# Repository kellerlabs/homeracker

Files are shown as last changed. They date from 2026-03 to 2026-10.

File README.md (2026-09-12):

[📚 What's it for?](#-use-cases) | [⚙️ How does it work?](#-features) | [🌐 Free & OpenSource](#-open-specs) | [🤝 Contributing](CONTRIBUTING.md)

What is HomeRacker - YouTube video (https://youtu.be/g8k6X_axYug)

HomeRacker is a fully modular 3D-printable rack-building system for virtually any “racking needs” (server rack, shoe rack, bookshelf, you name it).

You can find all parametric and non-parametric models, as well as the `.f3d` files (like the `HomeRacker - Core`), on [Makerworld](https://makerworld.com/en/@kellerlab).

The parametric models are available in the [HomeRacker GitHub Repository](https://github.com/kellerlabs/homeracker/tree/main/models).

> 💡 **Note**
> The basic HomeRacker system is also referred to as `HomeRacker - Core`. Free for everyone to use, remix, and reshare.

# 📑 Table of Contents
- [🔧 Use Cases](#-use-cases)
- [✨ Features](#-features)
  - [⚙️ How it works](#%EF%B8%8F-how-it-works)
    - [🛠️ Assembly Basics](#%EF%B8%8F-assembly-basics)
    - [💡 Assembly Tips](#-assembly-tips)
    - [🖨️ Printing Tips](#%EF%B8%8F-printing-tips)
- [📐 Tech Specs](#-tech-specs)
  - [🧱 Supports](#-supports)
  - [🔗 Connectors](#-connectors)
  - [📏 Lock Pins](#-lock-pins)
  - [🌍 Open Specs](#-open-specs)
- [💬 Community](#-community)
- [❓ Why the name?](#-why-the-name)
- [📜 Licensing](#-licensing)
- [🤝 Contributing](CONTRIBUTING.md)
- [🛠️ Developer Tools](#%EF%B8%8F-developer-tools)
- [🚀 Releases](#-releases)
- [🧪 Tests](#-tests)
  - [⚠️ Disclaimer](#%EF%B8%8F-disclaimer)
  - [🔬 How I tested](#-how-i-tested)
- [🏷️ Logo](#%EF%B8%8F-logo)

# 🔧 Use Cases
I created HomeRacker because I was dissatisfied with the existing solutions available online. Many designs were too specific, accommodating only certain devices owned by their creators. Others supported only the 10" standard, with no flexibility for deviations, often requiring additional adapters.

As I began my homelab journey in April 2025, I wanted a modular solution that could adapt and grow with my evolving needs. This would eliminate the need to purchase larger racks or completely change concepts when the original design no longer met my requirements.

xkcd: The General Problem

As it is my nature to overengineer everything, I came up with a more generic solution to serve ANY racking need. Be it a small rack for a few Raspberry Pis, a 10" standard rack for homelabs, or even a 19" standard rack (still working on that though). You can even create bookshelves, shoe racks, or combine all of the above into an abomination of a rack.

To give you an idea of how this may look (10" rack, half-constructed Pi mini-rack, bookshelf):

Real Life Example

Aside from the basic [building blocks](#-tech-specs), the rack above also contains the following parts:

* **10" Rack**
  * [HomeRacker - 10" Rackmount Kit](https://makerworld.com/en/models/1353730-modular-10-server-rack#profileId-1396904) for standard-height units
  * [Raspi 5 Mount Kit](https://makerworld.com/en/models/1324096-pi-5-snapcase-for-homeracker#profileId-1360937):
    * Vertical Mount Adapter for HomeRacker
    * Front panel for 10" racks
  * Rackmount ears for the switch. These are fully customizable rackmount ears I created as an [OpenSCAD file](https://github.com/kellerlabs/homeracker/blob/main/models/rackmount_ears/parts/rackmount_ears.scad). You can customize it directly [here](https://makerworld.com/en/models/1259227-fully-customizable-rackmount-ears#profileId-1283271).
  * [HomeRacker Airflow Kit](https://makerworld.com/en/models/1353730-modular-10-server-rack#profileId-1396904) (currently part of the 10" rack model), which consists of:
    * Front/back panels
    * Side panels
    * Bottom/top panels with air intake/exhaust grids and bores for standard fans (80/92/120mm)

* **Shelf** (Build any shelf configuration you like.)

# ✨ Features

The `HomeRacker - Core` features:

* **Fully modular**: Thanks to the support-connector system, you can scale in any direction. The only limits are material strength and how much money, space, and time you have.
* **3D-printable**: The entire core system is printable, and no tools are required for assembly.
* **No supports needed**: Not a single part of the core system needs printed supports.
* **OpenSource**: Build your own adapters and use the system in personal or commercial projects (see [🌍 Open Specs](#-open-specs) and [📜 Licensing](#-licensing) for details).

## ⚙️ How it works
> **tl;dr** Think of a rack shape you want to build, download the [Core model on MakerWorld](https://makerworld.com/en/models/1317298-homeracker-core) (or customize it there or from [this repo](models/core/)), print it, assemble it, and add your own mounts/adapters/whatever-you-like.

I might post a YouTube video here to show how it works.

### 🛠️ Assembly Basics

Assembly Basics 4 White

Assembly is straightforward and requires no tools:

1. **Prepare the components**: Download the [HomeRacker - Core](https://makerworld.com/en/models/1317298-homeracker-core) (or customize it on MakerWorld / from [this repo](models/core/)), and print all required parts. Clean off any debris.
2. **Connect supports and connectors**: Attach connectors to supports based on your desired configuration.
3. **Secure with Lock Pins**: Use Lock Pins to lock parts in place. They can be inserted horizontally or vertically thanks to their square profile.
4. **Add features**: Attach panels, shelves, and other accessories as needed.

### 💡 Assembly Tips

> 💡 **Pro Tip**: I created a sample [10" Cyberpunk-themed 3D model on MakerWorld](https://makerworld.com/en/models/1353730-modular-10-server-rack#profileId-1396904) for inspiration.

1. Plan ahead! Otherwise, you'll end up with an army of unused parts like me:

   Army of Parts

   Make a parts list, or let the [Configurator](https://homeracker.org/configurator/) count for you:
   * How many supports of what lengths (in `base units`)?
   * How many connectors of each type (pull-throughs, feet, regular)?
   * Print a ton of Lock Pins. You'll need more than you might think. The [Core model](https://makerworld.com/en/models/1317298-homeracker-core) on MakerWorld includes a 100-pin plate and a [Gridfinity](https://gridfinity.xyz/) box for storage.

2. Build layer by layer: Start with the base frame, add vertical supports, then stack intermediate/top frames.
3. Make sure Lock Pins are fully inserted. Gentle force might be needed.

### 🖨️ Printing Tips

1. If bed adhesion is sketchy: Add a brim to the supports. The small contact surface on connectors can cause print failures.
2. Prevent warping: Keep the print bed clean and oil-free. Even a fingerprint can cause issues.
3. When printing new filament: Make sure to calibrate the material flow!
> 💡 **Pro Tip**: If you need to disassemble and the pin is stuck, push it from the other side with another pin to release it.

## 📐 Tech Specs

> 💡 **Note** - For actual dimensions, check out the original Fusion `.f3d` files on Makerworld. All designs are fully parameterized for easy scaling.

The system is based on 4 core measurements:

1. **15mm**: The `base_unit`. Each support has 15mm x/y dimensions, with z being a multiple of 15mm.
2. **4mm**: Side length of Lock Pins and matching holes.
3. **2mm**: Wall thickness of connectors.
4. **0.2mm**: Tolerance added to connector interiors for print/material variances.

> These values (except tolerance) are arbitrary and just made sense during design.

### 🧱 Supports

Supports are the structural spine of HomeRacker.

Core Support 3D Transparent

Height is a multiple of 15mm (base units). E.g.: A 3-unit support = 45mm tall, a 17-unit = 255mm.

Each unit height includes a 4mm hole for a Lock Pin.

* Holes match Lock Pin dimensions (no tolerance).
* Holes are convex on x and z axes for multi-directional insertion.

Schematics:

**Front View**
Support Front View

**Side View**
Support Side View

**Top View**
Support Top View

### 🔗 Connectors

Connectors join supports in 1 to 3 dimensions. From straight extenders to 6-way junctions.

3D Shot of All Connectors

Types:
* **Standard**: Solid center; best for load-bearing.
* **Pull-Through**: Open center for complex builds (e.g. 10" rack).
* **Feet**: Solid end pieces; used as rack feet.

> ❗ **Important**
> Connector centers are always 1 `base_unit` in height. No offsets, no fluff.
> So: 2 × 3-unit supports + 1 connector = exactly 7 base units (105mm).

Schematics:

**Top View, Outer**
Connector Outer Measurements

**Top View, Inner**
Connector Inner Measurements

### 📏 Lock Pins

Lock Pins hold the system together.

Lock Pin 3D

They rely on tension from their convex shape to stay in place.

Schematics:

**Top View**
Lock Pin Top

**Side View**
> Don't ask why the height is 3.791mm, it works. I left it as-is.

Lock Pin Side

> I may tweak the pin grip in future versions to make it easier to pull out again. But the base dimensions will remain the same for compatibility.

> 💡 **Tip**: Pulling out Lock Pins one at a time can be tedious. Check out the [Pinpusher](models/pinpusher/), a tool designed to push Lock Pins back out quickly, especially when removing several at once.

## 🌍 Open Specs

I created `HomeRacker - Core` to be an open spec that any maker can build on, with (almost) no strings attached. (See [📜 Licensing](#-licensing) for more.)

I encourage you to make your own models based on HomeRacker! Let me know, and I’ll feature your work on this page and cross-link it on Makerworld (subject to my "very objective" approval 😄). Just [create an issue](https://github.com/kellerlabs/homeracker/issues/new) if you want to be featured.

> 💡 **Want to contribute new features or extensions?**
> Head over to the [HomeRacker Community Repository](https://github.com/kellerlabs/homeracker-community)!
> This core repo focuses on the base system and accepts primarily bugfixes. New modules, adapters, and creative extensions live in the community repo.

# 💬 Community

Got questions? Want to share your builds? Join the HomeRacker community!

- **🐙 [Community Repo](https://github.com/kellerlabs/homeracker-community)**: Contribute new features, extensions, and modules
- **💬 [Discord](https://discord.gg/b6myzHRxc3)**: Chat with me and other builders, get help, share ideas
- **🎥 [YouTube](https://www.youtube.com/@kellerlabs)**: Watch build guides, tutorials, and project updates
- **🖨️ [Makerworld](https://makerworld.com/@kellerlab)**: Grab ready-to-print models and remixes

Whether you're just starting out or have a wild idea for a custom rack, I'd love to hear from you. The HomeRacker community is all about sharing knowledge and helping each other build cool stuff!

# ❓ Why the name?

After ~4 hours of research, I found all my original ideas (UniRack, OpenRack, etc.) were taken.

So, "HomeRacker" was born, part practical, part tongue-in-cheek. It fits the homelab theme, but also hints at the "home-wrecking" time sink this can become.

# 📜 Licensing

> 💡 **tl;dr**
> Use it for ANY purpose (even commercial), but credit me and share alike!

* Source code: `MIT License` ([LICENSE](https://github.com/kellerlabs/homeracker/blob/main/LICENSE))
* 3D models & creative assets (`/models/`): `CC BY-SA 4.0 License` ([/models/LICENSE](https://github.com/kellerlabs/homeracker/blob/main/models/LICENSE))

These licenses apply to all models in this repository (Core, Gridfinity, Rackmount Ears, Wall Mount, Pinpusher, etc.).

> ❗ **Important**
> Other models I publish may have more restrictive licenses. This will be stated clearly on Makerworld.

HomeRacker is an unregistered trademark of Patrick Pötz, first used publicly on 12.04.2025.

# 🛠️ Developer Tools

HomeRacker includes custom tooling to streamline development:

- **[scadm](cmd/scadm/README.md)** - OpenSCAD + library dependency manager
  - Zero-dependency Python package for installing OpenSCAD (nightly/stable) and libraries
  - Cross-platform: Windows, Linux, macOS (might work, dunno)
  - Install: `pip install scadm` → `scadm`
  - Manages dependencies from `scadm.json`

- **[Setup OpenSCAD Action](.github/actions/setup-openscad/README.md)** - Reusable GitHub Action for CI
  - Installs OpenSCAD, system dependencies, and libraries in one step
  - Uses scadm under the hood, with caching for fast runs
  - Usage: `uses: kellerlabs/homeracker/.github/actions/setup-openscad@setup-openscad-v1`

- **[Style Guide](docs/styleguide.md)** - colours from `constants.scad`, Orbitron Black + Source Code Pro, layout rules

- **[Site](site/README.md)** - homeracker.org, built by Astro from the READMEs in this repo
  - Home page, model catalog and model pages come straight from `README.md` and `models/*/README.md`
  - Relative links and render images are resolved at build time

- **[Configurator](configurator/README.md)** - Web-based rack planner with parts list
  - Define a rack, preview it, copy the bill of materials
  - Live at [homeracker.org/configurator](https://homeracker.org/configurator/)

- **[Renovate Preset](renovate-dependencies.json)** - Automated dependency updates
  - Tracks OpenSCAD versions, GitHub releases, and Python packages
  - Custom rules for this project's specific needs
  - Extend in your project: `"extends": ["github>kellerlabs/homeracker:renovate-dependencies"]`

See [CONTRIBUTING.md](CONTRIBUTING.md) for setup instructions.

# 🚀 Releases

Releases are fully automated:

- **Automated versioning**: Follows [Semantic Versioning](https://semver.org/) based on [Conventional Commits](https://www.conventionalcommits.org/)
- **Changelog generation**: Automatically generated from commit messages
- **Release schedule**: Weekly auto-merge of release PRs (Mondays) or manual trigger
- **GitHub releases**: Tagged releases with changelog and version information
- **PR validation**: Pull request titles are validated to ensure Conventional Commits compliance

The release automation is powered by [Camunda's infra-global-github-actions](https://github.com/camunda/infra-global-github-actions/tree/main/teams/infra/pull-request).

To contribute and trigger releases, use conventional commit messages. See [CONTRIBUTING.md](CONTRIBUTING.md#-commit-conventions) for details.

# 🧪 Tests

Of course I tested stuff... It took ~4 months from idea to this release. Look at all the prototypes:
Photo showing a variety of HomeRacker prototypes lined up

## ⚠️ Disclaimer

> ⚠️ **Warning**
> This project is provided “as is,” without any warranty. Use at your own risk. I’m not responsible for damage, injury, or loss caused by using this system or its parts.

Aside from the scary warning above, I need to mention, that due to the high modularity of this system combined with limited time and resources I was of course not able to test every combination of filaments, printers, print-settings, room conditions (temperature, humidity) or to do extensive load-bearing tests.

What I want to say: I feel like the model turned out to be really nice and versatile. That's why I shared it in the first place. But since I do not have control over the manufacturing conditions of any consumer of this model, I cannot give any guarantees on how your specific print will turn out in the end. There are just too much variables which not even the best model design can compensate for. (Writing this feels a bit like an upfront apology... seems like I'm a people pleaser)

## 🔬 How I tested
My setup is as follows:
* a room temperature between 17 and 25°C
* Humidity levels between 29% and 36% (depends on when I'm doing my laundry)
* A BambuLab X1C printer
* Exclusively BambuLab filament (haven't tried others yet)
  * PLA Matte (I love the charcoal color. Looks so silky)
  * PLA Basic
  * ABS
* mostly I used the Textured PEI plate. It just works (provided you regularly clean it using Isopropyl alcohol). For the rest of the time I tried out the Cold Plate Super Track (it's nice but very hard to get your prints off the plates when it cools)

All above's filament types can be be combined in any possible way (just make sure you do flow calibration before using new filaments. First ABS print turned out horribly just because I forgot to click the calibration checkbox). E.g.: you could print a connector in ABS, a support in PLA Matte and a Lock Pin in PLA and they will just fit when being assembled.

> 🛠️ **Btw:** I am not affiliated with Bambu in any way besides uploading my models to MakerWorld and occasionally making use of their Exclusive Model program. But they don't pay me for naming their products anywhere else (I wish 😉).

# 🏷️ Logo
This logo will also be used as an overlay image for the thumbnails of all my 3D models that are compatible with HomeRacker. I encourage you to do the same if you create models for HomeRacker. That way, it’ll be immediately visible to users that a model is designed to be mounted on a HomeRacker system. I also svg'ed this logo [here](https://raw.githubusercontent.com/kellerlabs/assets/main/homeracker/img/homeracker_logo.svg) and [here](https://raw.githubusercontent.com/kellerlabs/assets/main/homeracker/img/homeracker_logo_single_color.svg).

HomeRacker Logo

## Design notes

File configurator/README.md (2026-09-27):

# 🧮 Configurator

## 📌 What

Browser-only rack configurator published at <https://homeracker.org/configurator/>. Define a rack as a stack of rows (each with an optional name, its own height, column widths and whether its posts continue from the row below), set depth and feet, close individual openings with panels (in to-scale face drawings or by clicking them in the 3D view), preview it, and get the parts list to print. The config lives in the URL hash, so a link is a saved rack; the Copy link button puts it on the clipboard. A printer section holds your print volume (default 256 mm cubed, kept in the browser, not in the link); parts that do not fit it are marked in the parts list and drawn red in the 3D view, without blocking anything else.

## 🤔 Why

The README's first assembly tip is "make a parts list". This does the counting, and it encodes the geometry rules once, next to the models they mirror.

## 🔧 How

```sh
cd configurator
npm ci
npm run dev      # local dev server
npm run check    # eslint + tsc + vitest
npm run build    # static bundle in dist/, served under /configurator/
```

### Structure

| Path | Purpose |
|---|---|
| `src/engine/` | Pure geometry + parts list. No DOM, no Three.js (enforced by `tsconfig.engine.json` and eslint) |
| `src/engine/orientation.ts` | Finds which of the 24 cube rotations maps a canonical connector mesh onto a node (pure, tested) |
| `src/engine/pins.ts` | Lock pins of the frame: which hole of the support a pin follows, which side it goes in from, and where a panel corner bracket makes it an extended one (pure, tested) |
| `src/engine/printer.ts` | Print bed check: every parts-list line carries the bounding box of one part in mm; `unprintable()` lists the lines that fit no axis-aligned orientation of the bed |
| `src/render/` | `meshes.ts` draws real part meshes from the exported library (connectors per type and pull-through axis, supports per length, lock pins, feet); `layout.ts` + `build.ts` are the schematic box fallback; `scene.ts` picks one; `viewcube.ts` + `viewcubeGeometry.ts` (both pure and tested) + `viewcubeGizmo.ts` are the orientation cube |
| `src/app.ts` | `mountConfigurator(root)`: builds the controls, stage and parts list inside any element |
| `src/configurator.css` | Component styles; reads the site design tokens, falls back to matching values standalone |
| `src/engine/diagrams.ts` | To-scale elevations and plans of every face and frame for the panel drawings (pure, tested) |
| `src/ui/` | Row editor (height, shift, column widths with negative widths for gaps, posts continue from below), panel drawings (click a rectangle to cycle open, inter-fit, full cover; one figure per face plus one per gap; the three squares next to a drawing set all of its openings; hover syncs with the 3D view), parts-list table, URL hash sync |
| `tests/` | Vitest; `fixtures.ts` holds the worked examples. Browser journeys live in [`site/e2e/`](../site/e2e/), see [TESTING.md](../TESTING.md#site-and-configurator-e2e-tests) |

### Geometry rules

- 1 unit = 15 mm (`BASE_UNIT`). Connector cores are 1 unit; a support between nodes `a < b` has length `b - a - 1`.
- A rack is a stack of rows, bottom to top. Each row has a height (its vertical support length), a list of column widths (bay support lengths, left to right; each divider between bays is one unit of connector core), a shift (units to the right of x = 0) and a `through` flag: when set, the posts of the row below continue through the frame under this row (pull-through connectors there, one long support) instead of ending in a standard connector. Depth is shared.
- A column width may be written negative: that is a **gap**, taking the same space as a bay of that width but carrying no beam above it. It is what builds a U, a row of `6, 10, 6` under a row of `6, -10, 6` gives two towers with the space between them open to the top. The posts on both flanks of a gap stand as they would for a bay, and a beam under a gap survives when a bay of the row below spans the same place. The beam above a gap never comes back: stacking another row on the U leaves the gap open and that row keeps its own top beam, so a gap cannot be bridged from above. A gap has no bay, so no front or back panel; the walls it exposes become the left and right openings of the row's segments (the runs of bays on either side), drawn in their own `Gap in <row>` figure. Because those openings are indexed by segment ordinal, editing a gap into an existing row can move a left or right panel to a different wall (a saved link has no gap, so its indices never shift under it). A gap may sit anywhere in a row, including at either end, where it takes away the beam above its own columns and nothing else; a gap at the end exposes one wall rather than a facing pair, so it gets no figure of its own and that wall shows in the side elevation instead. A rack whose parts end up joined by nothing, a U standing on the floor, with no row spanning under its gap, is reported under the rows, without blocking anything else.
- Frames sit between rows and get a connector at every column boundary of the row below and the row above; beams are split there, so a divider that stops ends in a T connector. Vertical posts run at every column boundary of their own row. Rows can differ in width and position (stepped racks).
- Two connectors need at least 2 units of support between them, because each connector arm wraps one unit of the support. Depth, row heights and column widths are therefore 2..50, and a frame beam shorter than 2 units (dividers of neighbouring rows landing 2 units apart) is reported under the rows, drawn red in the 3D view and marked in the parts list, without blocking the rack.
- Outer size is the widest row by `depth + 2` by the sum of `height + 1` over rows, plus 1.
- Connector type = (axes used, arm count) as in `CONNECTOR_CONFIGS`. A through junction makes its nodes z pull-through.
- Supports carry lock pin holes on both axes (`x_holes=true`), because a panel bracket needs the hole across the face it lies on, and the parts list asks for them that way. See [x-hole supports by default](../docs/decisions/x-hole-supports-by-default.md).
- One lock pin per occupied arm, the floor arms included: a foot plugs into its arm like a support and is locked the same way. A pin is pushed in from the inside of the rack, so the grip stays clear of panels, and runs vertically through a beam and front to back through a post unless a panel corner bracket wants the other hole of that cell. The two holes of a cell cross in its middle, so only one of them can take a pin: it goes to the axis that holds the most brackets, which leaves the odd corner where a front and a side panel meet pinned for one of the two. A pin whose hole carries a bracket is an extended one: the neck when the bracket is on the side the pin goes in from, the tail when it is on the far side, both when a panel hangs on either side (`src/engine/pins.ts`).
- Panels close openings. Every row has front and back openings per column and one left and one right opening per segment; every frame (bottom, each shelf between rows, top) has one horizontal opening per span between its nodes, so exposed roofs of a wider lower row and shelves inside the rack can be panelled too. A panel fills its opening exactly: `units_x = support length` (from the inter-fit deduction in `panel.scad`). Openings need at least 2 units per side to take a panel (the model asserts that); the upper bound is the support length. A front or back bay whose top or bottom edge carries a connector between its corners (the divider of a neighbouring row ending in a T there) cannot take a standard panel either: the panel model runs its mount plates and contour walls along the whole edge, and a connector core stands 2.1 mm proud of the support into that space. Such openings are hatched in the drawings and skipped by the whole-face shortcuts. A panel that still lands on an opening no standard part fits (from an older link, or after a row was resized) never blocks the rack: it is drawn in the warning colour in the drawing, the parts list and the 3D view, and a click on it removes it. Panels beyond the Customizer slider range of 16 units get a note in the parts list: type the units into the Customizer or print them split. Panel lock pins are an estimate, one per mount plate hole, and are listed separately; the corners are held by the frame pins that carry the extension for it.
- URL hash: `v=4&d=<depth>&r=<height>:<w>.<w>[~shift][*]_<row>...&f=<feet>&pn=<f|b|l|r|h><at>.<index><i|f>_...&n<row>=<name>` where a negative `<w>` is a gap, `*` marks a row whose posts continue from below, `at` is the row index (vertical faces) or frame index (horizontal), and `n0`, `n1`, ... carry optional row names (up to 40 characters). Version 3 links (one post mode for the whole rack), version 2 links (one panel type per face) and version 1 links (single column, level positions) still open.

### Preview

An orientation cube sits in the top right corner of the stage, the way CAD software shows one. It turns with the model so the face you are looking at is always named, using the same names as the face drawings: `FRONT` is -y, `RIGHT` is +x, `TOP` is +z. Its corners are chamfered off, so it is fourteen real facets: six labelled octagons and eight corner triangles, one per view it offers. That makes the corners visible as targets from any angle, including head on to a face, and it makes the hit test exact, the ray reports the facet it struck, with no guessing from how close to an edge it landed. Hovering lights that one facet, and clicking swings the camera to its view, keeping the current target and distance, so a corner gives the usual 3/4 isometric. The top and bottom views are tipped a hair towards the front, because looking exactly down the up axis leaves an orbit camera's azimuth undefined. The cube is drawn in a scissored corner of the same WebGL canvas, so it costs no second context and cannot drift out of step with the camera.

The 3D preview uses the part meshes exported by `site/scripts/export-parts.mjs` (served under `/parts/`; the standalone app serves `../site/public` too). Every connector is placed with the rotation from `orientation.ts`, lock pins sit in every occupied arm the way the geometry rules describe, feet plug into the floor arms. Panels are parametric in two dimensions, so each one is assembled the way `panel()` in `panel.scad` assembles it: a plate (inter-fit turned around, lying against the inside of the frame with its mounts reaching back out to the plane of the opening; full cover overlapping the supports by half a unit and standing one connector wall proud of them so it covers the connectors) plus real exported meshes of the support mount plate for that edge length and the corner bracket, placed with the same spins as the OpenSCAD module. The kit is exported from `site/scripts/scad/panel_kit.scad`. Without the mesh library the preview falls back to schematic boxes.

Worked example (defaults): depth 6, rows 5 and 4 high with one 6-unit column, feet on, segmented posts gives 12 x 6u + 4 x 5u + 4 x 4u supports, 8 x 3D4W + 4 x 3D3W connectors, 44 lock pins, 4 feet. Splitting the bottom row into two 4-unit columns adds a post, two T connectors (3D5W and 3D4W) and two feet.

> ⚠️ The panel sizing rule is derived from the library source, not yet verified on a print. If a panel is off by one unit, fix `panelSize()` in `src/engine/panels.ts` and its test.

### Deploy

The [site](../site/README.md) mounts this app on its `/configurator/` page by importing `src/app.ts` and `src/configurator.css` directly, so the deployed configurator shares the site's navigation, fonts and colours. `npm run build` here still produces a standalone bundle for local use; `index.html` is that shell.

## 📚 References

- [web-configurator-on-github-pages](../docs/decisions/web-configurator-on-github-pages.md): decision record
- [HomeRacker core](../models/core/README.md): supports, connectors, lock pins
- [Panels](../models/panel/README.md), [Feet](../models/foot/README.md)

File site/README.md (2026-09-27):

# 🌐 Site

## 📌 What

The homeracker.org website: an Astro static site that renders the repository's own markdown (the root `README.md`, `models/README.md`, and every `models/*/README.md`) into a themed site, with the [configurator](../configurator/README.md) mounted at `/configurator/`.

## 🤔 Why

The README stays the single source of truth. The site adds navigation, a model catalog with the tracked render PNGs, a live preview of the system on the home page, and a visual identity built from HomeRacker's own constants: the 15 mm unit as a lattice, the brand yellow as the one accent.

## 🔧 How

```sh
cd site
npm ci
npm run dev      # local dev server with live reload
npm run check    # astro check + vitest
npm run build    # static site in dist/
npm run e2e      # Playwright against dist/, see TESTING.md
```

`npm run build` first runs `scripts/export-parts.mjs`, which needs OpenSCAD (`scadm install` puts it in `bin/openscad/`, or set `OPENSCAD`). Without it the script warns, the build continues, and the hero shows the schematic rack instead. CI sets `PARTS_REQUIRED=1` so a missing OpenSCAD fails the build there.

Astro caches rendered markdown in `.astro/`. After changing the rehype transforms in `src/lib/`, run `npx astro build --force` so cached README renders are regenerated.

### Structure

| Path | Purpose |
|---|---|
| `src/content.config.ts` | Content collections: `docs` (root + models index) and `models` (one entry per `models/*/README.md`) |
| `src/lib/links.ts` | Rewrites relative markdown links to site routes, or to GitHub when the site has no page for the target |
| `src/lib/sections.ts` | Wraps each heading block in a `<section>` so the theme can lay out README sections; drops the GitHub table of contents |
| `src/lib/catalog.ts` | Builds catalog cards from `models/README.md` |
| `src/lib/hero.ts` | Home page hero: the exploded 3D3W cube (8 connectors, 12 supports, 24 lock pins) built from real part meshes, assembling and coming apart in a loop; still exploded view under reduced motion |
| `src/lib/rack.ts` | Fallback hero when no part meshes are present: the default configurator rack as schematic boxes |
| `scripts/e2e-report.mjs` | Turns the Playwright JSON results into the job summary and the PR comment on E2E failures |
| `scripts/export-parts.mjs` | Exports the part library with OpenSCAD into `public/parts/` (gitignored): every connector type and pull-through variant, supports from 1 to 50 units, the lock pin, the foot, and the panel kit (support mount plates for 3 to 50 units and corner brackets, both panel types) from `scripts/scad/panel_kit.scad`. Used by the hero and by the configurator preview |
| `src/pages/` | `index.astro` (README), `models/index.astro` (catalog), `models/[slug].astro` (model pages), `configurator.astro` (mounts the configurator app) |
| `e2e/` | Playwright suite: page smoke tests, configurator journeys, and the control inventory. See [e2e.md](../.claude/rules/e2e.md) |
| `src/styles/global.css` | Design tokens, the type system from [docs/styleguide.md](../docs/styleguide.md) (Orbitron Black for headings, Source Code Pro for everything else) and markdown styling |

### Writing docs that render well

- Relative links between READMEs (`../core/README.md`, `models/panel/README.md`) become site links automatically. Links to anything else in the repo go to GitHub.
- Relative images under `parts/renders/` are optimized by Astro at build time. Images from `kellerlabs/assets` are loaded as-is.
- Model pages take their table of contents from the `##` headings.

### Deploy

`.github/workflows/pages.yml` installs both packages, builds this site (which bundles the configurator page), and deploys `site/dist` with `actions/deploy-pages`. The repository's Pages source must be set to **GitHub Actions**; the custom domain comes from `public/CNAME`.

## 📚 References

- [astro-site-replaces-jekyll](../docs/decisions/astro-site-replaces-jekyll.md): decision record
- [web-configurator-on-github-pages](../docs/decisions/web-configurator-on-github-pages.md)
- [e2e-test-site-and-configurator-with-playwright](../docs/decisions/e2e-test-site-and-configurator-with-playwright.md)
- [Astro content collections](https://docs.astro.build/en/guides/content-collections/)

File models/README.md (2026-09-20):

# 📦 Models

This folder contains all `scad` 3D models which come with the HomeRacker project.

## 📑 Contents

### 🧱 Core

The fundamental HomeRacker building system with modular components:

- **Supports**: Vertical and horizontal structural elements
- **Connectors**: Join supports in a variety of dimensions
- **Lock Pins**: Secure connections without tools

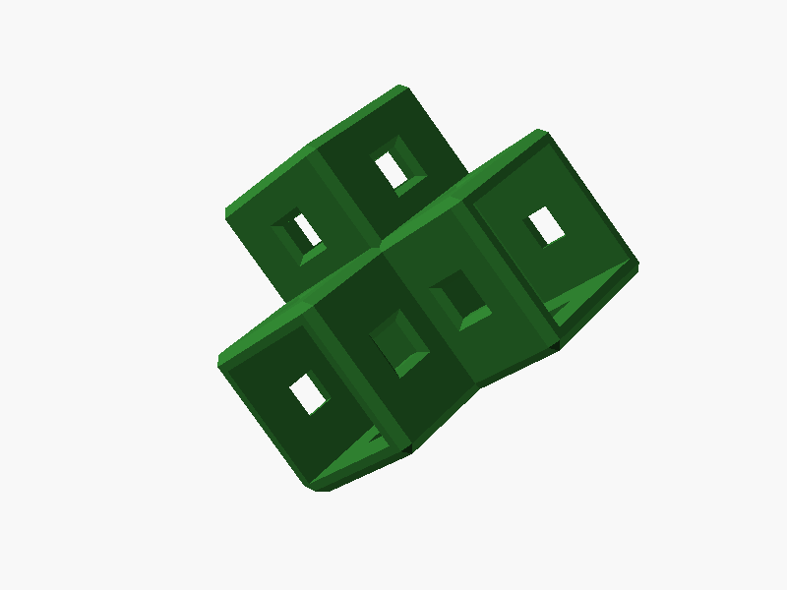
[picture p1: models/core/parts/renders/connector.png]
Connector


See [core/README.md](core/README.md) for details.

### 📐 Gridfinity

Gridfinity-compatible components for modular storage integration:

- **Baseplates**: Mounting surfaces for Gridfinity bins (42mm grid)
- **Bin Bases**: Foundation for custom Gridfinity-compatible containers

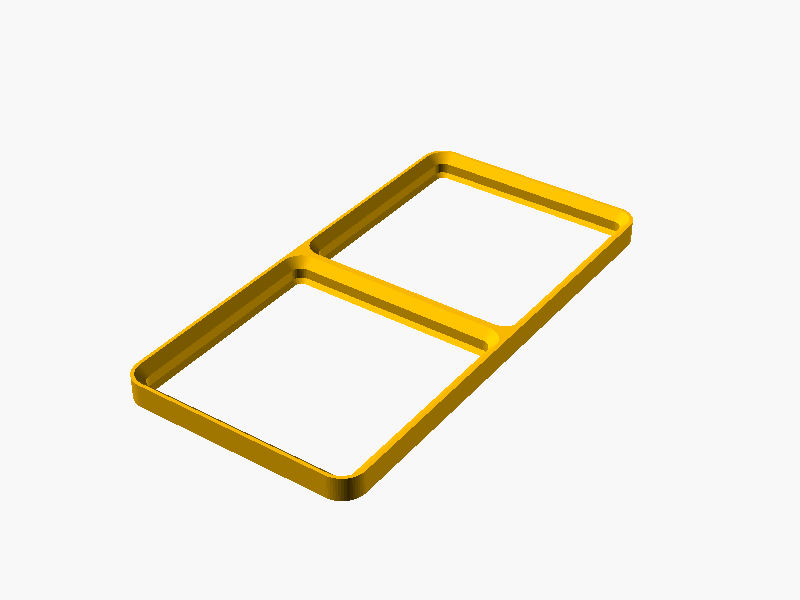
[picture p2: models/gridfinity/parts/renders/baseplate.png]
Baseplate


See [gridfinity/README.md](gridfinity/README.md) for details.

### 🔩 Rackmount Ears

Fully customizable rackmount ears for standard 10" and 19" rack mounting.

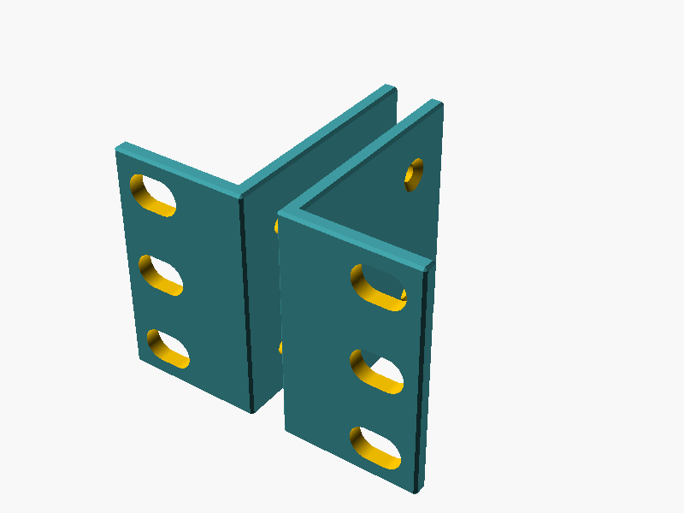
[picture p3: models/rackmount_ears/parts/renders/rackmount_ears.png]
Rackmount Ears


See [rackmount_ears/README.md](rackmount_ears/README.md) for details.

### 🧲 Wall Mount

Wall-mountable bracket for attaching HomeRacker supports to vertical surfaces.

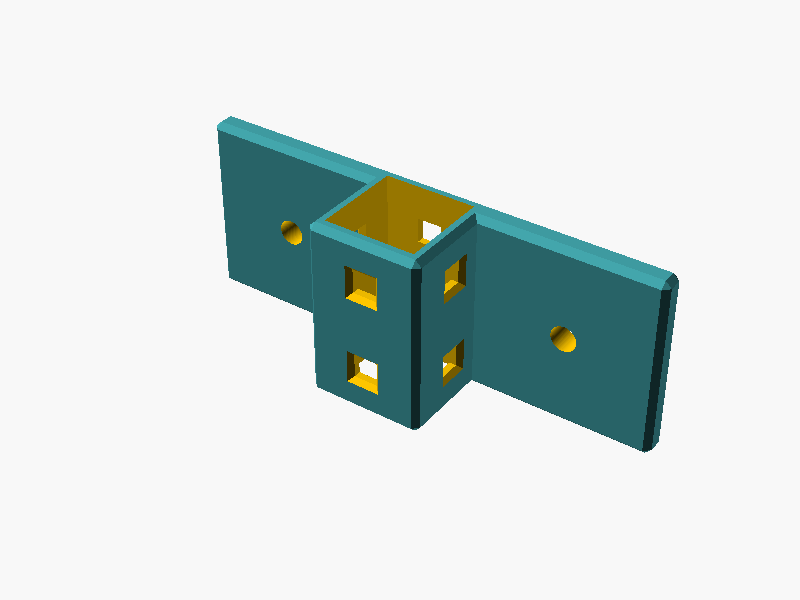
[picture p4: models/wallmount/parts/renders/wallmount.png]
Wall Mount


See [wallmount/README.md](wallmount/README.md) for details.

### 🔗 Racklink

Connects independent rack columns together via double U-shaped sleeves for better stability and a clean look. Build small columns, join them later.

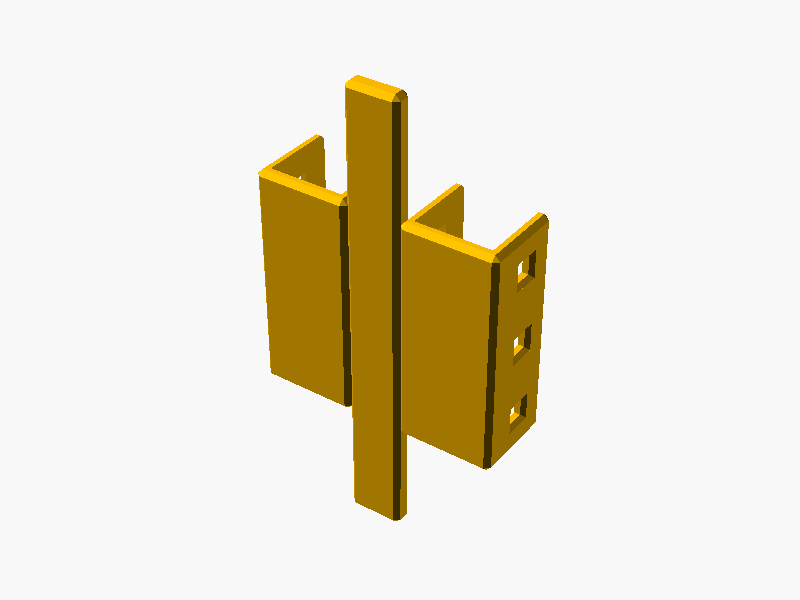
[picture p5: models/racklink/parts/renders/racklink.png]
Racklink


See [racklink/README.md](racklink/README.md) for details.

### 🖼️ Panel

Plain mounting panel that fits into the HomeRacker scaffold. Use as-is for blank panels or as a base for custom cutouts (keystone jacks, switches, etc.). Supports Inter-Fit (inset) and Full Cover (overlap) integration types. Includes a standard 10"/19" rack panel variant with configurable bore patterns, an optional back-side truss stiffener, and an optional split mode (hinge connector + lock pin) for printing wide panels in halves.

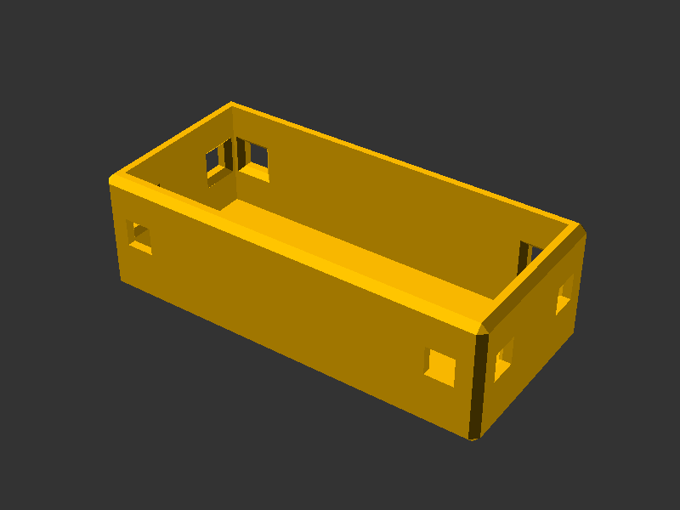
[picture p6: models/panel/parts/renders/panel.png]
Panel


See [panel/README.md](panel/README.md) for details.

### 🔌 Keystone

Parametric keystone jack socket module for integrating standard keystone connectors into virtually any panels (using BOSL2 `diff("keystone")`). Supports 4 rotation angles and includes snap-fit label plate slots for port identification, mountable above or below the jack.

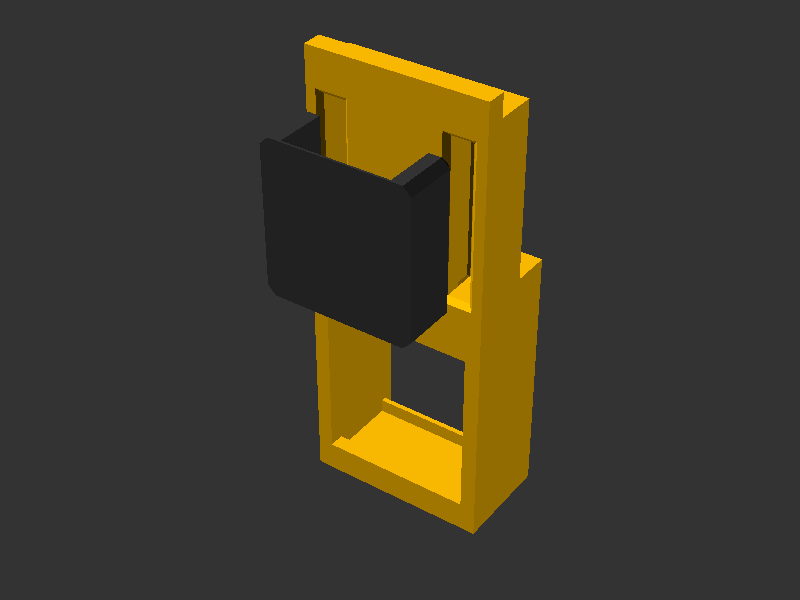
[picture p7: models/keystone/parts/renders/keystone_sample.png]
Keystone Sample


See [keystone/README.md](keystone/README.md) for details.

### 🦶 Foot

Modular foot insert that plugs into any connector arm used as contact surface at the bottom of a rack. Decoupled from the connector for maximum flexibility, print in TPU for better grip and load distribution.

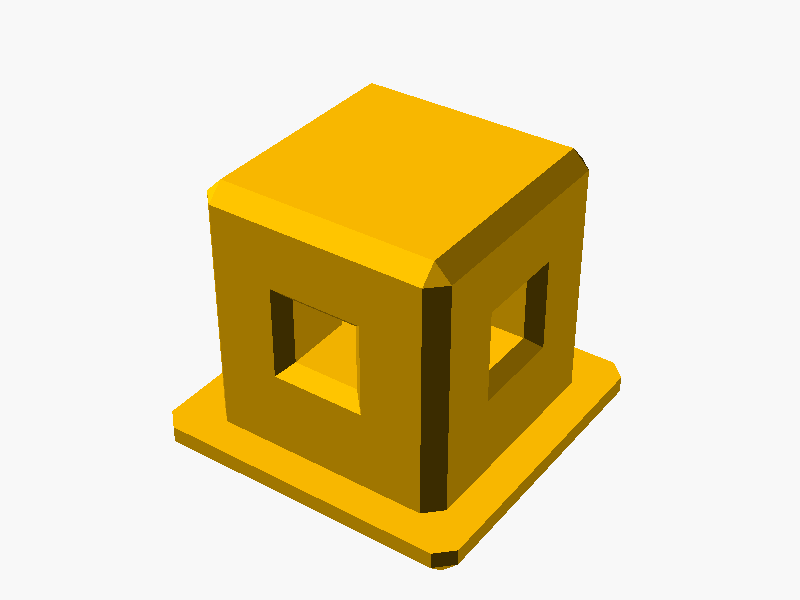
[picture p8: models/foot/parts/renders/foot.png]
Foot


See [foot/README.md](foot/README.md) for details.

### 🗜️ Bracket

Clamp that wraps a device from above/below and hangs it in the frame via lock pins. Mount wings on both flanks absorb whatever the device width misses on the 15mm grid, so the lock pins always land on the right position on a support. Nothing sits below/above the device, keeping airflow and cabling clear.

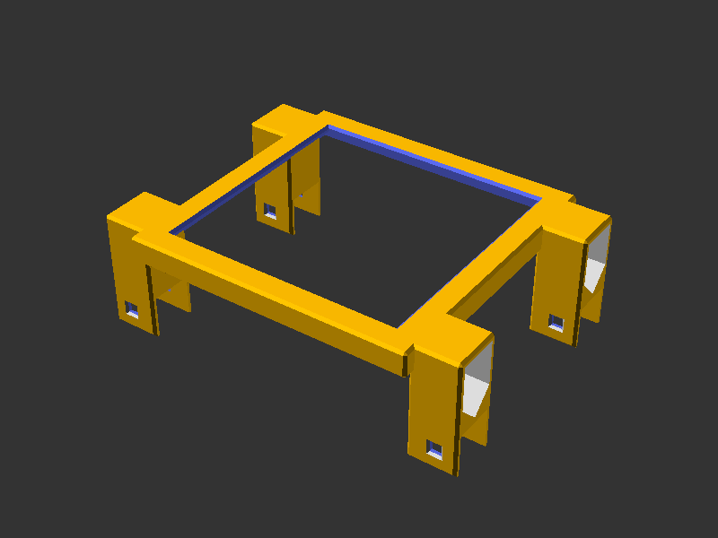
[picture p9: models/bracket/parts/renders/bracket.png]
Bracket


See [bracket/README.md](bracket/README.md) for details.

### 🧤 Sleeve

A 3-sided U-shaped sleeve that wraps around a vertical HomeRacker support. Reusable attachment primitive with lock pin holes on both sides.

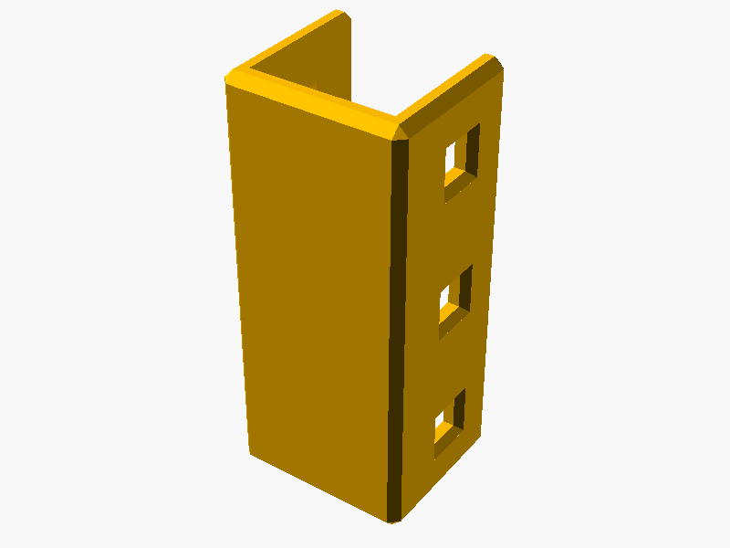
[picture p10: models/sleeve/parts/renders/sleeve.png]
Sleeve


See [sleeve/README.md](sleeve/README.md) for details.

### 📌 Pinpusher

A utility tool for removing lock pins from connectors.

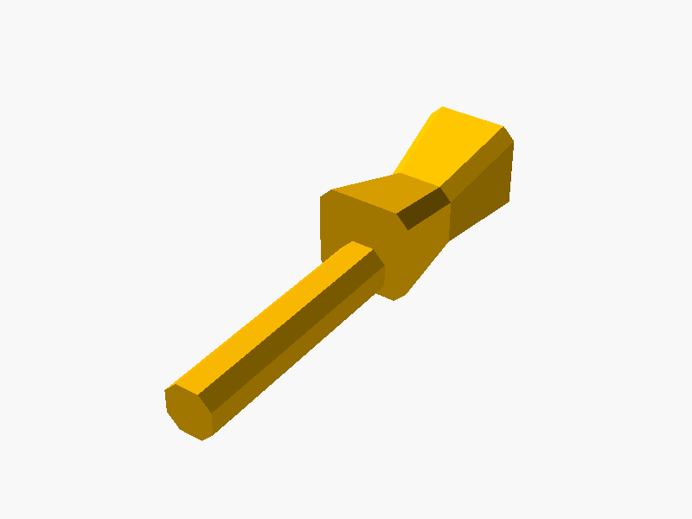
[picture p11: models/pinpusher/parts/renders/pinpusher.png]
Pinpusher


See [pinpusher/README.md](pinpusher/README.md) for details.

### 🔄 Inception

Meta models for organizing HomeRacker parts within the HomeRacker ecosystem, Gridfinity bins and frame-mounted grids for storing supports and other bits.

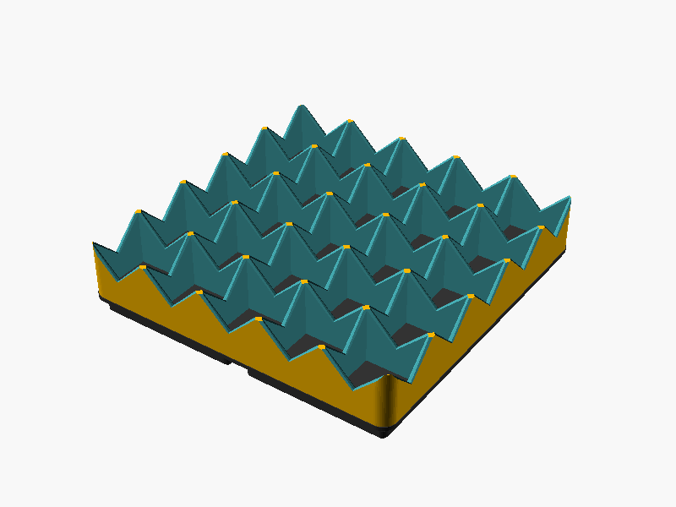
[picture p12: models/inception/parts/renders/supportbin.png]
Support Bin

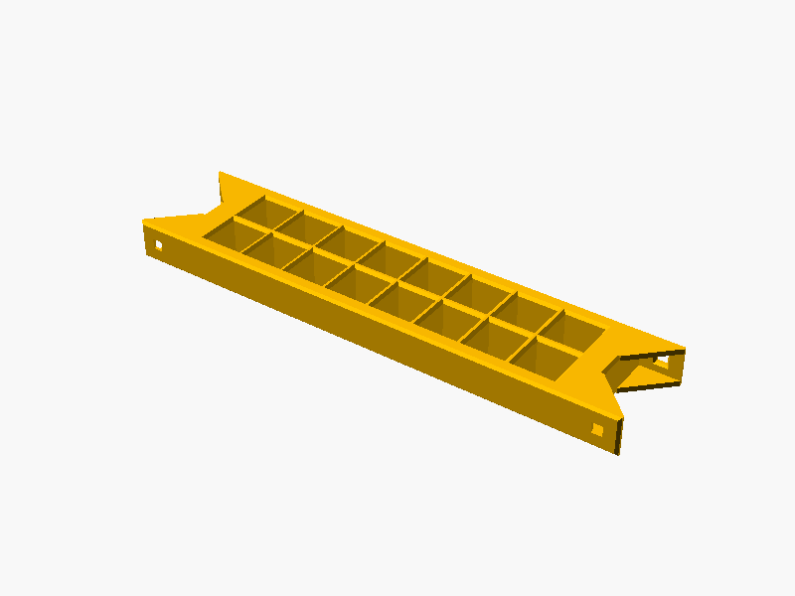
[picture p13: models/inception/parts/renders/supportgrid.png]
Support Grid


See [inception/README.md](inception/README.md) for details.

## 📁 Standard Model Structure

Each model folder follows this convention:

```
models/<name>/
├── lib/           # Module/function definitions (no top-level geometry)
├── parts/         # Renderable instances for Customizer, testing, and PNG renders
│   └── renders/   # Auto-generated full F6 render PNGs (from scadm export-png)
├── presets/       # (optional) Batch export variant collections
├── flattened/     # Self-contained flattened exports (auto-generated)
├── test/          # (optional) Test files for the model
└── README.md
```

- **`lib/`**: Reusable modules and constants. These files define geometry but don't render anything at the top level.
- **`parts/`**: Single-instance customizable files. Open in OpenSCAD Customizer to tweak parameters.
- **`parts/renders/`**: Auto-generated full F6 render PNGs from `scadm export-png` (always rendered with `--render`, not OpenCSG previews). These are the only image files tracked in this repo.
- **`flattened/`**: Generated by `scadm flatten`, inlines all local includes into a single self-contained file.
- Simple models may skip `lib/` if the module definition and instantiation live in a single file under `parts/`.

---

**MakerWorld exports**: Files in `<model_type>/parts/` are automatically exported on commit. See [cmd/export/README.md](../cmd/export/README.md) for details.

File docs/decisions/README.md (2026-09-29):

# 📋 Decision Records

Lightweight records capturing the **why** behind architecture, tooling, and workflow decisions.

## Active Decisions

| Decision | Date | Summary |
|---|---|---|
| [gate-coverage-and-surviving-mutants-in-changed-functions](gate-coverage-and-surviving-mutants-in-changed-functions.md) | 2026-09-29 | `scadm` unit tests gate on 90% branch coverage; a mutant surviving in a function the PR changed fails it; weekly full run to Discord |
| [agent-adapts-scadfmt-to-openscad-nightly](agent-adapts-scadfmt-to-openscad-nightly.md) | 2026-09-28 | On the weekly OpenSCAD nightly PR, a Claude agent adapts scadfmt when the grammar changed; the workflow tests and pushes, a person approves |
| [build-own-openscad-formatter-scadfmt](build-own-openscad-formatter-scadfmt.md) | 2026-09-27 | Own token-based formatter `scadfmt` in `cmd/scadfmt`: keeps line breaks, never changes tokens; linting later on `openscad-parser` |
| [gate-prs-with-a-single-check-results-job](gate-prs-with-a-single-check-results-job.md) | 2026-09-27 | One `ci.yml` PR pipeline; `check-results` (plus `validate-title`) are the required checks, so path-filtered jobs are required when they run |
| [e2e-test-site-and-configurator-with-playwright](e2e-test-site-and-configurator-with-playwright.md) | 2026-09-27 | Playwright E2E suite runs against the built site in `web.yml`; control and page inventories fail CI when a feature ships without a test |
| [return-bracket-to-open-source-catalog](return-bracket-to-open-source-catalog.md) | 2026-09-20 | Bracket comes back into this repo as an open-source part, flexmount retired in its favor |
| [x-hole-supports-by-default](x-hole-supports-by-default.md) | 2026-09-13 | Supports carry lock pin holes on both axes, so panels have a hole to pin to on every edge |
| [astro-site-replaces-jekyll](astro-site-replaces-jekyll.md) | 2026-09-02 | homeracker.org is an Astro site rendering the repo READMEs in place; Jekyll removed |
| [web-configurator-on-github-pages](web-configurator-on-github-pages.md) | 2026-09-02 | Rack configurator + parts list as a Vite app at `/configurator/`, deployed via Pages Actions |
| [rackpanel-usable-frame-helpers](rackpanel-usable-frame-helpers.md) | 2026-06-19 | Expose usable-frame helpers + child passthrough on `rackpanel` |
| [stiffen-rack-panels-with-truss-grid](stiffen-rack-panels-with-truss-grid.md) | 2026-06-19 | Optional back-side truss stiffener via generic `truss_grid` |
| [unify-export-png-into-scadm](unify-export-png-into-scadm.md) | 2026-06-18 | Replace duplicate shell scripts with `scadm export-png` |
| [keystone-snap-fit-socket-and-labels](keystone-snap-fit-socket-and-labels.md) | 2026-06-18 | Measured keystone cutter + original label system + native/bosl2 backend toggle |
| [image-hosting-assets-repo](image-hosting-assets-repo.md) | 2026-04-13 | Host manually-created images in `kellerlabs/assets` repo |

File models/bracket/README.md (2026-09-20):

# 🗜️ Bracket

## 📌 What

A clamp that wraps a device from above or below and hangs it in a HomeRacker frame. A shell grips the device, mount wings on both flanks cap the vertical supports and take a lock pin each.

Bracket

## 🤔 Why

Devices come in arbitrary sizes, HomeRacker supports sit on a 15mm grid. The wings absorb the difference: each one widens by half of what the device width misses on the grid, so the lock pin holes land on a support whatever the device measures. Nothing below/above the device, so airflow and cabling stay clear.

## 🔧 How

Open `parts/bracket.scad` in OpenSCAD and use the **Customizer** panel.

| Parameter | Default | Range | Description |
|---|---|---|---|
| `device_width` | 100 | 15-390 | Device width in mm |
| `device_depth` | 99 | 15-400 | Device depth in mm |
| `device_height` | 25.5 | 9.4-250 | Device height in mm |
| `strength_top` | 7.5 | 2-50 | How far the top plate reaches inward over the device |
| `strength_sides` | 7.5 | 2-50 | How far the side walls reach down the device |
| `mount_axis` | x | x, y | Which frame supports the wings hook over |
| `mount_gap_units` | 0 | 0-20 | Whole units added to the span between the wings |
| `mount_columns` | 0 | 0-2 | Wing columns, 0 picks 1 or 2 automatically |
| `mount_offset_y` | 0 | 0 to `device_depth - 15` | Pushes the wings back from the front edge |
| `debug_colors` | false | bool | Color-code geometry for debugging |
| `disable_chamfer` | false | bool | Remove chamfers (useful for debugging fit) |

Measure the device itself, not a gap. The standard 0.2mm `TOLERANCE` is added internally.

The 50mm ceiling on both strengths is a Customizer slider bound, not a limit of the model. Through the library or a `-D` override they take any value from 2mm up and clamp as described under ⚠️ Limits, which is what the `strength_sides=200` render command below does.

**Library usage**, include in your own model:

```scad
include <../bracket/lib/bracket.scad>

bracket(device_width=100, device_depth=99, device_height=25.5);
```

Implemented as a [BOSL2 attachable](https://github.com/BelfrySCAD/BOSL2/wiki/Tutorial-Attachments). `bracket_shell()`, `bracket_mount()` and `bracket_mount_pair()` are exposed for composing the halves separately. An optional `color` parameter overrides the default yellow.

## 🧭 Mount axis and gap units

A HomeRacker frame has supports running both ways. By default the wings hook the ones running along the device face (`mount_axis="x"`), which is what most devices want. Set `mount_axis="y"` and the caps turn a quarter turn to hook the supports running front to back along the sides of the frame instead.

That matters when a device is wide enough that the wings plus the connector arms eat the rack's usable width. A device wider than 164,8mm in a 10" rack is the usual case: on the X axis it does not fit, which forces a 19" rack, a tray or going off-standard (full HomeRacker). Hooking the frame sides instead moves the pins out of the contested span.

`mount_gap_units` widens the span between the wings by whole units, and it does two jobs:

- **Reach.** Extra units push the wings out to supports further away, which is how a `mount_axis="y"` bracket reaches the sides of the frame.
- **Centring.** An odd count lands on the left first (1 goes left, 2 one per side, 3 puts two left and one right), so the device sits off-centre between the supports. That is how you centre a device in a frame whose unit count does not divide evenly.

Both work on either axis.

Two things behave differently on the Y axis:

- **Column spacing steps two units at a time** and `mount_offset_y` rounds to a whole unit, because the pins go through the frame's own hole grid. Where rounding up would push the outer cap past the back of the shell, the offset steps down to the last unit that fits. Spacing comes out slightly narrower than the same device gets on X.
- **The span clears the device edge by 2.1mm**, the amount a sideways cap reaches back. A width in the last 2.1mm before a grid line costs a whole unit: 100.6mm still fits a 105mm span, 100.7mm steps out to 120mm.

## ⚠️ Limits

Seven inputs are refused outright, with an assertion naming the value that would work.

| Limit | Value | Why |
|---|---|-----|
| `device_height` | at least 9.4mm | The bridge skeleton cutout is rounded by half a unit, and the rounding has to fit between the bridge floor and its chamfered top |
| `device_depth` | at least 15mm | Shallower leaves no room for even one column of wings |
| `mount_offset_y` | at most `device_depth - 15` | Beyond that the wings hang off the back of the shell instead of gripping the supports |
| `mount_columns = 2` | needs `device_depth >= 45 + mount_offset_y` | Two columns any closer would merge into one block |
| `strength_top`, `strength_sides` | at least 2mm | One wall thickness is the thinnest shell that holds a device at all |
| `mount_axis` | `x` or `y` | Anything else is a typo rather than a third axis |
| `mount_gap_units` | whole number, zero or more | A fraction of a unit would put the pins off the grid |

Three inputs are silently clamped at the top end rather than refused, because the clamped result is still the part you asked for:

- `strength_top` caps at half the smaller device dimension, where the top plate closes over entirely.
- `strength_sides` caps at `device_height - 2mm`.
- `mount_columns = 0` picks two columns from a device depth of `45 + mount_offset_y`, one below that.

One thing to know before composing with the module: **the attachable bounding box covers the shell only**. The wings reach past it on all three axes, outward in X by a wing width each side, down in Z by roughly the device height plus a support unit, and in Y wherever `mount_offset_y` puts them. Anchor against the shell, then place anything near the wings by hand.

## 📸 Catalog

| Part | Preview |
|---|---|
| Bracket | Bracket |

### Variants

Each of these shows one behavior the module applies on its own.

| Single column (shallow device) | Forced single column | Wide wings (width near a grid line) |
|---|---|---|
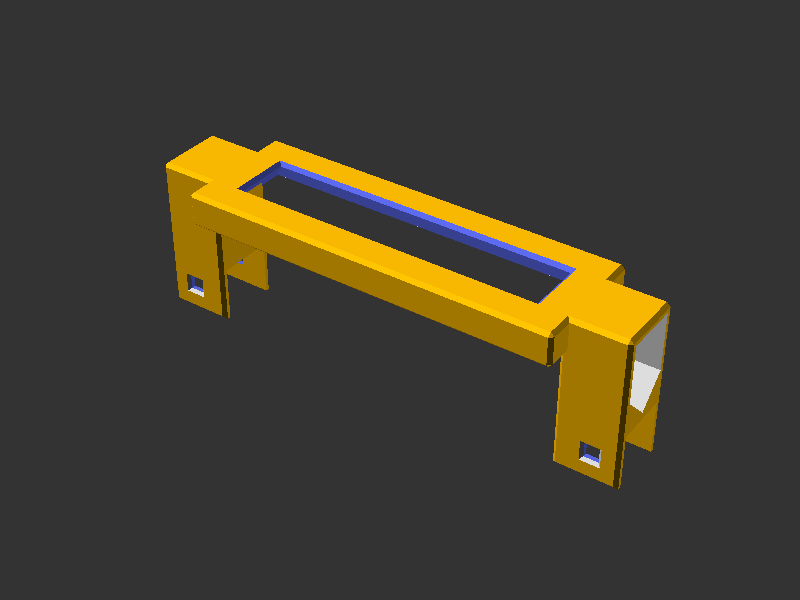
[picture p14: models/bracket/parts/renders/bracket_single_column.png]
Single column
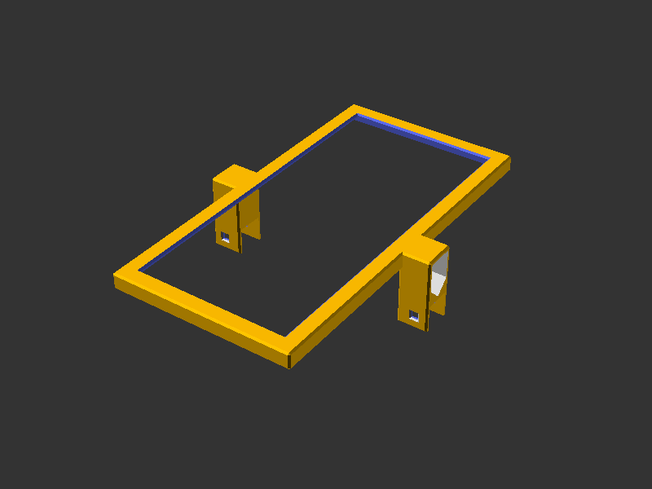
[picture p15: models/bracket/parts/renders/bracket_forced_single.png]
Forced single column
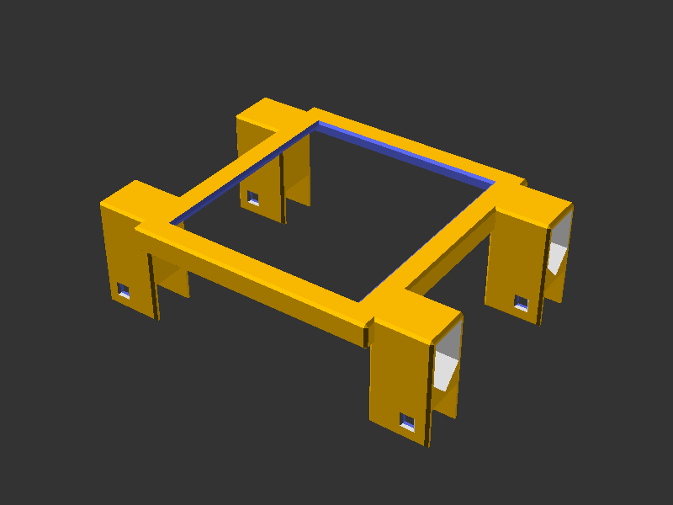
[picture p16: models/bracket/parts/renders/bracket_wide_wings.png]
Wide wings
|  |  |  |
| `device_depth` of 30 is under the two-column threshold, so one column per side | 200mm deep but pinned to one column, which saves material on a light device | A 90mm device sits just past a grid line, so each wing grows to 22.4mm to reach the support. The lock pin hole stays on the grid |

| Mount offset | Closed top plate | Deep side walls |
|---|---|---|
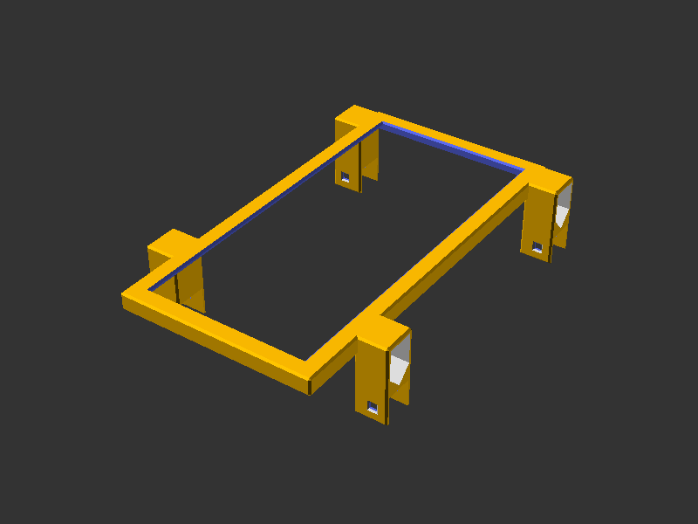
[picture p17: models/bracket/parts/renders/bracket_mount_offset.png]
Mount offset
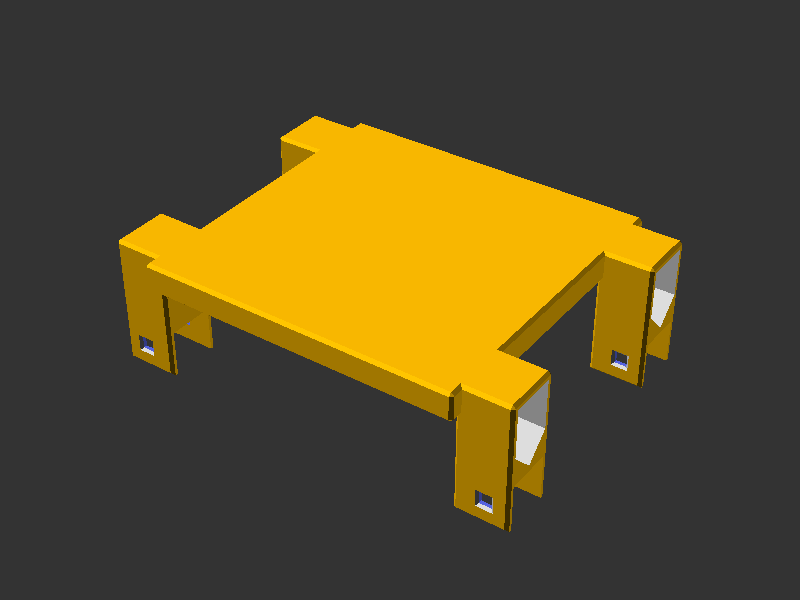
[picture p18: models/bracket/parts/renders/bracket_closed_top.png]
Closed top
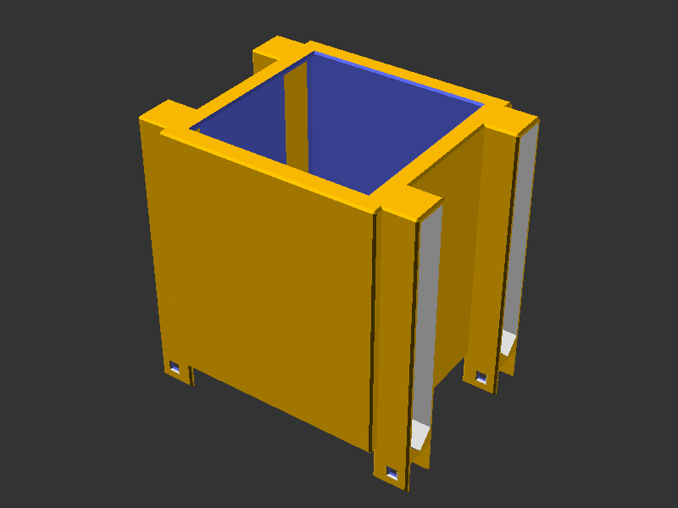
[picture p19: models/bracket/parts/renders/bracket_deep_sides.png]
Deep sides
|  |  |  |
| `mount_offset_y` of 34 pushes both columns back, which is how a bracket clears a front panel | `strength_top` of 50 hits the cap on a 99mm device, closing the window and dropping its chamfer | `strength_sides` of 200 clamps to `device_height - 2`, wrapping a 120mm device almost to the bottom |

| Minimum strengths | Y axis | Odd gap units |
|---|---|---|
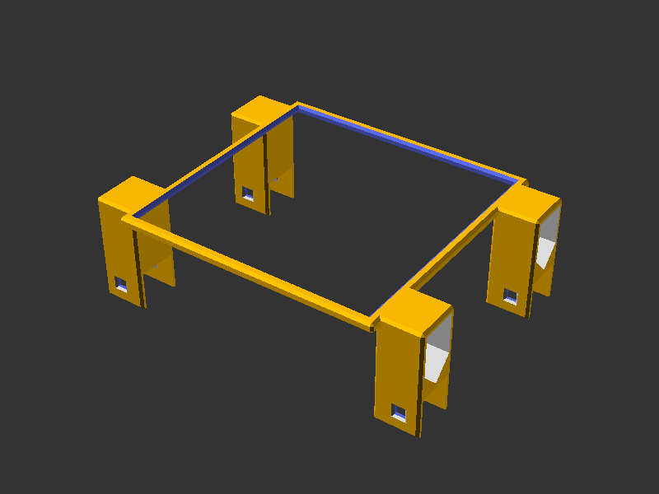
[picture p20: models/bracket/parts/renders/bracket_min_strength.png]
Minimum strengths
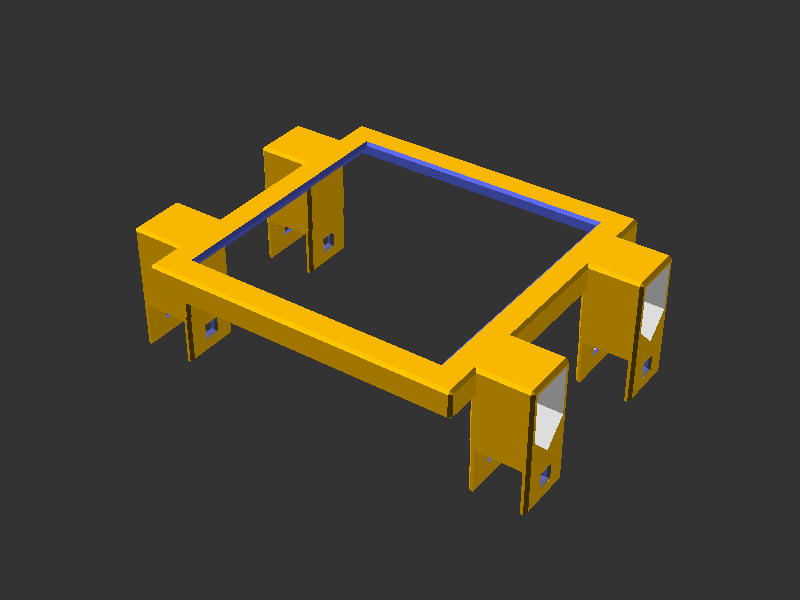
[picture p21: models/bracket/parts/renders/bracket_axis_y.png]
Y axis
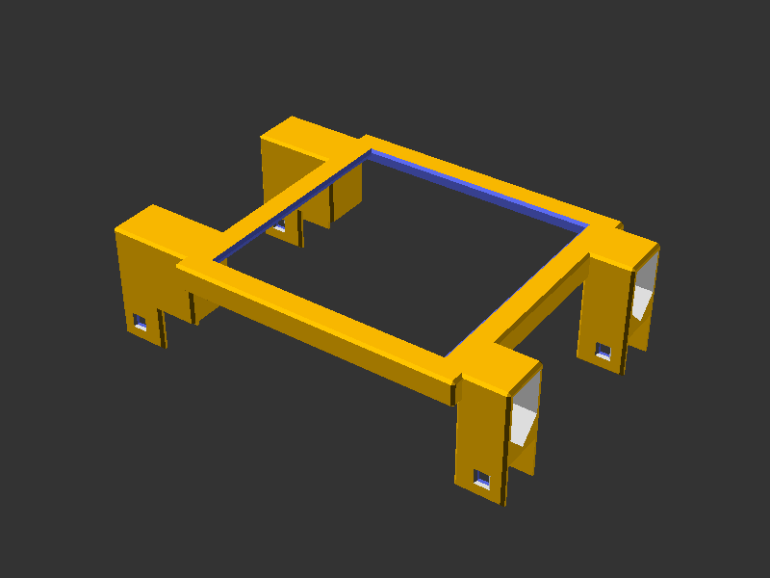
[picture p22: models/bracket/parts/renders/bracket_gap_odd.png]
Odd gap units
|  |  |  |
| Both strengths at their 2mm floor, the thinnest shell the module will build | `mount_axis="y"`, caps turned a quarter turn to hook the frame sides | `mount_gap_units=1` lands on the left, shifting the device within the frame |

| Y axis reaching out |
|---------------------|
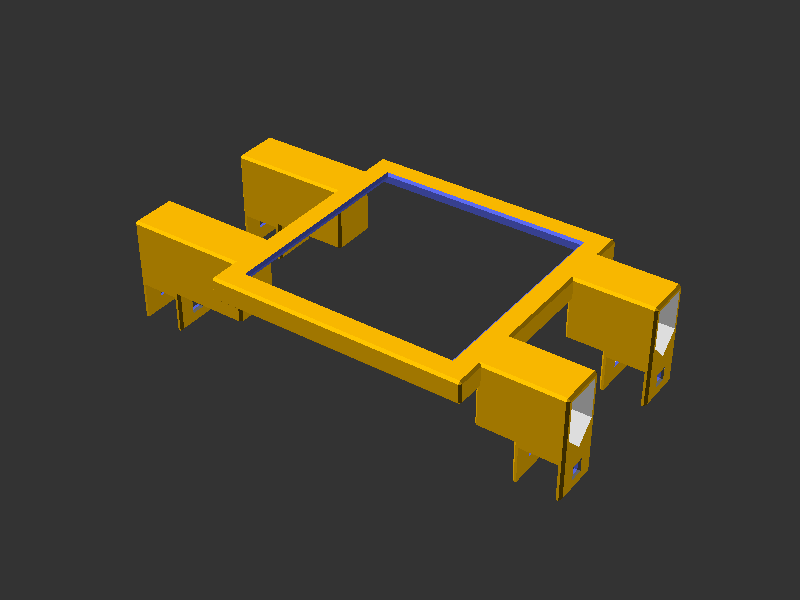
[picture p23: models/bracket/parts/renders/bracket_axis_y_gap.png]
Y axis with gap
|  |
| `mount_axis="y"` with `mount_gap_units=3`, reaching past the near supports to the frame sides |

To generate or refresh the renders (full F6 renders via `scadm export-png`):

```sh
scadm export-png models/bracket/parts/bracket.scad
scadm export-png models/bracket/parts/bracket.scad -D device_depth=30 --output models/bracket/parts/renders/bracket_single_column.png
scadm export-png models/bracket/parts/bracket.scad -D device_depth=200 -D mount_columns=1 --output models/bracket/parts/renders/bracket_forced_single.png
scadm export-png models/bracket/parts/bracket.scad -D device_width=90 --output models/bracket/parts/renders/bracket_wide_wings.png
scadm export-png models/bracket/parts/bracket.scad -D device_depth=200 -D mount_offset_y=34 --output models/bracket/parts/renders/bracket_mount_offset.png
scadm export-png models/bracket/parts/bracket.scad -D strength_top=50 --output models/bracket/parts/renders/bracket_closed_top.png
scadm export-png models/bracket/parts/bracket.scad -D strength_top=2 -D strength_sides=2 --output models/bracket/parts/renders/bracket_min_strength.png
scadm export-png models/bracket/parts/bracket.scad -D device_height=120 -D strength_sides=200 --output models/bracket/parts/renders/bracket_deep_sides.png
scadm export-png models/bracket/parts/bracket.scad -D 'mount_axis="y"' --output models/bracket/parts/renders/bracket_axis_y.png
scadm export-png models/bracket/parts/bracket.scad -D mount_gap_units=1 --output models/bracket/parts/renders/bracket_gap_odd.png
scadm export-png models/bracket/parts/bracket.scad -D 'mount_axis="y"' -D mount_gap_units=3 --output models/bracket/parts/renders/bracket_axis_y_gap.png
```

## 📚 References

- [HomeRacker core](../core/README.md): base constants, lock pins and supports
- [Sleeve](../sleeve/README.md): the other reusable way to attach to a support
- [Return the bracket to the open-source catalog](../../docs/decisions/return-bracket-to-open-source-catalog.md): why the module lives here

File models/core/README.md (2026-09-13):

# 🧱 HomeRacker Core

## 📌 What

The core building system for HomeRacker, the fully modular 3D-printable rack-building platform. Provides supports, connectors, and lock pins as parametric OpenSCAD modules.

## 🤔 Why

- **Modularity**: Snap-together system using standardized 15mm units, no glue, no screws
- **Parametric**: Every component is fully customizable via OpenSCAD Customizer
- **Extensible**: Library modules (`lib/`) can be included in your own projects

See the [main README's Tech Specs](../../README.md#-tech-specs) for dimensional rationale and assembly basics.

## 🔧 How

### Using the Library

Include the core library in your OpenSCAD projects:

```scad
use <core/main.scad>

// Create a 3-directional connector
connector(dimensions=3, directions=3);

// Create a support beam (3 units long)
support(units=3);

// Create a lock pin with standard grip
lockpin(grip_type="standard");

// Advanced: use the lock-pin hole primitive directly (e.g. in a split connector)
// disable_chamfer=true produces a flat-ended hole for stacking
lockpin_hole_support(disable_chamfer=false);
```

### Customizing Parts

Open any file in `parts/` with OpenSCAD and use the **Customizer** panel to adjust parameters:

- **`connector.scad`**: Customize dimensions, directions, pull-through axes, and orientation
- **`support.scad`**: Customize length and hole configurations
- **`lockpin.scad`**: Customize grip type (standard, extended or no-grip)

### Exporting Variants

The `presets/` folder contains modules for batch-exporting all logical variants:

- **`connectors.scad`**: Organized collections (standard, pull-through)
- **`supports.scad`**: Various support lengths with different hole configurations
- **`lockpins.scad`**: Standard grip, extended and no-grip variants

## 🧩 Core Components

### 1. **Supports** (Beams)
Structural elements with standardized connection points.
- 15mm × 15mm cross-section
- Configurable length (multiples of 15mm)
- Optional second set of lock pin holes across the X axis (`x_holes`), the ones a panel mount needs on the face it lies on. The configurator asks for them on every support, see [x-hole supports by default](../../docs/decisions/x-hole-supports-by-default.md)

### 2. **Connectors**
Junction pieces that join supports in multiple directions.
- 1D, 2D, or 3D variants (up to 6 directions)
- Optional pull-through axes for complex builds
- Lock pin holes (4mm square pins)
- Use [foot inserts](../foot/README.md) to create a stable contact interface to the ground

### 3. **Lock Pins**
4mm square pins that secure connectors to supports via tension fit.
- Standard grip: Two grip arms for easy insertion/removal
- Extended grip: Two asymmetric grip arms with a dominant outer arm.
- No-grip variant: Smooth design for minimal profile
- Bidirectional tension hole for secure fit

## 📐 Dimensional Standards

- **Base Unit**: 15mm
- **Lock Pin**: 4mm square
- **Wall Thickness**: 2mm
- **Tolerance**: 0.2mm (built into connectors)
- **Standard Chamfer**: 1mm
- **Lock Pin Chamfer**: 0.8mm

## 📸 Catalog

| Part | Preview |
|---|---|
| Connector | Connector |
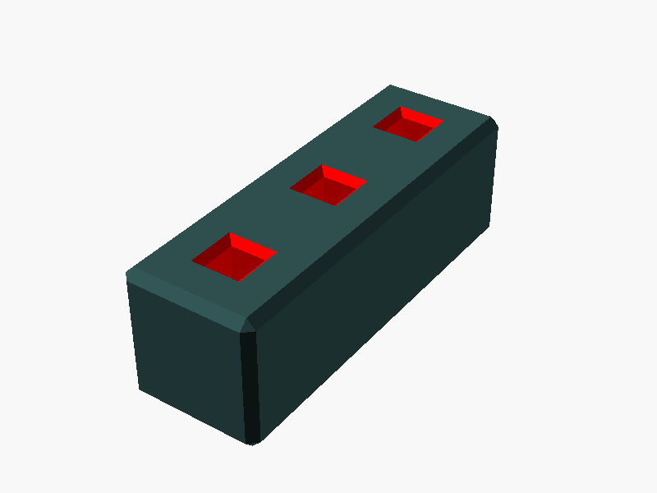
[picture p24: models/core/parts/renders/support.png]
Support
| Support |  |
| Lock Pin | Lock Pin |

To generate or refresh previews:

```bash
scadm export-png models/core/parts/<part>.scad
```

## 📝 License

- **Source Code**: MIT License
- **3D Models**: CC BY-SA 4.0

## 📚 References

- [Main Repository](https://github.com/kellerlabs/homeracker)
- [BOSL2 Library Documentation](https://github.com/BelfrySCAD/BOSL2/wiki)

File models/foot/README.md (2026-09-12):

# 🦶 Foot Insert

## 📌 What

A standalone foot insert that plugs into any HomeRacker connector arm from the outside. Replaces the former built-in `is_foot` connector option with a separate, modular component.

## 🤔 Why

- **Flexibility**: Feet are now independent, add or remove them without needing special connector variants. When extending a rack vertically, just unmount the feet and add levels to the bottom.
- **Simplicity**: Removes `is_foot` complexity from the connector module (fewer variants to maintain and export).
- **Material choice**: Can be printed in **TPU** for better grip and load distribution, while the connector stays rigid (PLA/PETG).

## 🔧 How

Open `parts/foot.scad` in OpenSCAD and use the **Customizer** panel.

| Parameter | Default | Description |
|---|---|---|
| `debug_colors` | `false` | Show distinct colors per section for visualization |
| `disable_chamfer` | `false` | Remove chamfers from all sections |
| `anchor` | `CENTER` | BOSL2 anchor point for positioning |
| `spin` | `0` | BOSL2 spin rotation (degrees) |
| `orient` | `UP` | BOSL2 orientation vector |

### Geometry

Three stacked parts (top → bottom, using BOSL2 `attach()`):

1. **Support section** (15×15×15mm): A 1-unit `support()` with `x_holes=true`, oriented downward. Plugs into the connector arm with lock pin holes in both perpendicular directions.
2. **Spacer** (15×15×1.1mm): Inset shim at the arm entry, `TOLERANCE/2` shift-out plus `BASE_CHAMFER` inset for a flush transition. Chamfered on side edges.
3. **Base plate** (19.2×19.2×2mm): Wider platform for load distribution and grip. Chamfered on all edges except the top face.

### Usage

```scad
include <foot/lib/foot.scad>

// Default foot
foot();

// Debug visualization
foot(debug_colors=true);

// Flat base (no chamfer)
foot(disable_chamfer=true);
```

## 📸 Catalog

| Part | Preview |
|---|---|
| Foot | Foot |

To generate or refresh previews:

```sh
scadm export-png models/foot/parts/foot.scad
```

## 📚 References

- [HomeRacker core](../core/README.md): connectors, supports, lock pins
- [Connector module](../core/lib/connector.scad): the connector arms where feet insert

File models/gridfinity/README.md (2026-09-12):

# 📦 HomeRacker Gridfinity

## 📌 What

Gridfinity-compatible baseplates and bin bases implemented as reusable OpenSCAD modules for anyone to use. This library makes it easy to integrate Gridfinity interfaces into your models.

- **Baseplate**: Use for Gridfinity-compatible shelves or drawers
- **Bin Base**: Use as a foundation for custom Gridfinity bins

## 🤔 Why

Mainly because I can, but also other implementations I found were pretty complicated and I just wanted simple interfaces.

- Standard 42mm Gridfinity grid, compatible with the entire ecosystem
- Parametric OpenSCAD modules, include in your own projects
- Spec-compliant with [grizzie17's Gridfinity specification](https://www.printables.com/model/417152-gridfinity-specification)

## 🔧 How

### Using the Library

Include Gridfinity modules in your OpenSCAD projects:

```scad
include <gridfinity/lib/baseplate.scad>
include <gridfinity/lib/binbase.scad>

// Create a 3×2 baseplate
baseplate(units_x=3, units_y=2);

// Create a 1×2 bin base
binbase(units_x=3, units_y=2);

// Create a bin base with a flat top plate (useful as foundation for custom geometry)
binbase_with_topplate(units_x=2, units_y=2, topplate_thickness=2);
```

### Customizing Parts

Open any file in `parts/` with OpenSCAD and use the **Customizer** panel to adjust parameters:

- **`baseplate.scad`**: Customize grid dimensions (x and y units)
- **`binbase.scad`**: Customize grid dimensions and preview with baseplate

### Exporting Variants

The `flattened/` folder contains pre-configured variants for export as self-contained files to MakerWorld or other platforms.

## 🧩 Core Components

### 1. **Baseplate**
Mounting surface for Gridfinity bins and organizers.
- Standard Gridfinity 42mm grid spacing
- Precise dimensional compliance with grizzie17's specification
- Optimized for 0.4mm nozzle printing
- Compatible with all standard Gridfinity bins

### 2. **Bin Base**
Bottom mounting component for custom Gridfinity-compatible containers.
- Standard Gridfinity 42mm grid spacing
- Matches baseplate cutout geometry
- Stack securely on Gridfinity baseplates
- `binbase_with_topplate()` adds a flat plate on top, handy as a foundation for custom geometry
- All modules are BOSL2-attachable (`anchor`, `spin`, `orient`)

## 📐 Dimensional Standards

All dimensions follow [grizzie17's Gridfinity specification](https://www.printables.com/model/417152-gridfinity-specification) for maximum compatibility.

## 📸 Catalog

| Part | Preview |
|---|---|
| Baseplate | Baseplate |
| Bin Base | Bin Base |

To generate or refresh previews:

```bash
scadm export-png models/gridfinity/parts/<part>.scad
```

## 📝 License

- **Source Code**: MIT License

## 📚 References

- [BOSL2 Library Documentation](https://github.com/BelfrySCAD/BOSL2/wiki)
- [Gridfinity Specification](https://www.printables.com/model/417152-gridfinity-specification)

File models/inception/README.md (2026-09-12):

# 🔄 Inception, HomeRacker Meta

## 📌 What

Models for organizing HomeRacker parts *within* the HomeRacker ecosystem. Includes Gridfinity-compatible bins and frame-mounted grids for storing supports and other bits.

## 🤔 Why

For the completely insane people who want to store their leftover HomeRacker parts in an organized fashion, on a HomeRacker shelf, in Gridfinity bins, of course.

## 🔧 How

Open any file in `parts/` with OpenSCAD and use the **Customizer** panel.

### Support Bin

A Gridfinity bin with a pocket grid that holds HomeRacker supports upright. Uses a standard Gridfinity bin base.

| Parameter | Default | Range | Description |
|---|---|---|---|
| `grid_x` | 2 | 1-17 | Gridfinity units in X (×42 mm) |
| `grid_y` | 2 | 1-10 | Gridfinity units in Y (×42 mm) |
| `divider_strength` | 1.2 | 1.0-3.0 | Divider wall thickness (mm) |
| `grid_style` | Riser | Riser / Full | Cross-shaped ridges vs solid walls |
| `height` | 15 | 5-15 | Pocket grid height (mm) |

**Grid styles:**

- **Riser**: Cross-shaped ridges with 45° slopes; minimal material, easier fitting
- **Full**: Solid walls with rectangular pockets; maximum rigidity

### Support Grid

A frame-mounted pocket grid that clips directly into a HomeRacker rack opening via mounting ears with lock pins. No Gridfinity base needed.

| Parameter | Default | Range | Description |
|---|---|---|---|
| `hr_width` | 11 | 15-17 | Frame width in HR units (×15 mm) |
| `hr_height` | 3 | 3-10 | Frame height in HR units (×15 mm) |
| `end_piece` | false | true/false | Add backstop to prevent supports sliding through |
| `funnel_strength` | 3 | 3.3-5.0 | Divider wall thickness (mm) |
| `grid_depth` | 1 | 1-5 | Grid depth in HR units (longer = more stable) |
| `mounting_axis` | Vertical | Vertical / Horizontal / Both | Where to place the mounting ears |

**Mounting axis options:**

- **Vertical**: Ears on the left/right sides of the grid
- **Horizontal**: Ears on the top/bottom
- **Both**: Ears on all four sides

## 📸 Catalog

| Part | Preview |
|---|---|
| Support Bin | Support Bin |
| Support Grid | Support Grid |

To generate or refresh previews:

```sh
scadm export-png models/inception/parts/<part>.scad
```

## 📚 References

- [Gridfinity library](../gridfinity/README.md)
- [HomeRacker core](../core/README.md)

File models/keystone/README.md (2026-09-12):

# 🔌 Keystone

## 📌 What

Parametric keystone jack socket module for integrating standard keystone connectors into HomeRacker panels. Provides the negative geometry (pocket + socket) that accepts any standard keystone module, plus optional snap-fit label plate slots for port identification.

Based on dimensions from the [Parametric Keystone Connector](https://www.printables.com/model/537480-parametric-keystone-connector) by Paul Hatcher (Public Domain / CC0).

## 🤔 Why

Keystone jacks are the universal standard for structured cabling (Ethernet, HDMI, USB, coax, fiber). By providing a reusable pocket module, any HomeRacker panel can become a patch panel without reinventing the snap-fit geometry each time.

- **Rotation support** (0°, 90°, 180°, 270°), mount jacks vertically or horizontally to trade off panel density vs. cable bend room.
- **Snap-fit label system**: printed label plates identify ports without adhesive labels that peel off, or labels that are baked into the panel and can't be changed.
- **Label above or below** (`label_position`), put the label slot on either side of the jack so stacked rows can tuck labels between them without covering the opening of the row above.
- **Fit-tunable**: `additional_tolerance` widens the socket cut for printers/filaments that run tighter or looser than the reference.

### Where the dimensions come from

The socket profile is **measured from** Paul Hatcher's CC0 [Parametric Keystone Connector](https://www.printables.com/model/537480-parametric-keystone-connector): that STL printed and fit a perfect range of real jacks (e.g. deleyCON CAT.7), so the distances were measured in the slicer and translated into parametric SCAD. The label dimensions instead derive from HomeRacker core constants (`KS_LABEL_HEIGHT = BASE_UNIT`, `KS_LABEL_STRENGTH = BASE_STRENGTH`, `KS_LABEL_CHAMFER = TOLERANCE * 4`) so labels stay on-system.

### Out of scope

Only *standard* keystone jacks (the universal snap profile). No angled/recessed keystones, no blank filler inserts, and no shuttered/dust-cover variants, those exist en masse online. The module is a **cutter** (negative geometry); you bring your own panel body.

## 🔧 How

### End-to-end workflow

1. **Design** a panel and cut keystone pockets into it with `keystone_full()` inside a `diff("keystone")` context (see [Library Usage](#library-usage)).
2. **Print** the panel. The socket is a tunnel through the panel; it may protrude behind a thin wall, that's expected.
3. **Snap the jack in from the *back*** of the panel. The retention hooks grab it and the front face stays clean and flush.
4. **Label (optional):** print `label_plate()` parts separately and snap them into the front recess. Labels print face-down for a clean multicolor result (see [Label system](#label-system-design)).

> 💡 **Print a single-jack sample first.** `parts/keystone_sample.scad` exists so you can print one pocket in minutes, verify your jacks seat correctly and tune `additional_tolerance`, *before* committing filament and hours to a full panel.

### Try it in the Customizer

Open `parts/keystone_sample.scad` in OpenSCAD and use the **Customizer** panel.

### Display Modes

| Mode | Description |
|---|---|
| `single` | One keystone at a chosen rotation angle |
| `full` | All 4 rotations side by side (90° and 180° show labels) |

### Parameters

| Parameter | Default | Description |
|---|---|---|
| `mode` | `single` | Display mode: `single` or `full` |
| `yrotation` | `0` | Y-axis rotation in single mode (0, 90, 180, 270) |
| `additional_tolerance` | `0.0` | Extra clearance added to socket **width & height** (mm). Widens the cut → looser fit. See [Print & fit testing](#print--fit-testing). |
| `panel_depth` | `9.75` | Depth of the keystone **tunnel/cut**, *not* the panel wall thickness. Floored at the jack depth (9.75 mm); raise it only to bore a deeper tunnel through a thicker panel body. |
| `show_labels` | `true` | Show label plates on keystones |
| `label_position` | `above` | Which side of the jack the label sits on: `above` or `below` (aesthetic default; no functional difference) |
| `label_plate_mode` | `assembly` | `assembly` previews the plate in front of its slots; `plate` lays it out print-ready (used by the Parametric Model Maker for MakerWorld build plates) |
| `debug_colors` | `false` | Tints each section for debugging. **`bosl2` backend only**, native renders one fused mesh and keeps its solid identity colors. |
| `geometry` | `native` | Geometry backend: `native` (fast) or `bosl2` (per-section debug colors). See below. |

### Geometry Backend (native vs BOSL2)

The socket, panel-side label recess, and label plate each ship two interchangeable geometry backends that produce the **identical** printable shape (verified by zero-volume boolean parity). Pick one via the `geometry` Customizer dropdown, or globally in code with the `$ks_native` special variable (`true` = native, `false` = BOSL2), like `$fn` it propagates to all children, so set it once at the top of your file.

Both backends render the model's solid identity colors (yellow socket, charcoal label plate). The only coloring difference is `debug_colors`: native geometry is a single fused mesh, so it cannot tint individual sections, use the `bosl2` backend when you need per-section debug colors.

> ⚠ **Disclaimer:** the `native` geometry was fully AI-transpiled from the original BOSL2 code.
> It was print-tested with no noticeable difference from the BOSL2 version, but the `bosl2`
> backend remains the authored source of truth, prefer it if in doubt.
> I personally only use the native geometry for really packed panels.

| Backend | Speed | `debug_colors` | Use when |
|---|---|---|---|
| `native` (default) | Fast, identical jacks/plates collapse to one cached mesh, so a fully-populated panel renders many times faster | ❌ per-section coloring not available (solid identity colors still apply) | Rendering or exporting real panels, especially with many keystones |
| `bosl2` | Slow, BOSL2 re-instantiates every copy, defeating OpenSCAD's geometry cache | ✅ full per-section coloring | Editing/inspecting a single part, or when you want per-section debug colors |

Why the speed gap: native geometry definitions are cached by OpenSCAD across identical copies, but a BOSL2 `attachable`/`diff` construction inside the geometry defeats that cache, and `diff()` re-evaluates its subtree multiple times per copy. On a populated panel this dominated render time, so `native` is the default.

#### Benchmark

Synthetic panel of **30 jacks (6×5) with label slots**, rendered to STL (manifold backend, `--render`). Median of 3 runs:

| Backend | 30-jack render | Marginal cost per added jack¹ |
|---|---:|---:|
| `native` | **0.17 s** | ~5.4 ms |
| `bosl2`  | 1.0 s | ~32 ms |

**≈ 6× faster** on this panel, and the gap widens as you add more jacks. ¹Marginal cost is derived from the 1-jack vs 30-jack delta, isolating the per-copy geometry work the native cache eliminates.

<sub>Hardware: AMD Ryzen 9 7950X (16C/32T), 64 GB RAM, Windows. OpenSCAD 2026.06.12, manifold
backend. OpenSCAD's geometry render is effectively single-threaded, so wall-clock numbers are CPU-clock bound and reproduce closely across runs. Reproduce with `_visual_test/ks_bench.scad` (throwaway, not tracked), see the [decision record](../../docs/decisions/keystone-snap-fit-socket-and-labels.md) for the method.</sub>

### Label system design

The label system is an original HomeRacker design layered on top of the measured socket profile:

- **Snap-fit retention** with a minimal lip overlap, enough to hold the plate against shaking/vibration, not so much that it fights you.
- **Generous top & bottom chamfers** give you a fingernail purchase to pop a plate back out.
- **Double-slit slot**: not for style: it lets the whole part bridge cleanly so it prints **support-free**, and lets the label print **face-down** for an easy, clean multicolor result.
- **Print-ready layout**: `label_plate_mode = "plate"` lays the plate flat next to the panel so the Parametric Model Maker can drop it onto a MakerWorld build plate.

Section anatomy

*`debug_colors = true` on the `bosl2` backend, panel body (white), socket sections (yellow), label recess (blue), label hooks (red/green).*

### Print & fit testing

`additional_tolerance` is the one knob you may need to touch. It is added **only to the socket width and height**, defaults to `0.0`, and that default fits the reference jacks perfectly on the author's printer. Because no two printers or filaments shrink alike, the single-jack sample exists to test the fit cheaply before printing a whole panel.

Two printed single-demo panels side by side

*Two printed single-demo panels with CAT.7 jacks snapped in from the back. Left at `additional_tolerance = 0.0` (perfect fit), right at `0.2` (a touch of wiggle).*

- `0.0`: reference fit; works as-is for the author.
- `0.2`: a hair looser; still seats and holds fine.
- `1.0`: untested; likely too loose to retain a jack. Step up in small increments.

### Library Usage

```scad
include <homeracker/models/keystone/lib/keystone.scad>

// Use in a diff("keystone") context to cut a keystone slot into a panel:
diff("keystone")
cuboid([50, 2, 50]) {
  align(FRONT, BOTTOM, inside=true)
    keystone_full(yrot=0, panel_depth=15, add_label_slots=true);
}
```

### Key Modules

| Module | Purpose |
|---|---|
| `keystone_full()` | Complete pocket with optional label slots, primary entry point |
| `keystone_pocket()` | Outer pocket carved into panel body (no label slots) |
| `keystone_socket()` | Inner snap-fit socket geometry matching keystone profile |
| `label_plate()` | Standalone label plate (print separately) |
| `label_recess()` | Front-face recess for label hook snap-fit |
| `keystone_demo_panel()` | Demo panel strip with one keystone mounted |

`keystone_full()` and `keystone_demo_panel()` accept `label_plate_mode` (`"assembly"` or `"plate"`) and `label_plate_gap` (mm) to control label plate placement for build-plate layouts. They also accept `label_position` (`"above"` or `"below"`) to mirror the label slot to either side of the jack.

### Key Functions

| Function | Returns |
|---|---|
| `get_ks_width_outer(tol)` | Outer width including walls + tolerance |
| `get_ks_height_outer(tol)` | Outer height including walls + tolerance |
| `get_ks_depth_outer()` | Total depth (front lip + body + rear hook) |
| `get_effective_keystone_width(tol, yrot)` | Width accounting for rotation |
| `get_effective_keystone_height(tol, yrot)` | Height accounting for rotation |
| `get_keystone_dimensions(yrot, tol)` | Pocket dimensions `[w, d, h]` accounting for rotation (excludes label recess) |

## 📸 Catalog

| Part | Preview |
|---|---|
| Keystone Sample | Keystone Sample |
| Label Below | Label Below |
| Plate Mode (print-ready) | Plate Mode |
| Debug Colors | Debug Colors |

To generate or refresh previews:

```sh
scadm export-png models/keystone/parts/keystone_sample.scad
scadm export-png models/keystone/parts/keystone_sample.scad -p models/keystone/parts/keystone_sample_below.json -P label_below --output models/keystone/parts/renders/keystone_sample_below.png
scadm export-png models/keystone/parts/keystone_sample.scad -D 'mode="single"' -D 'label_plate_mode="plate"' --output models/keystone/parts/renders/keystone_sample_plate_mode.png
scadm export-png models/keystone/parts/keystone_sample.scad -D 'mode="full"' -D 'debug_colors=true' -D '$ks_native=false' --output models/keystone/parts/renders/keystone_sample_debug.png
```

## 📚 References

- [HomeRacker core](../core/README.md): constants, supports, connectors
- [Panel model](../panel/README.md): plain panels that can host keystone sockets
- [Keystone socket & label design](../../docs/decisions/keystone-snap-fit-socket-and-labels.md): decision record (provenance, label design, backend toggle)
- [Parametric Keystone Connector](https://www.printables.com/model/537480-parametric-keystone-connector): original dimension reference (CC0)

> The HomeRacker-exclusive `keystonepanel` model is a real consumer: it lays out rows of jacks using `get_effective_keystone_width()` / `get_effective_keystone_height()` / `get_label_attachable_height()` and cuts them with `keystone_full()`.

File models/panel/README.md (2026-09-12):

# 🖼️ Panel

## 📌 What

A plain mounting panel that fits into the HomeRacker scaffold system. Panels attach to vertical and horizontal supports via lockpin holes and can be used as-is (blank panels) or as a base for custom cutouts (keystone jacks, switches, displays, etc.).

## 🤔 Why

- **Universal base**: A generic panel module that any specialized panel (keystone, frontpanel, side panel) can build upon, no distinction between front/side at the lib level.
- **Two integration types**:
  - **Inter-Fit**: Inset panel for a flush fit between support bars. Each panel can be removed independently.
  - **Full Cover**: Overlap panel covering supports and connectors for a clean aesthetic. Must be integrated during scaffold assembly.
- **Scalable**: Supports arbitrary grid sizes (min 2×2 units). Panels larger than 2 units automatically get additional mount surfaces for rigidity.
- **Per-side control**: Each edge's mount surface can be enabled/disabled independently (north/south/east/west), and corner mounts can be toggled between full-height lockpin engagement and contour-only mode.

## 🔧 How

Open `parts/panel.scad` in OpenSCAD and use the **Customizer** panel.

| Parameter | Default | Range | Description |
|---|---|---|---|
| `panel_type` | 1 (Inter-Fit) | 1-2 | Panel integration type |
| `units_x` | 4 | 2-16 | Panel width in HR units |
| `units_y` | 3 | 2-16 | Panel height in HR units |
| `panel_clearance` | 0.0 | 0-0.4 | Full Cover only, gap between adjacent panels (mm). Default 0.0 works for most printers; increase slightly if panels are too tight |
| `corner_mounts` | true | true/false | Full-height corner mounts with lockpin holes (false = contour only) |
| `mount_north` | true | true/false | Mount plate on north (back) edge (only effective when units_x > 2) |
| `mount_south` | true | true/false | Mount plate on south (front) edge (only effective when units_x > 2) |
| `mount_east` | true | true/false | Mount plate on east (right) edge (only effective when units_y > 2) |
| `mount_west` | true | true/false | Mount plate on west (left) edge (only effective when units_y > 2) |
| `debug_colors` | false | true/false | Show distinct colors per section for debugging |
| `chamfer_enabled` | true | true/false | Apply chamfers to edges |

## 📸 Catalog

| Part | Preview |
|---|---|
| Panel (Inter-Fit) | Panel Inter-Fit |
| Panel (Full Cover) | Panel Full Cover |
| Rack Panel (10") | Rack Panel 10" |
| Rack Panel (19") | Rack Panel 19" |
| Split Connector | Split Connector |
| Split Lock Pin | Split Lock Pin |

To generate or refresh the renders (full F6 renders via `scadm export-png`):

```sh
scadm export-png models/panel/parts/panel.scad
scadm export-png models/panel/parts/rackpanel.scad
scadm export-png models/panel/parts/split_connector.scad
scadm export-png models/panel/parts/split_lockpin.scad
```

### Panel Variants

#### Default (all mounts enabled)

| Inter-Fit | Full Cover |
|---|---|
| Inter-Fit Default | Full Cover Default |

#### Contour Corners (corner_mounts = false)

Wherever a mount surface is disabled (corners or edges), the panel shows a contour instead, a short wall at BASE_STRENGTH height without lockpin holes. The contour provides added stability and keeps the panel opaque (no gaps), while staying short enough to not block any attachments on the HR scaffold.

**When to use corner mounts:**

Corner mounts occupy the lockpin holes normally used by supports and connectors. This matters when two panels share a 90° edge of the rack, one panel's corner mount blocks the lockpin hole needed by the other. For panels > 3×3 units, leaving corners disabled (contour only) is recommended as the mount surfaces alone provide sufficient engagement and it's easier to first build the scaffold and afterwards add panels to it.

For smaller panels (≤ 3 units on one axis), corner mounts become valuable: a 3-unit side has only 1 lockpin hole on its mount surface, and panels < 3 units have no mount surfaces at all. Corner mounts (combined with extended lockpins, neck, tail, or both variants) let these panels use connector lockpin positions that would otherwise be inaccessible.

| Inter-Fit | Full Cover |
|---|---|
| Inter-Fit No Corners | Full Cover No Corners |

#### Partial Mounts (south + west disabled)

Shows the difference in wall height between panel types when mount surfaces are disabled:
- **Inter-Fit**: disabled sides get full-height walls (same as mount height) to maintain the panel contour.
- **Full Cover**: disabled sides get short 2mm walls only, keeping the area clear for attachments in the HR scaffold.

| Inter-Fit | Full Cover |
|---|---|
| Inter-Fit Partial | Full Cover Partial |

#### Minimal Size (2×2)

The smallest possible panel, only corner mounts, no mount surfaces (they require > 2 units). Disabling `corner_mounts` on a 2×2 panel makes the panel non-mountable.

| Inter-Fit | Full Cover |
|---|---|
| Inter-Fit 2×2 | Full Cover 2×2 |

## 🔩 Rack Panel

A standard 10"/19" rack-compatible panel with configurable bore patterns. Open `parts/rackpanel.scad` in OpenSCAD.

### Parameters

| Parameter | Default | Range | Description |
|---|---|---|---|
| `panel_width_type` | 1 (10") | 1-3 | Panel width: 1 = 10", 2 = 19", 3 = Demo split (60mm, narrow demo to spare material) |
| `height_units` | 1 | 1-8 | Panel height in rack units |
| `bore_mode` | 0 (Default) | 0-2 | Bore hole pattern |
| `panel_depth_type` | 1 (Regular) | 1-2 | Panel depth (wall thickness): 1 = Regular (2mm), 2 = Strong (4mm) |
| `back_brace` | false | true/false | Add a triangulated truss stiffener on the panel back, flush with the split-knuckle plane, see [Stiffening](#-stiffening-depth-vs-back-brace) |
| `back_brace_density` | regular | regular, dense | Truss band density when `back_brace` is on, `regular` = 1 band per unit, `dense` = 2 bands per unit (finer triangles, but noticeably more material) |
| `split_mode` | 0 (Full) | 0-1 | Print whole (Full) or split into halves (Half), see [Split Panels](#-split-panels) |
| `view_mode` | 0 (Assembled) | 0-3 | When split: assembled panel (pin seated), left half only, right half only, or exploded preview (halves apart + pin floating above) |
| `debug_colors` | false | true/false | Show distinct colors per section for debugging |
| `chamfer_enabled` | true | true/false | Apply chamfers to edges |

### Bore Modes

| Mode | Value | 1U | 2U | 3U+ |
|---|---|----|----|-----|
| Default | 0 | 2 bores/unit | 1 bore/unit | 1 bore/unit |
| All | 1 | 3 bores/unit | 3 bores/unit | 3 bores/unit |
| Minimal | 2 | 1 bore/unit | 1 bore top + bottom | 1 bore top + bottom, 0 inner |

### 💪 Stiffening: depth vs back brace

Two independent ways to make a panel stiffer, combine them for the most rigid result:

- **`panel_depth` (Strong, 4mm)**: thickens the whole skin. Because panels print face-down, depth is the vertical (Z) print direction, so the slicer fills the added volume with sparse gyroid infill: a deep panel becomes a cheap sandwich/I-beam that resists broad bending well. Stiffness scales with *your slicer's* infill settings, not the model.
- **`back_brace`**: a triangulated truss grown onto the **back**, protruding to the split-knuckle plane (so it stays flush with split connectors) while never touching the front face or its chamfer. Each cell carries a diagonal whose direction **alternates** in a checkerboard (a Warren/zigzag lattice), so it resists racking/torsion equally both ways instead of favouring one handedness, the kind of load gyroid infill handles poorly. On split panels each half gets its own framed sub-brace, mirrored about the centerline, with a clear gap for the connector. Bands scale with panel height so triangles stay a consistent size; columns auto-size for roughly square cells.

Rules of thumb: small panels rarely need either; wide (19") or tall multi-U panels benefit most from the brace; **`back_brace` + Minimal bore mode** is the lightest stiff combo. The brace's solid ribs are not free, `dense` density on a large panel can use more plastic than simply going to Strong `panel_depth` (which is mostly sparse infill), so prefer `regular` unless you need the extra rigidity. A panel already as deep as the knuckle plane gets no brace (it would not protrude).

> See [stiffen-rack-panels-with-truss-grid](../../docs/decisions/stiffen-rack-panels-with-truss-grid.md) for the rationale, and [lib/truss.scad](lib/truss.scad) for the generic lattice module.

#### 🧪 Real-world print test (19" 1U)

Four 19" 1U split panels printed back-to-back on a Bambu Lab X1C with identical HomeRacker default settings (3 walls, Arachne, 15 % gyroid, Bambu PLA Matte Charcoal), then hand-loaded in two ways: **shear** (twisting the center) and **bending** (flexing along the split seam).

19" panel stiffening specimens

| # | Config | Filament | Time | Shear (twist) | Bending (seam) |
|---|---|---:|-----:|---|---|
| 1 | 2 mm panel | 50.86 g | 1 h 19 m | weakest | weak |
| 2 | 4 mm panel | 63.09 g | 1 h 41 m | better | best broad stiffness |
| 3 | 2 mm + back brace | 83.48 g | 2 h 09 m | good | good |
| 4 | 4 mm + back brace | 85.78 g | 2 h 16 m | **best** | good |

Takeaways:

- **`back_brace` carries the torsion/shear load**: both braced panels (#3, #4) clearly beat the unbraced ones at twisting.
- **Strong (4 mm) `panel_depth` adds broad bending stiffness** cheaply (sparse infill), and combined with the brace gives the best all-round result for only ~2 g over the brace-only panel.
- **The `strong` split connector was removed.** Widening the hinge knuckles to a full base unit (specimen #2's original print) actually made the seam flex *more* and added material without improving stiffness, so the option no longer exists, the slim connector is now the only one. See [stiffen-rack-panels-with-truss-grid](../../docs/decisions/stiffen-rack-panels-with-truss-grid.md).

Best value: **4 mm `panel_depth` + `back_brace`** (slim connector).

### Variants

#### Default

| 1U | 2U |
|----|----|
| Default 1U | Default 2U |

#### All (Full)

| 1U | 2U |
|----|----|
| All 1U | All 2U |

#### Minimal

| 1U | 2U | 3U |
|----|----|----|
| Minimal 1U | Minimal 2U | Minimal 3U |

#### Back Brace (viewed from behind)

The triangulated stiffener grows on the panel **back**, flush with the split-knuckle plane, see [Stiffening](#-stiffening-depth-vs-back-brace). Each panel/half carries its own framed field; on a split panel the two halves mirror about the centerline with a clear gap for the connector and lock pin.

| 10" (regular) | 10" (dense) | 19" split |
|---|---|---|
| Brace 10" regular | Brace 10" dense | Brace 19" split |

### Module Architecture

```text
rackpanel          → orchestrator: bore mode logic, chamfering (edge_mask)
└─ rackpanel_stack → pure stacker: one zcopies of rackpanel_1u
   └─ rackpanel_1u → single 1U body with bore subtraction (no chamfer)
      └─ bores_1u  → 1-3 evenly spaced bores per unit
└─ bores_minimal   → 1-2 bores (top + bottom unit centers) for MINIMAL mode
```

See [lib/rackpanel.scad](lib/rackpanel.scad) for implementation.

### 🧩 Building on rack panels (children + usable frame)

`rackpanel` is BOSL2-attachable and **passes children through** on the Full, Left-half, and Right-half views, so a downstream model can add or subtract geometry against the panel face, e.g. drop in keystone jacks (each cuts its own pocket and leaves the jack body) with a `diff()` pass:

```scad
include <models/panel/lib/rackpanel.scad>
include <models/panel/lib/split.scad>
include <models/keystone/lib/keystone.scad>

diff("keystone")
rackpanel(split_mode=HR_RP_SPLIT_HALF, view_mode=HR_RP_VIEW_HALF_LEFT)
  align(FRONT, inside=true)
    right(get_rackpanel_usable_x(STD_WIDTH_10INCH, HR_RP_SPLIT_HALF, HR_RP_VIEW_HALF_LEFT))
      keystone_full(panel_depth=get_ks_depth_outer());
```

Children are emitted **outside** the internal `tag_scope`, so a `tag("keystone")` cutter survives to the enclosing `diff()`. `keystone_full()` already tags its own pocket as `"keystone"`, so call it **bare**, wrapping it in another `tag("keystone")` would turn the whole jack into a cutter (a hole, no body). A plain cuboid cutter, by contrast, does need the explicit `tag("keystone")`. The assembled/exploded views are preview-only and do not take children.

**Usable band**, a magenta marker the exact size of the cutout-safe band, attached to the panel **back** face so any overlap with a mount column is obvious. The split halves leave the central split-connector knuckle uncovered.

| Full panel | Split panel (assembled) |
|---|---|
| Usable band full | Usable band split |

**Keystone jacks**, a real `keystone_full` jack (shown in white via `debug_colors`) cut into a strong (4&nbsp;mm) braced panel. Front shows the installed socket; back shows the jack body protruding alongside the truss brace.

| | Front | Back |
|--|---|---|
| **Full panel** | Keystone on full, front | Keystone on full, back |
| **Split half** | Keystone on split, front | Keystone on split, back |

Two helper functions describe the cutout-safe band (the panel face minus the rackmount mount-surface columns and slide-in clearance):

| Function | Returns |
|---|---|
| `get_rackpanel_usable_width(panel_width, split_mode, view_mode)` | Usable band width (mm). Full: `panel_width − 2·STD_MOUNT_SURFACE_WIDTH − TOLERANCE`. Split half: `panel_width/2 − HR_SPLIT_KNUCKLE_STRENGTH_SLIM/2 − STD_MOUNT_SURFACE_WIDTH − TOLERANCE/2` (one outer column; the band stops at the central split-connector knuckle, which stays uncovered, so `2·half + knuckle = full`). |
| `get_rackpanel_usable_x(panel_width, split_mode, view_mode)` | X offset of the band centre from the (half-)panel centre (mm). Full: `0`. Left half: `+(STD_MOUNT_SURFACE_WIDTH/2 + TOLERANCE/4 − HR_SPLIT_KNUCKLE_STRENGTH_SLIM/4)`; right half: the negative, each half pins its band's seam edge on the knuckle boundary so cutouts stay aligned across the joint (overlap by `HR_EPSILON` to stay manifold). |

A split-aware consumer distributes its content left/right itself and calls `rackpanel` once per half; the library does **not** split content for you. See [rackpanel-usable-frame-helpers](../../docs/decisions/rackpanel-usable-frame-helpers.md).

## ✂️ Split Panels

A 19" rack panel (482.6mm) is wider than most printer beds. **Split mode** divides the panel along its vertical centerline into two halves that print separately and join into a rigid panel, no glue, no fasteners beyond a single lock pin.

### How it works

- **Split connector**: a hinge-like column of interlocking knuckles is grown onto the facing edge of each half (via `split_connector`). The two halves interleave like the leaves of a door hinge. Each height unit has **four knuckles**: a **lock knuckle** (a full HomeRacker base unit with a tension lock-pin socket) at each end, and two shorter **middle knuckles** (plain 4mm square holes) sharing the space between them. The layout is point-symmetric, both halves always own exactly two knuckles and the connector is identical whichever way you rotate it, so multi-unit panels simply stack identical units straight up.
- **Split lock pin**: the `split_lockpin` part threads vertically down the aligned knuckle bores like a hinge rod and locks the joint. It reuses the standard lock pin's tension grip as its single lock element, seated in the lock knuckle at **one extreme end** of the pin; a plain shaft (with a finished chamfered end) runs from the grip up through every remaining knuckle. Multi-unit pins keep the single grip and just extend the shaft.

### Print & assembly

1. Set `split_mode = 1` (Half) and print each half, use `view_mode = 1` (Left) and `view_mode = 2` (Right). `view_mode = 0` (Assembled) previews the finished panel with the lock pin seated, and `view_mode = 3` (Exploded) shows how the two halves and the pin fit together, neither is a print layout. The hinge knuckles are generated automatically as part of each half; `parts/split_connector.scad` exposes the bare connector standalone for preview and inspection.
2. Print the matching **Split Lock Pin** (`parts/split_lockpin.scad`) at the same `height_units`.
3. Interleave the two halves' hinge knuckles and slide the lock pin down through the aligned bores until it seats.

> ⚠️ **Warping & thick parts**: Thick panels printed on their edge (Strong 4&nbsp;mm `panel_depth`) warp more easily, the effect is worse on textured PEI plates and toward the bed edges, where heating is less even. A warped split seam can stop the lock pin from inserting. Anecdote: on a Bambu Lab X1C (256&nbsp;mm bed) with Bambu PLA Matte (Charcoal) and typical HomeRacker settings (3 walls, 15&nbsp;% gyroid, Arachne wall generation), a 4&nbsp;mm `panel_depth` half warped near the bed edge and the pin would not seat. Fix: print one part at a time, laid diagonally for extra edge clearance. Larger printers are less likely to hit this.

### Parameters

**Split Connector** (`parts/split_connector.scad`)

| Parameter | Default | Range | Description |
|---|---|---|---|
| `height_units` | 1 | 1-8 | Connector height in rack units (match the split panel) |
| `knuckle_side` | all | all, left, right | Which knuckles to keep: both halves, or a single panel half's two knuckles |
| `debug_colors` | false | true/false | Show distinct colors per section for debugging |
| `chamfer_enabled` | true | true/false | Chamfer the knuckle edges |

**Split Lock Pin** (`parts/split_lockpin.scad`)

| Parameter | Default | Range | Description |
|---|---|---|---|
| `height_units` | 1 | 1-8 | Match the split panel this pin locks |
| `debug_colors` | false | true/false | Show distinct colors per section for debugging |
| `chamfer_enabled` | true | true/false | Chamfer the insertion ends |

### Variants

| Split Panel (2U, 19") | Split Connector (1U) | Lock Pin (1U) | Lock Pin (2U) |
|---|---|---|---|
| Split Panel 2U | Split Connector | Split Lock Pin 1U | Split Lock Pin 2U |

To generate or refresh the renders (full F6 renders via `scadm export-png`):

```sh
scadm export-png models/panel/parts/split_connector.scad
scadm export-png models/panel/parts/split_lockpin.scad
scadm export-png models/panel/parts/split_lockpin.scad -D height_units=2 --output models/panel/parts/renders/split_lockpin_2u.png
scadm export-png models/panel/parts/rackpanel.scad -D panel_width_type=2 -D height_units=2 -D split_mode=1 -D view_mode=3 --output models/panel/parts/renders/rackpanel_split_2u_19inch.png
```

### Module Architecture

```text
split_connector   → 4-knuckle hinge column per unit (lock + 2 middle + lock), stacked straight up
└─ knuckle        → single knuckle: lock (tension socket) or middle (4mm square bore)
split_lockpin     → hinge-rod pin: single tension grip at one end + plain shaft through the rest
├─ split_lockpin_grip  → tension element (flex-slit grip) that seats in the bottom lock knuckle
└─ split_lockpin_shaft → plain shaft with a filleted + chamfered outer end
```

See [lib/split.scad](lib/split.scad) for implementation.

## 🧭 Anchoring Behavior

The `panel()` module is fully BOSL2-attachable. Its bounding box encompasses all mount surfaces, **not** the Full Cover base plate. This means anchors align with the functional mounting geometry, making it straightforward to position child components (e.g. keystone jacks, switches) relative to the actual panel area.

### Inter-Fit Panels

Anchors align directly with the panel's base plate + mount surfaces. The bounding box extends `BASE_STRENGTH` beyond the base plate on each side that has support mount plates (i.e. when units > 2 on that axis). The extension is always symmetric, disabling individual mount surfaces does not shrink or shift the bounding box.

### Full Cover Panels

On Full Cover panels, the overlap base plate is larger than the mount surface bounding box. **Anchors intentionally do not align with the Full Cover plate edges**. They align with the mount plate boundaries instead. This is the correct behavior because:

- Child components (cutouts, jacks) should align with the structural panel area, not the cosmetic overlap.
- Using `align(BACK+BOTTOM)` on a Full Cover panel positions the child at the mount plate's back edge, exactly where the support bar sits, maximizing usable space.

Full Cover Panel Anchors

> 💡 **Example**: A keystone jack attached with `align(BACK,BOTTOM,inside=true)` perfectly aligns with the support plate edge, making optimal use of the panel's vertical space without intersecting the scaffold structure.

### Stable Anchors

Anchors remain fixed regardless of which mount surfaces are enabled or disabled. Disabling a mount plate (e.g. `mount_west=false`) removes the plate geometry but does **not** shift the bounding box or anchor positions. This ensures children attached via `align()` stay in a predictable position, aligned with the support bar boundary, even when mount plates are selectively disabled.

## 📚 References

- [HomeRacker core](../core/README.md)

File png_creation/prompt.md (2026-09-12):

# --- Gemini Agent Prompt: Create Tool Silhouette ---

**ROLE:** You are an expert image processing agent. Your sole function is to create a clean, solid black silhouette from a user-provided image of a tool.

**TASK:** Analyze the attached image and generate a PNG file that meets the precise output requirements below. This PNG will be used as a source for a vector tracing program (Potrace), so precision is critical.

**INPUT:**
- An image file of a single tool lying on a high-contrast background.

**OUTPUT REQUIREMENTS:**
1.  **Format:** PNG with a transparent background.
2.  **Content:** A silhouette representing the **single, continuous, outermost contour only**. All internal holes, lines, and details must be completely filled in.
3.  **Color:** The silhouette must be 100% solid black (`#000000`). No anti-aliasing or grey pixels.
4.  **Cropping:** The final image must be tightly cropped around the silhouette with minimal transparent padding.

**ACTION:** Process the attached photo and provide only the resulting PNG file as your output.

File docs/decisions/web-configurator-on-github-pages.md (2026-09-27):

# 📋 Web Configurator on GitHub Pages

## 📌 Status

**Accepted**, 2026-09-02

## 🤔 Context

The README asks builders to "make a parts list" by hand: supports per length, connectors per type, lock pins. Nothing in the repo does that math, and the only site is the README rendered by the classic Jekyll Pages build at `homeracker.org`.

A configurator needs a place to live, a toolchain, a way to publish, and a preview strategy.

### Alternatives Considered

| Approach | Verdict | Reason |
|---|---|---|
| Separate `homeracker-configurator` repo | ❌ Rejected | Geometry rules drift from the `.scad` sources; second release train |
| Plain ES modules without a build step | ❌ Rejected | No type checking, no unit tests for the parts-list math |
| UI framework (React/Svelte) | ❌ Rejected | Form + table + canvas does not justify the dependency weight |
| Real part meshes rendered in CI | ⏳ Deferred | Heavy asset pipeline before anything is usable; schematic boxes are enough to sanity-check a layout |
| Commit built `dist/` to keep branch-based Pages | ❌ Rejected | Generated code in git, noisy PRs |

## 🔧 Decision

- **Location**: `configurator/` in this repo, published at `https://homeracker.org/configurator/`.
- **Stack**: Vite + TypeScript + Three.js, Vitest for tests, no UI framework.
- **Engine/render split**: `src/engine/` is pure (no DOM, no Three.js) and holds every geometry rule and the bill of materials; enforced by a separate `tsconfig.engine.json` and an eslint import restriction. `src/render/` and `src/ui/` are thin.
- **Preview**: real part meshes exported from the OpenSCAD sources at site build time (connectors per type and pull-through axis, supports per length, lock pins, feet), placed with a rotation solver that mirrors `CONNECTOR_CONFIGS`; schematic unit boxes remain as the fallback when the mesh library is not served. Panels stay schematic. (Updated 2026-09-02; the first version drew boxes only.)
- **Sharing**: the config is encoded in the URL hash (`#v=4&d=6&r=5:6_4:6&f=1`); no backend.
- **Deploy**: `pages.yml` builds the site and the Vite app and deploys both with `actions/deploy-pages`; the app lands under `/configurator/`. Pages source must be set to **GitHub Actions** once. (Superseded detail: the first version kept the Jekyll README build; see [astro-site-replaces-jekyll](astro-site-replaces-jekyll.md).)
- **CI**: the `Web` workflow (`web.yml`) lints, tests and builds on PRs touching `configurator/**`; a local pre-commit hook runs the same `npm run check`. The `site` job also runs the Playwright suite, see [e2e-test-site-and-configurator-with-playwright](e2e-test-site-and-configurator-with-playwright.md).

### Geometry rules encoded

- Nodes on an integer lattice; a support between nodes `a < b` has length `b - a - 1`, so `3 + connector + 3 = 7 units`.
- A rack is a stack of rows, each with its own height, column widths and horizontal shift; frames between rows carry the column boundaries of both neighbouring rows, so dividers that stop end in T connectors (added 2026-09-02 after the level editor proved unintuitive).
- Connector type = (axes used, arm count), matching `CONNECTOR_CONFIGS`. A row whose posts continue from the row below turns that junction into z pull-through connectors and one long support (per junction since 2026-09-02; before that one switch for the whole rack).
- One lock pin per occupied arm; feet occupy the `-z` arm of every floor node.
- A panel fills the opening bounded by its supports (`units_x = support length`), derived from `panel.scad`'s inter-fit deduction. Panels are configured per opening (front/back bays per row, sides per row, spans of every frame including shelves), in to-scale face drawings (front, back, sides, and a plan per frame) or by clicking the opening in the 3D view, with hover synced both ways; each drawing has all-open/inter-fit/full-cover shortcuts. Panel geometry in the preview is assembled from exported mount plates and corner brackets around a plate, mirroring `panel()`, because exporting every panel size would take an hour per build. Panel pins are an estimate and listed separately. (Per-opening panels added 2026-09-02; before that one panel type applied to a whole face.)

## 📊 Consequences

- **Positive**: parts list is computed, testable and shareable by link; geometry rules live next to the models they mirror
- **Positive**: README site is unchanged; the configurator is an additive path
- **Negative**: first JS toolchain in the repo (Node in CI and pre-commit, Renovate npm updates)
- **Negative**: Pages source setting must be flipped by an admin; until then the deploy job fails
- **Next**: per-part STL export in the browser via openscad-wasm from `models/*/flattened/*.scad`

## 📚 References

- [configurator/README.md](../../configurator/README.md)
- [models/core/lib/connector.scad](../../models/core/lib/connector.scad): `CONNECTOR_CONFIGS`
- [models/panel/lib/panel.scad](../../models/panel/lib/panel.scad): inter-fit deduction
- [image-hosting-assets-repo](image-hosting-assets-repo.md): why the app ships no image files

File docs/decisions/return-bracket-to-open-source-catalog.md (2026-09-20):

# 📋 Return the bracket to the open-source catalog and retire flexmount

## 📌 Status

**Accepted**: 2026-09-20

## 🤔 Context

- Flexmount was this repo's open-source universal device mount. It was deprecated once the closed Unimount on MakerWorld took over the job, which left HomeRacker without a device mount anyone could build from source.
- The part that replaced it is the bracket, and it sat in `homeracker-exclusive` as `models/lib/bracket.scad`, reachable only through Unimount.
- A bracket is a single printable part, usable on its own or as one half of a larger mount. It belongs in the catalog next to the other building blocks.

## 🔧 Decision

- Move the bracket into `homeracker` as `models/bracket/`, MIT-licensed, following the standard lib/parts/test/README layout. This restores in support what flexmount used to provide.
- Delete `models/flexmount/`. The bracket supersedes it, and keeping a deprecated model beside its replacement only splits attention. Its history stays in git, and the MakerWorld listing its README pointed at is unaffected.
- The public entrypoint is `bracket()`, the full printable part. `bracket_shell()`, `bracket_mount()` and `bracket_mount_pair()` expose the halves.
- The rackmount flush distance becomes a plain `mount_offset_y` and the `MOUNT_VAR_*` flag disappears, because the offset is a distance, not a variant. `homeracker-exclusive` computes it and passes it in. MakerWorld `VIEW_*` plate modes stay there too.
- Mount column count derives from geometry (two columns once the grid spacing clears one wing footprint) rather than from the rackmount threshold constants it used before.
- Rejected: keeping a thin shim in `homeracker-exclusive`. Two files describing one part invites drift, and the glue it would hold is three lines.
- Rejected: leaving flexmount in place as deprecated. It has had no maintenance path since its successor went closed, and now that the successor is open there is nothing left for it to document.

## 📊 Consequences

- HomeRacker has a device mount in source again, buildable without a MakerWorld licence.
- Unimount keeps its geometry byte for byte, verified by STL volume and bounding box across 94 parameter permutations against the closed original.
- `homeracker-exclusive` now depends on a released `homeracker` version that contains the bracket, so its `scadm.json` pin has to move before its flattened exports rebuild.
- In automatic mode the second mount column now appears from 45mm of device depth rather than 49mm, because the threshold follows the wing footprint instead of a reused rackmount constant. `homeracker-exclusive` pins the count explicitly, so Unimount is unaffected.
- A device whose width lands exactly on the 15mm grid once reserved a whole extra rack unit, because the wing widening was computed without wrapping at zero. The wings now take their width from the support span rounded up to the grid. This narrows the part by one unit at widths of `15n - 0.2mm`, Unimount included, and leaves every other width as it was.
- Five inputs that used to render broken, empty or pointless geometry now fail an assertion naming the value that works: minimum device height, minimum device depth, maximum mount offset, a forced second column that would not fit, and a shell strength below one wall thickness.
- The attachable bounding box covers the shell only, not the mount wings. Callers placing parts near the wings position them by hand.
- Anyone following an old link to `models/flexmount/` lands on a 404 until they find the bracket.

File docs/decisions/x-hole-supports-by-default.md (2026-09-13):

# 📋 Use supports with lock pin holes on both axes

## 📌 Status

**Accepted**: 2026-09-13

## 🤔 Context

`support()` takes an `x_holes` flag. Without it a support carries one set of lock pin holes, running across a single axis; with it there is a second set across the other axis.

A panel hangs on the holes of the supports that bound its opening. Its mount plates and corner brackets lie on the face a support turns towards the opening, and each hole runs across that face, so the axis a panel needs depends on the face it sits on:

- a front or back panel needs vertical holes along its top and bottom edges, and sideways holes through the posts along its left and right edges
- a shelf or top panel needs sideways holes in all four bounding supports

One set of holes serves one of those directions. The configurator exported plain supports and pinned everything along the single available axis, which left the panels it drew unfastened on half their edges.

## 🔧 Decision

Export and list every support with `x_holes=true`.

The alternative was to pick the variant per support, from the panels that touch it. It was rejected for now: it adds a second support part to every parts list, doubles the exported mesh library, and needs a rule for supports that end up in both roles, in return for holes nobody is forced to use.

Load bearing is the reason to revisit this. A second set of holes takes material out of the middle of every unit, and a support carrying a heavy shelf may prefer to keep it. When that case comes up, the choice becomes per support rather than a project-wide default.

## 📊 Consequences

- Every panel mount the configurator draws has a hole to pin to, on every edge.
- One support part instead of two, in the mesh library and in the parts list.
- The two holes of a cell cross in its middle, so a cell still takes only one pin. Where a front panel and a side panel meet at the same corner cell, one of the two corners stays unpinned; the configurator gives the pin to the axis that holds more brackets (`configurator/src/engine/pins.ts`).
- Supports are slightly weaker than the single-hole variant and take marginally longer to print.
- Anyone who has already printed plain supports can still use them; the second hole matters only where a panel is mounted.

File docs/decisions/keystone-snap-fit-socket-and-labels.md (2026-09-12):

# 📋 Build the keystone module as a measured snap-fit cutter with an original label system

## 📌 Status

**Accepted**, 2026-06-18

## 🤔 Context

HomeRacker panels needed a reusable way to host standard keystone jacks (Ethernet, HDMI, USB, coax, fiber) without re-deriving snap-fit geometry in every panel model.

- The universal keystone profile is a known quantity, but there was no on-system parametric
  source, only third-party STLs.
- Real panels populate many identical jacks, so render/export cost matters.
- Users print on different printers/filaments, which shrink differently.
- Ports need durable, changeable identification.

## 🔧 Decision

Ship a parametric **cutter** module (`keystone_full()`) that panels subtract in a `diff("keystone")` context, plus a standalone `label_plate()`.

- **Dimension provenance:** measure the socket profile from Paul Hatcher's CC0
  [Parametric Keystone Connector](https://www.printables.com/model/537480-parametric-keystone-connector).
  That STL printed and fit a wide range of real jacks (e.g. deleyCON CAT.7); the distances
  were measured in the slicer and translated into SCAD. Label dimensions instead derive from
  HomeRacker core constants (`KS_LABEL_HEIGHT = BASE_UNIT`, etc.) to stay on-system.
- **Original label system:** snap-fit retention with a minimal lip overlap (holds against
  vibration without fighting removal), generous top/bottom chamfers for fingernail removal,
  and a double-slit slot so the part bridges support-free and labels print face-down for clean
  multicolor prints. `label_plate_mode = "plate"` lays the plate out print-ready for the
  Parametric Model Maker / MakerWorld build plates.
- **Fit knob:** `additional_tolerance` adds clearance to socket width & height only, default
  `0.0` (perfect on the reference printer). A single-jack sample (`keystone_sample.scad`) lets
  users fit-test cheaply before printing a full panel.
- **Dual geometry backend:** keep both a `native` (BOSL2-free, cache-friendly, fast) and a
  `bosl2` (authored source of truth, per-section debug colors) path behind a `$ks_native`
  toggle. `native` is the default; the native code was AI-transpiled from the BOSL2 source and
  print-tested with no noticeable difference. The native geometry lives in a separate
  `keystone_native.scad` pulled in via `use <>` (not `include`) and **without** an
  `include <BOSL2/std.scad>`, so its `cube()`/`linear_extrude()`/`polygon()` calls resolve to
  OpenSCAD's built-in primitives in that file's own scope, *not* BOSL2's attachable wrappers,
  even though the consuming `keystone.scad` includes BOSL2. This is what lets OpenSCAD cache one
  jack's mesh and re-stamp it across the panel.

**Benchmark** (synthetic 6×5 = 30-jack panel with labels, rendered to STL, manifold backend, median of 3 runs, AMD Ryzen 9 7950X / 64 GB / Windows, OpenSCAD 2026.06.12, single-threaded geometry): `native` **0.17 s** vs `bosl2` **1.0 s**, ≈ **6×** faster, with a per-jack marginal cost of ~5.4 ms (native) vs ~32 ms (bosl2). The 6× win empirically confirms the `use <>`-scoping trick keeps the primitives native (a BOSL2-wrapped `cube()` would defeat the cache and erase the gap). Reproduce with `_visual_test/ks_bench.scad`.

**Alternatives considered:**

- *Hard-code keystone geometry per panel*, rejected: duplicates snap-fit math and drifts.
- *Bake labels into the panel*, rejected: labels can't be changed after printing.
- *Ship dust covers / blank fillers / angled / shuttered variants*, rejected as out of scope;
  these exist en masse online. The module covers the standard snap profile only.
- *BOSL2-only geometry*, rejected for production rendering: `attachable`/`diff` defeats
  OpenSCAD's geometry cache and re-evaluates per copy, dominating render time on full panels.
- *Native-only geometry*, rejected: loses the readable authored source and fine debug colors.

## 📊 Consequences

**Positive:**

- Any panel becomes a patch panel by subtracting one module.
- Real jacks fit out of the box; the sample de-risks full-panel prints.
- Labels are durable, changeable, and print cleanly without supports.
- Fast default rendering on populated panels, with a readable fallback for editing/debugging.

**Negative:**

- Two geometry paths must stay in sync; the native path is AI-transpiled, so the `bosl2`
  backend remains the source of truth for correctness.
- `additional_tolerance` values much above `0.2` are untested.
- Only standard keystones are supported; specialty jacks are out of scope.

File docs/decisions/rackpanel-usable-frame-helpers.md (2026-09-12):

# 📋 Expose rack-panel usable-frame helpers and child passthrough

## 📌 Status

**Accepted**, 2026-06-19

## 🤔 Context

Specialized panels (keystone strips/grids, switch/display cutouts) need to add or subtract geometry on a `rackpanel` face, including its **split** halves. Two problems blocked building on top of `rackpanel`:

- It did not accept external children, the dispatch called the internal view modules
  (`_naked_panel`, `_panel_left`, `_panel_right`) directly and never propagated
  `children()`. The Full view's `children()` also sat *inside* `tag_scope("rackpanel")`,
  so any `tag("keystone")` cutter would have its remove-tag scoped away and never cut.
- Consumers had no way to know the **cutout-safe band**: the panel face minus the
  rackmount mount-surface columns (and the slide-in clearance), which differs between a
  full panel and a split half (a half has a mount column only on its outer edge).

## 🔧 Decision

Keep the split-distribution logic **out** of the library; expose just enough for a consumer to drive it:

- **Child passthrough** on the three child-accepting views (Full, Left-half, Right-half)
  via one outer `attachable` that emits `children()` *outside* the internal `tag_scope`,
  so `diff("keystone")` cutters survive. The single active branch is merged with `union()`
  into one shape node; the outer wrapper also applies `anchor/spin/orient` uniformly
  (previously honored only on the Full view). Assembled/exploded views stay preview-only
  and take no children.
- **`get_rackpanel_usable_width(panel_width, split_mode, view_mode)`**: usable band width.
  Full: `panel_width − 2·STD_MOUNT_SURFACE_WIDTH − TOLERANCE`. Split half:
  `panel_width/2 − HR_SPLIT_KNUCKLE_STRENGTH_SLIM/2 − STD_MOUNT_SURFACE_WIDTH − TOLERANCE/2`
  (one outer column; the band stops at the central split-connector knuckle, which stays
  uncovered, so `2·half + knuckle = full`).
- **`get_rackpanel_usable_x(panel_width, split_mode, view_mode)`**: X offset of the band
  centre from the (half-)panel centre. Full: `0`. Left half:
  `+(STD_MOUNT_SURFACE_WIDTH/2 + TOLERANCE/4 − HR_SPLIT_KNUCKLE_STRENGTH_SLIM/4)`, right half
  the negative, each half pins its band's **seam edge on the knuckle boundary** so cutouts
  stay aligned across the joint (a consumer overlaps by `HR_EPSILON` to stay manifold).

Alternatives considered:

- **Library splits content itself** (pass a list of cutouts, it distributes L/R), rejected:
  couples the panel to consumer semantics (keystone counts, rotations, labels) and bloats
  the parameter surface. The consumer calls `rackpanel` once per half instead.
- **Return a usable bounding box / anchors instead of width+x**: rejected as overkill;
  width + centre offset is the minimum a consumer needs and keeps the helpers pure.
- **Half-unit panels** (a half-height split) were considered for fit-to-frame layouts and
  **deferred**: the split-connector geometry is not designed to be halved that way and
  would need rework not justified for an edge case.

## 📊 Consequences

- ➕ Downstream models (e.g. exclusive keystone rack panels) can `diff()` against full or
  split rackpanels and place cutouts with seam-consistent alignment using two pure helpers.
- ➕ Both helpers `echo()` a warning when called with `split_mode=Half` and a non-half view
  (Assembly/Exploded), an undefined combination, and fall back to the full-panel band / 0
  rather than failing silently.
- ➕ `anchor/spin/orient` now apply on every child-accepting view, not just Full.
- ➕ Split distribution stays a consumer concern, the library surface stays small.
- ➕ Usage is documented by committed one-scene-per-file demos in `models/panel/demo/`
  (rendered to `demo/renders/*.png` for the README): the usable band is shown as a magenta
  marker on the panel **back** face (so any overlap with a mount column is obvious), and the
  keystone demos cut a real `keystone_full` jack into a strong (4&nbsp;mm) braced panel.
  Functional asserts stay in `models/panel/test/` (CI); the demos are visual reference.
- ➖ Consumers must call `rackpanel` twice for a split assembly and route the correct
  cutouts to each half (the library will not do it for them).
- ➖ `keystone_full()` self-tags its pocket as `"keystone"`, so it must be called **bare**
  inside `diff("keystone")` (an outer `tag("keystone")` would turn the whole jack into a
  hole). Plain cuboid cutters still need the explicit tag, a subtle asymmetry to remember.
- ➖ The helpers assume the standard mount-surface column on outer edges; a future
  custom-mount panel would need its own band math. Unlikely as we're talking standard rackmount panels.

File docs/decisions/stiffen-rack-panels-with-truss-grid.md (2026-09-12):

# 📋 Stiffen rack panels with a generic truss grid

## 📌 Status

**Accepted**, 2026-06-19

## 🤔 Context

Large rack panels (19", multi-U) flex under load. We needed a way to add stiffness without a wholesale redesign, and had to decide *how* to add it:

- FDM panels print **face-down**, so panel depth is the vertical (Z) print direction.
  Increasing `panel_depth` adds volume that the slicer fills with sparse gyroid infill,
  cheap broad bending resistance (a sandwich/I-beam), but stiffness depends on the user's
  infill settings and gyroid resists **torsion/racking** poorly.
- Split panels already grow knuckles to a back depth of `HR_SPLIT_KNUCKLE_STRENGTH_SLIM`
  (8.8mm). Any structure that stays within that envelope is "free", it adds no bounding
  footprint beyond what the connector already claims.

We also had to decide whether the stiffener should be panel-specific or reusable, and how it should behave on split panels (where a centerline connector interrupts the back face).

## 🔧 Decision

Add an **optional back-side truss stiffener** built from a new **generic, dimension-driven** module `models/panel/lib/truss.scad` (`truss_grid`):
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

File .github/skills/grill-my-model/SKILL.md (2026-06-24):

---
name: grill-my-model
description: >
  Relentlessly interview the creator of a HomeRacker OpenSCAD model about every
  design decision, then fold the answers into the model's documentation. Use this
  skill during planning of a new model, or after a model (or a change to one) is
  built, to pressure-test the design and produce the most comprehensive yet concise
  docs possible.
  USE FOR: grilling a model's parameters/defaults/geometry/print choices, filling
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

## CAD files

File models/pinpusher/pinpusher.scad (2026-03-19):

// HomeRacker - Lockpin Pusher
//
// A simple tool to push lockpins out of connectors.
// The shaft fits through lockpin holes; the grip provides
// a pinch surface for thumb and index finger.
//
// This model is part of the HomeRacker - Utility system.
//
// MIT License
// Copyright (c) 2026 Patrick Pötz
//
// Permission is hereby granted, free of charge, to any person obtaining a copy
// of this software and associated documentation files (the "Software"), to deal
// in the Software without restriction, including without limitation the rights
// to use, copy, modify, merge, publish, distribute, sublicense, and/or sell
// copies of the Software, and to permit persons to whom the Software is
// furnished to do so, subject to the following conditions:
//
// The above copyright notice and this permission notice shall be included in all
// copies or substantial portions of the Software.
//
// THE SOFTWARE IS PROVIDED "AS IS", WITHOUT WARRANTY OF ANY KIND, EXPRESS OR
// IMPLIED, INCLUDING BUT NOT LIMITED TO THE WARRANTIES OF MERCHANTABILITY,
// FITNESS FOR A PARTICULAR PURPOSE AND NONINFRINGEMENT. IN NO EVENT SHALL THE
// AUTHORS OR COPYRIGHT HOLDERS BE LIABLE FOR ANY CLAIM, DAMAGES OR OTHER
// LIABILITY, WHETHER IN AN ACTION OF CONTRACT, TORT OR OTHERWISE, ARISING FROM,
// OUT OF OR IN CONNECTION WITH THE SOFTWARE OR THE USE OR OTHER DEALINGS IN THE
// SOFTWARE.

// Note: this is just a makeshift solution. Not 100% happy with it but it'll do for now.

include <BOSL2/std.scad>
include <../core/lib/constants.scad>

/* [Hidden] */
$fn = 100;

pusher_length = BASE_UNIT + BASE_STRENGTH * 2 + TOLERANCE;
pusher_side = LOCKPIN_HOLE_SIDE_LENGTH - TOLERANCE;

grip_width = BASE_UNIT/2;
grip_mid_width = grip_width - BASE_STRENGTH;
grip_depth = BASE_UNIT / 2;

/**
 * 📐 pinpusher module
 *
 * Creates a lockpin pusher tool for the HomeRacker system.
 * Lies flat for optimal printing. Shaft pushes lockpins out of connectors.
 * Prismoid grip for pinching between thumb and index finger.
 */
module pinpusher() {
  color(HR_YELLOW)
  xrot(90)
  prismoid(
    size1 = [grip_width, grip_width],
    size2 = [grip_mid_width, grip_mid_width],
    h = grip_depth,
    shift = [0, -BASE_STRENGTH/2],
    chamfer = BASE_CHAMFER,
  )
  attach(TOP, BOTTOM)
  prismoid(
    size1 = [grip_mid_width, grip_mid_width],
    size2 = [grip_width, grip_width],
    shift = [0, BASE_STRENGTH/2],
    h = grip_depth,
    chamfer = BASE_CHAMFER
  )
  align(TOP, FRONT)
  cuboid(
    [pusher_side, pusher_side, pusher_length],
    chamfer = BASE_CHAMFER,
    edges = [LEFT,RIGHT],
    except = [BOTTOM,TOP]
  );
}

pinpusher();

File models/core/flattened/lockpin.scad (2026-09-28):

include <BOSL2/std.scad>

/* [Parameters] */

// Type of grip for the lock pin
grip_type = 0;  // [0:Standard, 1:Extended, 2:No Grip]

// Neck extension mode
neck_extension = 0;  // [0:None, 1:Neck Side, 2:Both Sides, 3:Tail Side]

// Strength of the tension hole (affects how much material is removed for the hole, which in turn affects the flexibility and strength of the lock pin)
strength = 0;  // [0:Regular, 1:Slim]

/* [Debug Parameters] */
// Show distinct colors per section for easier debugging
debug_colors = false;  // [false,true]
// Enable chamfering on the insertion ends
chamfer_enabled = true;  // [false,true]

/* [Hidden] */
// --- from constants.scad ---
HR_EPSILON = 0.01;
TOLERANCE = 0.2;
PRINTING_LAYER_WIDTH = 0.4;
BASE_UNIT = 15;
BASE_STRENGTH = 2;
LOCKPIN_HOLE_SIDE_LENGTH = 4;
LP_GRIP_STANDARD = 0;
LP_GRIP_EXTENDED = 1;
LP_GRIP_NO_GRIP = 2;
LP_NECK_EXT_NONE = 0;
LP_NECK_EXT_NECK = 1;
LP_NECK_EXT_BOTH = 2;
LP_NECK_EXT_TAIL = 3;
LP_NECK_EXTENSION_UNIT = BASE_STRENGTH + TOLERANCE / 2;
HR_YELLOW = "#f7b600";
HR_BLUE = "#0056b3";
HR_RED = "#c41e3a";
HR_GREEN = "#2d7a2e";
// --- from lockpin.scad ---
lockpin_chamfer = PRINTING_LAYER_WIDTH;
lockpin_width_outer = LOCKPIN_HOLE_SIDE_LENGTH;
lockpin_width_inner = LOCKPIN_HOLE_SIDE_LENGTH + PRINTING_LAYER_WIDTH * 2;
lockpin_height = lockpin_width_outer - TOLERANCE;
lockpin_prismoid_length = (BASE_UNIT - BASE_STRENGTH) / 2;
lockpin_endpart_length = BASE_STRENGTH + BASE_STRENGTH / 2 + TOLERANCE;
grip_width = lockpin_width_outer + BASE_STRENGTH * 2;
grip_thickness_inner = PRINTING_LAYER_WIDTH * 2;
grip_thickness_outer = BASE_STRENGTH / 2;
grip_distance = BASE_STRENGTH / 2;
grip_base_length = grip_thickness_inner + grip_thickness_outer + grip_distance + lockpin_chamfer + TOLERANCE / 2;
HR_CORE_LOCKPIN_PRIMARY_COLOR = HR_YELLOW;
HR_CORE_LOCKPIN_TENSION_HOLE_STRENGTH_REGULAR = 4;
HR_CORE_LOCKPIN_TENSION_HOLE_STRENGTH_SLIM = 6;
$fn = 100;

// --- Examples ---

// Example 1: Create a default lock pin (uses default grip_type)
// lockpin();

// Example 2: Create a lock pin with no grip
// lockpin(grip_type=LP_GRIP_NO_GRIP);

// Example 3: Create a lock pin with neck extension for panel mounting
// lockpin(neck_extension=LP_NECK_EXT_NECK);

// Example 4: Create a lock pin with grip_type and neck_extension as set above

tension_hole_strength_multiplier = strength == 0 ? HR_CORE_LOCKPIN_TENSION_HOLE_STRENGTH_REGULAR :
  strength == 1 ? HR_CORE_LOCKPIN_TENSION_HOLE_STRENGTH_SLIM :
  die(str("Invalid strength value: ", strength));
module lockpin(grip_type = LP_GRIP_STANDARD, neck_extension = LP_NECK_EXT_NONE,
  strength = HR_CORE_LOCKPIN_TENSION_HOLE_STRENGTH_REGULAR,
  debug_colors = false, chamfer_enabled = true
) {
  rotate([90, 0, 0])
    difference() {

      union() {

        color_this(debug_colors ? HR_BLUE : HR_CORE_LOCKPIN_PRIMARY_COLOR)
          tension_shape(chamfer_enabled);

        color_this(debug_colors ? HR_GREEN : HR_CORE_LOCKPIN_PRIMARY_COLOR)
          end_parts(grip_type, neck_extension, chamfer_enabled);

        color_this(debug_colors ? HR_BLUE : HR_CORE_LOCKPIN_PRIMARY_COLOR)
          neck(neck_extension, grip_type, chamfer_enabled);

        color_this(debug_colors ? HR_YELLOW : HR_CORE_LOCKPIN_PRIMARY_COLOR)
          grip(grip_type, neck_extension, chamfer_enabled);
      }

      color_this(debug_colors ? HR_RED : HR_CORE_LOCKPIN_PRIMARY_COLOR)
        tension_hole(strength);
    }
}
module grip(grip_type = LP_GRIP_STANDARD, neck_extension = LP_NECK_EXT_NONE, chamfer_enabled = true) {
  if (grip_type != LP_GRIP_NO_GRIP) {
    has_neck_ext = neck_extension == LP_NECK_EXT_NECK || neck_extension == LP_NECK_EXT_BOTH;
    grip_side_extension = has_neck_ext ? LP_NECK_EXTENSION_UNIT : 0;
    grip_base_dimensions = [lockpin_width_outer, lockpin_height, grip_base_length];
    grip_outer_dimensions = [grip_type == LP_GRIP_EXTENDED ? grip_width * 1.5 : grip_width, lockpin_height, grip_thickness_outer];
    grip_inner_dimensions = [grip_width, lockpin_height, grip_thickness_inner];

    base_translation = lockpin_prismoid_length + lockpin_endpart_length - lockpin_chamfer - TOLERANCE / 2 + grip_side_extension;

    union() {

      translate([0, 0, -base_translation - grip_base_length / 2])
        cuboid(grip_base_dimensions, chamfer = chamfer_enabled ? lockpin_chamfer : 0, except = TOP);

      if (grip_type == LP_GRIP_STANDARD || grip_type == LP_GRIP_EXTENDED) {
        translate([0, 0, -base_translation - grip_base_length + grip_thickness_outer / 2])
          cuboid(grip_outer_dimensions, chamfer = chamfer_enabled ? lockpin_chamfer : 0, edges = BOTTOM);

        translate([0, 0, -base_translation - grip_base_length + grip_thickness_outer + grip_thickness_inner / 2 + grip_distance])
          cuboid(grip_inner_dimensions, chamfer = chamfer_enabled ? lockpin_chamfer : 0, edges = BOTTOM);
      }
    }
  }
}
module neck(neck_extension = LP_NECK_EXT_NONE, grip_type = LP_GRIP_STANDARD, chamfer_enabled = true) {
  lockpin_fillet = lockpin_width_outer / 3;
  neck_dimensions = [lockpin_width_outer, lockpin_height, LP_NECK_EXTENSION_UNIT];
  neck_z = lockpin_prismoid_length + lockpin_endpart_length - TOLERANCE / 2 + LP_NECK_EXTENSION_UNIT / 2;
  has_neck_ext = neck_extension == LP_NECK_EXT_NECK || neck_extension == LP_NECK_EXT_BOTH;
  has_tail_neck = neck_extension == LP_NECK_EXT_TAIL || neck_extension == LP_NECK_EXT_BOTH;

  if (has_neck_ext) {
    translate([0, 0, -neck_z])
      if (grip_type != LP_GRIP_NO_GRIP) {

        cuboid(neck_dimensions, chamfer = chamfer_enabled ? lockpin_chamfer : 0, except = [TOP, BOTTOM]);
      } else {

        intersection() {
          cuboid(neck_dimensions, rounding = lockpin_fillet, edges = [BOTTOM + LEFT, BOTTOM + RIGHT]);
          cuboid(neck_dimensions, chamfer = chamfer_enabled ? lockpin_chamfer : 0, edges = [FRONT, BACK], except = TOP);
        }
      }
  }

  if (has_tail_neck) {
    translate([0, 0, neck_z])

      intersection() {
        cuboid(neck_dimensions, rounding = lockpin_fillet, edges = [TOP + LEFT, TOP + RIGHT]);
        cuboid(neck_dimensions, chamfer = chamfer_enabled ? lockpin_chamfer : 0, edges = [FRONT, BACK], except = BOTTOM);
      }
  }
}
module end_parts(grip_type = LP_GRIP_STANDARD, neck_extension = LP_NECK_EXT_NONE, chamfer_enabled = true) {
  has_neck_ext = neck_extension == LP_NECK_EXT_NECK || neck_extension == LP_NECK_EXT_BOTH;
  has_tail_neck = neck_extension == LP_NECK_EXT_TAIL || neck_extension == LP_NECK_EXT_BOTH;
  end_part_half(true, has_tail_neck, chamfer_enabled);
  mirror([0, 0, 1]) end_part_half(grip_type == LP_GRIP_NO_GRIP && neck_extension == LP_NECK_EXT_NONE, has_neck_ext, chamfer_enabled);
}
module end_part_half(front = false, has_neck = false, chamfer_enabled = true) {

  lockpin_fillet_front = lockpin_width_outer / 3;
  lockpin_endpart_dimension = [lockpin_width_outer, lockpin_height, lockpin_endpart_length];

  translate([0, 0, lockpin_prismoid_length + lockpin_endpart_length / 2 - TOLERANCE / 2])

    intersection() {
      cuboid(lockpin_endpart_dimension, rounding = front && !has_neck ? lockpin_fillet_front : 0, edges = [TOP + LEFT, TOP + RIGHT]);
      cuboid(lockpin_endpart_dimension, chamfer = chamfer_enabled ? lockpin_chamfer : 0, edges = [FRONT, BACK], except = has_neck ? [BOTTOM, TOP] : BOTTOM);
    }
}
module tension_shape(chamfer_enabled = true) {
  tension_shape_half(chamfer_enabled);
  mirror([0, 0, 1]) tension_shape_half(chamfer_enabled);
}
module tension_shape_half(chamfer_enabled = true) {
  lockpin_inner_dimension = [lockpin_width_inner, lockpin_height];
  lockpin_outer_dimension = [lockpin_width_outer, lockpin_height];
  lockpin_fillet_sides = BASE_UNIT;

  prismoid(lockpin_inner_dimension, lockpin_outer_dimension, height = lockpin_prismoid_length, chamfer = (chamfer_enabled ? lockpin_chamfer : 0));
}
module tension_hole(tension_hole_strength_multiplier = HR_CORE_LOCKPIN_TENSION_HOLE_STRENGTH_REGULAR) {
  tension_hole_half(tension_hole_strength_multiplier);
  mirror([0, 0, 1]) tension_hole_half(tension_hole_strength_multiplier);
}
module tension_hole_half(tension_hole_strength_multiplier = HR_CORE_LOCKPIN_TENSION_HOLE_STRENGTH_REGULAR) {
  lockpin_tension_angle = 86.5;
  lockpin_tension_hole_width_inner = PRINTING_LAYER_WIDTH * tension_hole_strength_multiplier;
  lockpin_tension_hole_height = BASE_UNIT / 2;
  lockpin_tension_hole_inner_dimension = [lockpin_tension_hole_width_inner, lockpin_height + HR_EPSILON];
  prismoid(size1 = lockpin_tension_hole_inner_dimension, height = lockpin_tension_hole_height, xang = lockpin_tension_angle, yang = 90);
}

lockpin(grip_type = grip_type, neck_extension = neck_extension, strength = tension_hole_strength_multiplier, chamfer_enabled = chamfer_enabled, debug_colors = debug_colors);

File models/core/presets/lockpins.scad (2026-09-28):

// HomeRacker - Lock Pin Release Variants
//
// This is an opinionated collection of useful lock pin variants for
// export and release. Creates a grid pattern of lock pins for efficient printing.

include <../main.scad>

/* [General] */
grid = 5;  // Total number of lock pins to create

// Type of grip for the lock pin
grip_type = 0;  // [0:Standard, 1:Extended, 2:No Grip]

// Neck extension mode
neck_extension = 0;  // [0:None, 1:Neck Side, 2:Both Sides]

/* [Hidden] */
$fn = 100;

module lockpins_grid(grid = 10, grip_type = LP_GRIP_STANDARD, neck_extension = LP_NECK_EXT_NONE) {
  ext = neck_extension >= LP_NECK_EXT_NECK ? LP_NECK_EXTENSION_UNIT : 0;
  front_ext = neck_extension >= LP_NECK_EXT_BOTH ? LP_NECK_EXTENSION_UNIT : 0;
  spacing = [grip_width + PRINTING_LAYER_WIDTH * 2, BASE_UNIT + BASE_STRENGTH * 2 + TOLERANCE + PRINTING_LAYER_WIDTH * 2 + grip_base_length + ext + front_ext];
  grid_copies(spacing, n = grid) {
    color(HR_YELLOW)
      lockpin(grip_type = grip_type, neck_extension = neck_extension);
  }
}

lockpins_grid(grid = grid, grip_type = grip_type, neck_extension = neck_extension);

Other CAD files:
models/core/parts/lockpin.scad
cmd/scadfmt/tests/canary/canary.expected.scad
cmd/scadfmt/tests/canary/canary.scad
models/bracket/parts/bracket.scad
models/bracket/test/bracket.scad
models/core/flattened/connector.scad
models/core/flattened/support.scad
models/core/parts/connector.scad
models/core/parts/support.scad
models/core/presets/connectors.scad
models/core/presets/supports.scad
models/core/test/connector.scad
models/core/test/lockpin.scad
models/core/test/support.scad
models/crates/parts/crates.scad
models/elgato_prompter_adapter/insta360_link_2c_pro/flattened/adapter.scad
models/elgato_prompter_adapter/insta360_link_2c_pro/makerworld/adapter.scad
models/foot/parts/foot.scad
models/foot/test/foot.scad
models/gridfinity/flattened/baseplate.scad
models/gridfinity/flattened/binbase.scad
models/gridfinity/parts/baseplate.scad
models/gridfinity/parts/binbase.scad
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

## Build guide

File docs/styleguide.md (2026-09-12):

# 🎨 Style Guide

## 📌 What

The visual rules for everything HomeRacker publishes: the website, the configurator, MakerWorld descriptions and renders. Colours come from the models themselves; type and layout follow from the product.

## 🎨 Colours

The palette is defined once, in [`models/core/lib/constants.scad`](../models/core/lib/constants.scad), and every part render uses it. The site and the configurator read the same values.

| Token | Hex | Use |
|---|---|---|
| `HR_YELLOW` | `#f7b600` | Supports, the brand accent, primary buttons, highlights |
| `HR_BLUE` | `#0056b3` | Connector cores |
| `HR_RED` | `#c41e3a` | Feet, warnings |
| `HR_GREEN` | `#2d7a2e` | Connector arm interiors in renders |
| `HR_CHARCOAL` | `#333333` | Lock pins, print interfaces |
| `HR_WHITE` | `#f0f0f0` | Pull-through connectors |

Web surfaces add a neutral dark scale around the palette:

| Token | Hex | Use |
|---|---|---|
| `--bg` | `#0b0c10` | Page background |
| `--panel` | `#15171c` | Cards, side panes |
| `--panel-2` | `#1c1f26` | Raised elements, inputs on cards |
| `--line` | `#2a2e38` | Borders, rules |
| `--text` | `#e8e6df` | Body text |
| `--muted` | `#a3a49f` | Secondary text, labels |
| `--link` | `#4d95ff` | Links (HR_BLUE lifted for contrast on dark) |
| `--danger` | `#ff4d6a` | Validation errors; parts that do not fit the print bed, in lists and in 3D (HR_RED lifted for contrast on dark) |
| panel plate | `#d9d6cc` | Panels in 3D previews: a matte bone white, distinct from yellow supports and white pull-through cores |

Rules: yellow is the only loud colour on a page. Blue is for links and connector cores, red only for errors and feet. Body text stays at 4.5:1 contrast or better against its background.

## 🔤 Type

| Role | Face | Weight | Notes |
|---|---|---|---|
| Headings, display | **Orbitron** | Black (900) | Uppercase, tight leading. Keep it for titles, section headings and big numbers |
| Everything else | **Source Code Pro** | 400 body, 500/600 labels and buttons | Body text, navigation, labels, tables, code |

Both are open fonts (SIL OFL) and are self-hosted through `@fontsource` packages; no external font requests.

## 📐 Structure

- The 15 mm base unit is a visible motif: pin-hole background lattice, support-beam dividers with a connector core at each end.
- Corners are square. Chamfered buttons (one clipped corner pair) echo the printed parts.
- Diagrams and previews use the part colours above so a support is yellow everywhere it appears.

## 📚 References

- [`models/core/lib/constants.scad`](../models/core/lib/constants.scad): colour source of truth
- [`site/src/styles/global.css`](../site/src/styles/global.css): web tokens and type scale
- [`configurator/src/configurator.css`](../configurator/src/configurator.css): the configurator reads the same tokens
- [homeracker.org](https://homeracker.org): the site, [MakerWorld](https://makerworld.com/@kellerlab), model listings

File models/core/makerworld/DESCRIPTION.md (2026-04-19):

---
makerworld_url: https://makerworld.com/en/models/1317298-homeracker-core
extracted: 2026-04-13
---

<h2 style="text-align: center">HomeRacker - Core</h2>

<p style="text-align: center"><a href="https://homeracker.org/">HomeRacker Logo</a></p>

<p style="text-align: center"><a href="https://homeracker.org/">https://homeracker.org/</a></p>

HomeRacker Core Video (https://www.youtube.com/watch?v=g8k6X_axYug)

<p style="text-align: center"><strong>Boost Me (for free)</strong></p>

<p style="text-align: center">Help me overengineer more stuff if you like this one!</p>

A fully modular universal rack building system for virtually any "racking needs"
(Server Rack, bookshelf, shoe rack, you name it).

HomeRacker grows with your needs — start with a small Pi-Rack and scale up to 10" or even 19" racks. Multiple racks can be assembled together. There are no limits to how big you want to build.

Cyberpunk 10" Rack Showcase

Check out this [Cyberpunk-themed 10" Rack](https://makerworld.com/en/models/1353730-modular-10-server-rack#profileId-1396904) — a perfect showcase of what HomeRacker can do.

## 📦 What's in the Box?

This model contains the **core parts** of HomeRacker:

- **Supports** — from x2 to x17 in the print profile, customizable up to x100
- **Connectors** — all permutations, sane defaults in the print profile
- **Lock Pins** — standard, extended grip, and neck extension variants
- **Foot Inserts** — snap into any connector arm for stability and grip (also available as a [standalone model](https://makerworld.com/en/models/2655123-foot-insert-for-homeracker))
- **Diagonal Supports** — stabilizers for load bearing or large builds (separate 3mf folder)

All parts are fully customizable in the Parametric Model Maker (v1.8.0+).

### 🙅‍♂️ Do NOT autorotate the parts! 🙅‍♂️

No part needs printing-supports when exported from the Model Maker (provided you didn't deactivate `optimal_orientation`). Print single-holed supports with the hole aligned vertically for best locking experience.

## Diagonal Supports

Stabilizers for load bearing or large builds. 5 permutations to cover many directions, in almost any printable size. Available as 3mf files in the "Diagonal Supports" folder.

Diagonal Supports

## 🔌 Projects

### [The Official HomeRacker Collection](https://makerworld.com/collections/5970240)

<a href="https://makerworld.com/en/collections/5970240-homeracker-official-catalog">Official HomeRacker Collection</a>

Highlights:

<a href="https://makerworld.com/en/models/1895418-modular-gridfinity-drawers#profileId-2030731">Modular Gridfinity Drawers</a>

<a href="https://makerworld.com/en/models/1545372-dry-filament-shelf#profileId-1622562">Dry Filament Shelf</a>

## ⚙️ Technical Specs

Based on the open-source HomeRacker specification: [https://homeracker.org/](https://homeracker.org/)

Raise issues or contribute on [GitHub](https://github.com/kellerlabs/homeracker/issues/new).

## 🚀💰 Free Use and Commercial Freedom

The Core Model is, and will always remain, free for you to use! ✅

It's licensed under **Creative Commons Attribution-ShareAlike 4.0 International (CC BY-SA 4.0)**: https://creativecommons.org/licenses/by-sa/4.0/ — which allows commercial use. You can create extensions and derivatives, and even charge money for them! 🤑 Please give proper attribution to **KellerLab** and include a reference to **CC BY-SA 4.0**; linking my MakerWorld profile is a great way to do that: https://makerworld.com/en/@kellerlab 🙏

#### ⚠️ Important Boundary

This commercial freedom applies only to the Core Model described here. Other KellerLab extensions, add-ons, or derivative models that I publish are separate releases and may be offered under different licenses or terms.

## 🏘️ Community Driven

Anyone can create and share HomeRacker extensions under the open spec and CC BY-SA 4.0 terms!

- 🧑‍💻 **Designers** — Go ahead and build! I'd love to link your creations in the catalog.
- 💭 **Idea-Generators** — Pitch your idea to me with as much detail as possible!

<p style="text-align: center">Check out the <a href="https://makerworld.com/en/collections/6173784-homeracker-community-catalog">Community Catalog</a></p>

<p style="text-align: center">Pitch ideas or vote for them <a href="https://github.com/kellerlabs/homeracker/discussions">here on GitHub</a>!</p>

<p style="text-align: center">Join the <a href="https://discord.com/invite/FNG2RsAP53">KellerLab Discord Server</a></p>

## ☕️ Support

If you appreciate this model and wanna buy me coffee, you can do so here: [https://ko-fi.com/kellervater](https://ko-fi.com/kellervater)

Or simply scan this QR-Code:

<p style="text-align: center">Ko-fi QR Code</p>

## 📜 Changelog

- 🦶 v2.0.0 — Standalone foot insert added to Core (was previously part of the connector)
- 🫳 v1.8.0 — Lock Pins now have extended grip versions and neck extension options
- 🌐 v1.1.0 — All core parts now customizable in OpenSCAD (connectors, supports, lock pins)

Full changelog: [CHANGELOG.md](https://github.com/kellerlabs/homeracker/blob/main/CHANGELOG.md)

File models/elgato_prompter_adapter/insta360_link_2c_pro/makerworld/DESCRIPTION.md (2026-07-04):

---
makerworld_url: TBD
created: 2026-07-04
---

<p style="text-align: center">Adapt your Insta360 Link 2C Pro webcam to fit seamlessly into the Elgato Prompter!</p>
<p style="text-align: center">Elgato Prompter Adapter for Insta360 Link 2C Pro</p>

## 📦 What's in the Box

*   **Adapter Plate**: The main adapter that clips onto the Elgato Prompter and securely holds the Insta360 Link 2C Pro.
*   **Demo Piece**: A small, material-saving test piece to verify printer tolerances before printing the full plate.

Adapter ISO View

## 🛠️ Assembly & Customization Guide

The assembly is straightforward and requires no extra hardware.

> 💡 **Material Recommendation**: While PLA works fine, I highly recommend using a hard TPU like **TPU68D** (such as Bambu Lab TPU for AMS in black). The fit is just as tight, but the rubber-like nature makes it much less "scratchy" when inserting the camera, and it provides noticeably better grip.

### 1. Print the Demo Piece (Optional but Recommended)
The provided print profile includes both the full adapter plate and the small demo piece on separate plates. I highly recommend printing just the demo piece first. This helps you verify that your printer's tolerances allow the camera to fit snugly without being too tight or too loose.

Demo Piece

If the fit isn't perfect, you can easily adjust it using the **MakerWorld Parametric Model Maker (PMM)**. Simply click "Customize" on the model page and adjust the `clearance` variable (default is `0.2`mm). You can also set `print_demo` to `true` to generate and download just the test piece before committing to the full print.

### 2. Insert the Camera
Aim the camera into the adapter hole from the front side.

Aiming camera into hole

Firmly press the camera into the hole.

Pressing camera into hole

Ensure the camera is fully inserted and flush with the adapter.

Camera fully inserted

Here is how it should look from the back once the camera is properly seated.

Back view with inserted camera

### 3. Attach to the Prompter
Hook the Bottom of the adapter into the back bracket of the Elgato Prompter.

Hook in adapter to prompter

Swing the adapter up to close the hole.

Closing the hole

Secure the adapter using the original Elgato thumbscrews on the left and right.

Screw in left thumbscrew

### You're Done!
The camera is now perfectly aligned and ready for use.

Completed back view

Prompter with text displaying

## 📜 Changelog

- **04.07.2026** - Initial release! 🎉

## 👨‍💻 Source Code

I am a strong believer in open source. You can find the raw OpenSCAD source files for this adapter on [GitHub in the HomeRacker repository](https://github.com/kellerlabs/homeracker/tree/main/models/elgato_prompter_adapter/insta360_link_2c_pro). Feel free to fork, remix, and contribute! (MIT license)

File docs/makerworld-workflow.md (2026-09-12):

# 🌐 MakerWorld Description Workflow

## 📌 What

How to manage MakerWorld model descriptions as git-tracked `DESCRIPTION.md` files and publish them to MakerWorld.

## 🤔 Why

- ✅ Keep MakerWorld descriptions versioned, reviewable, and easy to update alongside model changes
- 🖼️ Store images in the shared assets repo so source repos stay lean and links remain stable
- 🔁 Use one Markdown source that can be edited in Git and republished to MakerWorld as HTML

## 🔧 How

### Extract (MakerWorld → Git)

Use the `makerworld-description` skill to extract a description from a MakerWorld model page:

1. Provide the MakerWorld model URL
2. The skill scrapes the page, downloads images to the **assets repo**, and creates `DESCRIPTION.md`
3. Commit the `DESCRIPTION.md` to the source repo and images to `kellerlabs/assets`

### Publish (Git → MakerWorld)

```bash
pip install -r requirements.txt
python cmd/export/md-to-mw.py models/<name>/makerworld/DESCRIPTION.md
```

This generates `DESCRIPTION.html` (gitignored). Open it in a browser, `Ctrl+A`, `Ctrl+C`, paste into MakerWorld's description editor.

### Edit

1. Edit `DESCRIPTION.md` directly in the source repo
2. Re-run `md-to-mw.py` to regenerate HTML
3. Re-paste into MakerWorld

### Update (After Model Changes)

Use the `makerworld-description` skill's **Update flow** to refresh a description after a release:

1. Invoke the skill with a request like "update core description with latest changes"
2. The skill reads `CHANGELOG.md`, filters model-relevant changes, and proposes edits
3. Review the proposed changelog entries and feature bullet updates
4. The skill checks the assets repo for new images and suggests placements
5. Frontmatter gets an `updated: YYYY-MM-DD` field
6. Publish with `md-to-mw.py` (see above)

## 📁 Image & Layout Formatting

> ⚠️ **Cross-repo workflow**: This skill requires both the source repo and [`kellerlabs/assets`](https://github.com/kellerlabs/assets). Maintainers push images directly to `assets/main`. Outside collaborators must open a PR on the assets repo for image changes.

Images are stored in **[kellerlabs/assets](https://github.com/kellerlabs/assets)**, not in the source repos.

```
https://raw.githubusercontent.com/kellerlabs/assets/main/<repo>/models/<name>/makerworld/images/<file>
```

- Use `<img>` tags with `width` (no `height`) so images scale proportionally
- Use `<h2 style="text-align: center">` and `<p style="text-align: center">` for centered elements
- These HTML blocks render correctly on GitHub and pass through to `md-to-mw.py`

`md-to-mw.py` passes absolute URLs through unchanged. Base64 embedding only applies to local relative paths.

### Create (New Description)

Use the `makerworld-description` agent to create a new `DESCRIPTION.md` from scratch:

1. Invoke the agent with a model name and target repo, e.g. `foot homeracker-exclusive`
2. The agent interviews you for model details, verifies images in the assets repo, creates `DESCRIPTION.md`, enhances `CUSTOMIZATION.md` with images, and opens a PR
3. Optionally publish with `md-to-mw.py` (see above)

## 📚 References

- [image-hosting-assets-repo](decisions/image-hosting-assets-repo.md): why images live in a separate repo
- `.claude/agents/makerworld-description.md`: agent for creating new descriptions
- `.claude/skills/makerworld-description/SKILL.md`: skill for extracting existing descriptions
- `cmd/export/md-to-mw.py`: conversion script

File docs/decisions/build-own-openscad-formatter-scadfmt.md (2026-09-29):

# 📋 Build Our Own OpenSCAD Formatter, scadfmt

## 📌 Status

**Accepted**: 2026-09-27

## 🤔 Context

- Community contributions need one common code style ([#177](https://github.com/kellerlabs/homeracker/issues/177)). Today indentation mixes 2 and 4 spaces and operator spacing varies per file.
- The repo pins OpenSCAD nightly, so the formatter must keep up with new syntax, such as the bitwise operators `& | ~ << >>`.
- Existing tools, run against all 74 `.scad` files:

| Tool | Verdict | Reason |
|---|---|---|
| [scadformat](https://github.com/hugheaves/scadformat) (Go, ANTLR) | ❌ Rejected | Rewrites `~5` to `5` with exit code 0; joins hand-wrapped calls into lines up to 479 chars; no config, no check mode; single maintainer, no tagged versions |
| [scad-format](https://pypi.org/project/scad-format/) (clang-format style) | ❌ Rejected | Rewrites `include <BOSL2/std.scad>` to `include < BOSL2 / std . scad >` |
| [openscad-format](https://github.com/Maxattax97/openscad-format) | ❌ Rejected | Unmaintained since 2022, clang-format based |
| openscad-LSP formatter (topiary) | ❌ Rejected | Editor only, no CLI |
| [sca2d](https://gitlab.com/bath_open_instrumentation_group/sca2d) | ❌ Rejected | Linter, not a formatter; cannot resolve BOSL2 or `homeracker/` includes |

## 🔧 Decision

`scadfmt`, a stdlib-only Python package in `cmd/scadfmt/`, separate from scadm.

- **Token based, not a full parser.** It needs to know OpenSCAD's tokens, not its grammar. New syntax made of known tokens needs no change; a new operator is one table entry.
- **Never changes meaning.** The token sequence without whitespace must match before and after, otherwise it aborts. An unknown character is an error, never dropped.
- **Never joins lines.** It only adds breaks: after `{`, around `}` (keeping `} else`), after `;` outside parentheses, after the import block and around definitions.
- **Rules:** 2-space indent, one level per line that opens brackets; one statement per line and block contents on their own lines; imports as one block followed by one blank line; exactly one blank line around each `module` and `function` definition; a continued module call nests one level per line, a continued expression stays one level in; spaces around every binary operator and every `=` (`cube(size = 10)`); space after commas; tight unary operators, modifiers and range colons; consecutive trailing comments aligned to one column (a lone one gets 2 spaces); max 2 blank lines at top level and 1 inside blocks; the file's own line endings and one final newline. Full list in the [scadfmt README](../../cmd/scadfmt/README.md#-rules).
- **CLI conventions:** `format`, `--check`, `--diff`, stdin, exit codes 0/1/2, `// fmt: off` / `// fmt: on`.
- **Linting later** (`scadfmt lint`, naming rules) builds on BelfrySCAD's [openscad-parser](https://github.com/belfryscad/openscad_parser) (by the BOSL2 author, already parses the nightly's bitwise operators). The formatter never depends on it.
- **Tested like scadm:** a branch coverage gate and per-PR mutation testing, see [gate-coverage-and-surviving-mutants-in-changed-functions](gate-coverage-and-surviving-mutants-in-changed-functions.md).
- **Separate from scadm:** scadm manages OpenSCAD and libraries, scadfmt manages style. Released to PyPI on its own (`scadfmt-v*`). `scadfmt vscode` registers it as the VS Code formatter via Custom Local Formatters.

### Alternatives Considered

| Approach | Verdict | Reason |
|---|---|---|
| Own full parser for format and lint | ❌ Rejected | Every grammar change breaks formatting; comment handling on a tree is the hardest part of a formatter |
| tree-sitter + topiary | ❌ Rejected | Depends on `tree-sitter-openscad` (last release 2024), Rust binary |
| Token scanner for lint too | ❌ Rejected | Scope rules turn heuristics into an ad hoc parser |
| Subcommand of scadm | ❌ Rejected | Mixes concerns, couples release cycles, drags an installer into other projects |

## 📊 Consequences

- **Positive**: OpenSCAD drift costs little: tokens change rarely, and the formatter fails loudly instead of corrupting code.
- **Positive**: usable outside HomeRacker via PyPI and a local pre-commit hook.
- **Negative**: we maintain the formatter ourselves; kept in check by the canary and a planned weekly nightly check ([#177](https://github.com/kellerlabs/homeracker/issues/177)).
- **Negative**: `scadfmt vscode` repeats about 60 lines of `scadm vscode` settings handling.
- **Revisable**: no line length limit for now; a lint rule can add one later.
- **Negative**: the first repo-wide format run (a follow-up PR) touches most `.scad` files; its commit goes into `.git-blame-ignore-revs`.

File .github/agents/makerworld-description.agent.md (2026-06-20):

---
description: "Create or update a MakerWorld model description. Use when: user wants to create a DESCRIPTION.md for a model, enhance a CUSTOMIZATION.md with images, prepare a model for MakerWorld publishing."
tools: [read, edit, search, execute, agent, todo, questions, fetch]
argument-hint: "Model name and target repo (e.g. foot homeracker-exclusive, core homeracker)"
---

You are the **MakerWorld Description Agent** for HomeRacker projects. Your job is to create polished MakerWorld model descriptions (`DESCRIPTION.md`), enhance customization guides with images, and prepare models for MakerWorld publishing.

## Cross-Repo Architecture

This agent works across multiple repositories:
- **homeracker** or **homeracker-exclusive** — where `DESCRIPTION.md` and `CUSTOMIZATION.md` live
- **kellerlabs/assets** — where MakerWorld images are stored (pushed directly to `main`)
- Common images shared across all models live in `assets/common/makerworld/images/`
- Model-specific images live in `assets/<repo>/models/<name>/makerworld/images/`

## Reference Files

Before starting, read these files for conventions:
- `.github/skills/makerworld-description/SKILL.md` — formatting rules, image conventions, publish flow
- Existing `DESCRIPTION.md` files in `models/*/makerworld/` for structural patterns (especially frontpanel and core)
- The model's `CUSTOMIZATION.md` for printing instructions and parameters
- The model's `README.md` for a brief summary

## Common Description Template

All HomeRacker MakerWorld descriptions follow this structure. Sections marked with ⭐ are **mandatory** for every model.

### ⭐ 1. Header Block (centered HTML)

```html
<p style="text-align: center">Catchy tagline</p>

<h2 style="text-align: center">Model Name</h2>

<p style="text-align: center"><a href="https://homeracker.org/"><img src="https://raw.githubusercontent.com/kellerlabs/assets/main/common/makerworld/images/homeracker_logo_banner.webp" alt="HomeRacker Logo" width="300"></a></p>

<p style="text-align: center">for <a href="https://makerworld.com/en/models/1317298-homeracker-modular-rack-building-system#profileId-1352703">HomeRacker</a></p>
```

The tagline should be a short, catchy phrase that gives the model personality (e.g. "A Truly" / "Universal Rackmount", "A one-size-fits-all" / "Foot Insert"). Ask the user for input on the tagline during the interview.

### 2. Video Embed (if available)

```markdown
[![Watch this Video](https://img.youtube.com/vi/<VIDEO_ID>/maxresdefault.jpg)](https://www.youtube.com/watch?v=<VIDEO_ID>)
```

### ⭐ 3. Model Introduction

One paragraph explaining what the model does, followed by a hero image, then 2-4 bullet points with emojis highlighting key features.

### 4. Model-Specific Sections

These vary per model (e.g. "How It Works", "Mounting Options", "What You Get", "In Action"). Use images from the assets repo. Rules:
- **Title images are off-limits** — the user selects these for MakerWorld's title carousel only
- Use `<img>` tags with `width="800"` only when the image's native width is at least 800px; otherwise use the native width for smaller images (for example, logo `300`, QR `328`)
- Describe what each image actually shows — don't make assumptions about content you can't verify
- Link to the customization guide for printing instructions instead of duplicating them

### ⭐ 5. "What is HomeRacker?" Section (non-core models only)

```markdown
## 🏡 What is HomeRacker?

[![HomeRacker Core Video](https://img.youtube.com/vi/g8k6X_axYug/maxresdefault.jpg)](https://www.youtube.com/watch?v=g8k6X_axYug)

HomeRacker is a universal modular rack building system. It's based on an open specification. Find out more here:

[HomeRacker - Core on MakerWorld](https://makerworld.com/en/models/1317298-homeracker-modular-rack-building-system#profileId-1352703)

or visit [https://homeracker.org/](https://homeracker.org/)

### [The Official HomeRacker Collection](https://makerworld.com/collections/5970240)

<a href="https://makerworld.com/en/collections/5970240-homeracker-official-catalog"><img src="https://raw.githubusercontent.com/kellerlabs/assets/main/common/makerworld/images/collection_banner.webp" alt="HomeRacker Official Collection" width="800"></a>
```

### ⭐ 6. Community Driven Section

```markdown
## 🤝 Community Driven

I created HomeRacker - Core as an open specification. Anyone can create and share their own extensions and models based on it without licensing restrictions — all I ask for is attribution!

#### 🧑‍💻 For Designers

Have an idea and the skills? Go ahead — I'd be happy to link and feature your creations in the catalog.

#### 💭 For Idea-Generators

Not familiar with CAD? Pitch your idea to me with as much detail as possible!

Check out the [Community Catalog](https://makerworld.com/en/collections/6173784-homeracker-community-catalog)

Pitch ideas or vote for them [here on GitHub](https://github.com/kellervater/homeracker/discussions)!

Join the KellerLab Discord Server: [Discord Invite](https://discord.gg/FNG2RsAP53)
```

### ⭐ 7. Support Section

```markdown
## ☕ Support

If you appreciate this model and wanna buy me coffee, you can do so here: [https://ko-fi.com/kellervater](https://ko-fi.com/kellervater)

Or simply scan this QR-Code:

<img src="https://raw.githubusercontent.com/kellerlabs/assets/main/common/makerworld/images/kofi_qr_code.webp" alt="Ko-fi QR Code" width="328">
```

### ⭐ 8. Changelog Section

```markdown
## 🗓️ Changelog

- 🆕 Description of latest feature or change
- 🐛 Description of a fix (max 3 items in prose, not conventional commit format)
```

**For homeracker-exclusive models** (private repo): add a note linking to the Core changelog since the exclusive repo isn't public:

```markdown
This model is part of the [MakerWorld-exclusive HomeRacker collection](https://makerworld.com/en/collections/5970240-homeracker-official-catalog). It builds on the open-source [HomeRacker - Core](https://github.com/kellerlabs/homeracker/tree/main/models) system — the base building blocks changelog can be found in the [Core CHANGELOG](https://github.com/kellerlabs/homeracker/blob/main/CHANGELOG.md).
```

**For homeracker models** (public repo): link directly to the full changelog:

```markdown
Full changelog: [CHANGELOG.md](https://github.com/kellerlabs/homeracker/blob/main/CHANGELOG.md)
```

### YAML Frontmatter

Every `DESCRIPTION.md` starts with YAML frontmatter. Use only the field that applies — `created` for new descriptions, `extracted` for descriptions pulled from MakerWorld (never both):

```yaml
---
makerworld_url: <URL or TBD>
created: YYYY-MM-DD
---
```

## Workflow

Work through these phases **in order**. Mark each phase in your todo list.

---

### Phase 1 — Interview

Ask the user these questions (use the questions tool):

1. **Model name** — Which model? (e.g. `foot`, `frontpanel`)
2. **Target repo** — `homeracker` or `homeracker-exclusive`?
3. **MakerWorld URL** — Already published? If yes, the URL. If no, use `TBD`.
4. **Tagline** — A catchy short phrase for above the title (e.g. "A one-size-fits-all" / "Foot Insert")
5. **Title images** — Which images should be excluded from the description (title-only for MakerWorld)?
6. **Video** — Is there a YouTube video for this model? If yes, the URL.
7. **Cross-reference** — Should any other model descriptions be updated to reference this one?

---

### Phase 2 — Verify Assets

1. List images in `assets/<repo>/models/<name>/makerworld/images/`
2. View each image to understand its content
3. Present a summary to the user: image name → what it shows
4. Confirm which images to use in description vs customization guide
5. If images are missing, ask the user to add them to the assets repo first

---

### Phase 3 — Create DESCRIPTION.md

1. Create `models/<name>/makerworld/DESCRIPTION.md` in the target repo
2. Follow the Common Description Template above
3. Use the model's README, CUSTOMIZATION.md, and .scad source for context
4. Reference images via `https://raw.githubusercontent.com/kellerlabs/assets/main/<repo>/models/<name>/makerworld/images/<file>`
5. Common images via `https://raw.githubusercontent.com/kellerlabs/assets/main/common/makerworld/images/<file>`
6. Apply standard `width="800"` for description images, `width="300"` for logo, `width="328"` for ko-fi QR

---

### Phase 4 — Enhance CUSTOMIZATION.md

1. Read the existing `CUSTOMIZATION.md`
2. Add relevant images where they improve understanding (e.g. printed parts photo near printing instructions, installation photo near usage section)
3. Do NOT duplicate content between DESCRIPTION.md and CUSTOMIZATION.md

---

### Phase 5 — Review & Commit

1. Read back both files and verify:
   - All mandatory template sections present
   - Image URLs are valid (correct repo, correct path)
   - No "wider base plate" or similar inaccurate claims — describe what you see in images
   - Changelog follows the right pattern for the target repo
2. Run pre-commit hooks
3. Commit with: `feat(<name>): add makerworld description`
4. Push and create PR using the **GitHub MCP Server**

---

### Phase 6 — Publish (Optional)

If the user wants to publish immediately:

1. Direct them to run: `python cmd/export/md-to-mw.py models/<name>/makerworld/DESCRIPTION.md`
2. This generates `DESCRIPTION.html` (gitignored)
3. Instruct: open HTML in browser → `Ctrl+A` → `Ctrl+C` → paste into MakerWorld description editor

---

## Constraints

- Do NOT invent image content — always view images before describing them
- Do NOT duplicate printing tips in DESCRIPTION.md if they exist in CUSTOMIZATION.md — link to the guide instead
- Do NOT include internal specification details (geometry dimensions, section names) in the description — those belong in CUSTOMIZATION.md or tech docs
- Do NOT use `[Image: Image]` placeholders — every image must have a real URL
- Title images designated by the user are OFF-LIMITS in the description
- Follow the `.github/skills/makerworld-description/SKILL.md` for all formatting conventions
- Use emojis in documentation per project conventions

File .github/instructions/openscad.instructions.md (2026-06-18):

---
applyTo: "**/*.scad"
---

# OpenSCAD Guidelines

## BOSL2 Library

- Use [BOSL2](https://github.com/BelfrySCAD/BOSL2/wiki) for complex geometry operations (prefer attach/align over OpenSCAD's translate/rotate).
- Consult the BOSL2 wiki for available modules before writing custom geometry.

## Composing Geometry (attach/align vs union/diff)

- **Position with anchors, not offsets.** Prefer `attach`/`align`/`position` + `left`/`right`/`fwd`/`back` over raw `translate`/`rotate` with hand-computed centre math. `union()` is for merging separate solids, never for positioning.
- **`diff()` is tag-based.** Kept (untagged) geometry and `remove`-tagged cutters coexist in one `diff()`; cutters only subtract where they overlap. A part welded on after the bores belongs *inside* the same `diff()` as an untagged child — do **not** wrap it in `union()` to "shield" it.
- **Isolate a child's own `diff()`/`edge_mask` with `tag_scope()`.** A nested chamfer (edge_mask applies a `remove` tag) leaks into an enclosing `diff()` and gets cancelled. Wrap the inner part in `tag_scope()` at the call site to contain its tags.
- **Edge breaks in one pass.** Chamfer/fillet an assembly's outer edge with `edge_mask` on the bounding-box edges, not per-member — per-piece chamfers leave nubs at junctions.
- **Keep sub-parts ignorant of the parent.** A reusable part (e.g. a back brace) should take its own size and attach to a face; splitting/clipping belongs in the parent, not duplicated inside the part.

## Naming

- **Use descriptive variable names.** Spell out intent: `usable_width`, `seam_edge`, `row_center` — not `uw`, `se`, `rc`. The only exception is loop counters (`i`, `j`, `k`) and BOSL2/OpenSCAD idioms (`$fn`, `$idx`).
- Local variables in functions/modules carry a leading underscore by convention (`_usable_width`); keep the descriptive name after it.

## Quality Settings

- Set `$fn=100` for production renders.
- Use lower `$fn` values (e.g., 32) during development for faster previews.

## Customizer Parameters

- Group parameters with `/* [Section] */` comment markers.
- Use `/* [Hidden] */` for internal constants that shouldn't appear in the Customizer UI.
- Include sanity checks (assertions) for critical parameters.
- Test parameter ranges for edge cases — especially min/max and boundary values.

## File Organization

- **Parts**: Printable models go in `models/<type>/parts/`.
- **Libraries**: Shared modules/functions go in `models/<type>/lib/` or `models/core/lib/`.
- **Tests**: Test files go in `models/<type>/test/`.
- **Flattened exports**: Auto-generated via `scadm flatten` into `models/<type>/flattened/` — never edit these manually.

## Include Conventions

- Use `include <BOSL2/std.scad>` for BOSL2 (resolved by OpenSCAD library path).
- Use `include <homeracker/...>` for cross-model library includes (resolved by scadm).
- Use relative paths (`include <../lib/foo.scad>`) for same-model includes.

## Catalog Render PNGs

- When adding or modifying a parts file, **regenerate its render PNG** with `scadm export-png`.
- `scadm export-png` always passes `--render`, so catalog images are **full F6 renders**, not OpenCSG previews. Always recreate them this way — preview screenshots show triangulation seams on coplanar/coincident faces that full renders avoid.
- If a full render still shows a diagonal seam on a flat face, the geometry has two coplanar coincident faces. Fix it in the model (e.g. overlap unioned boxes by `HR_EPSILON`) rather than re-rendering.
- PNGs are stored in a `renders/` subfolder next to their source (e.g., `parts/foo.scad` → `parts/renders/foo.png`).
- Update the model's README 📸 Catalog table and the `models/README.md` index accordingly.
- **Dark models** (e.g., `HR_CHARCOAL` primary color): use `--colorscheme Metallic` for better contrast. The default `BeforeDawn` has a dark background that makes charcoal/black models invisible.
- **Repo-wide regeneration** — recreate every default catalog PNG (one per non-`_` `parts/*.scad`):
  ```bash
  find models -path '*/parts/*.scad' -not -name '_*' -exec scadm export-png {} \;
  ```
  Variant PNGs (those built with `-D`/`--output`) are listed per model in that model's `README.md` — re-run those commands too.

## Self-Test Renders

For quick geometry verification during development:

1. Create a temporary preset JSON in `parts/` with `_test_` prefix:
   ```json
   { "parameterSets": { "my_test": { "param": "value" } } }
   ```
2. Prefer `scadm export-png` when available, fall back to direct OpenSCAD:
   ```bash
   # Preferred (when scadm export-png is available):
   scadm export-png models/<type>/parts/<file>.scad -p _test_preset.json -P my_test

   # Fallback (direct OpenSCAD — use openscad.com on Windows, openscad on Linux/macOS):
   bin/openscad/openscad.com models/<type>/parts/<file>.scad \
     -o models/<type>/parts/_test_output.png --render \
     --imgsize=1200,900 --colorscheme BeforeDawn --viewall --autocenter \
     -p models/<type>/parts/_test_preset.json -P my_test
   ```
3. **Render multiple angles** — a single view can miss geometry issues:
   - Default (`--viewall --autocenter`): overall shape
   - Front: `--camera=0,0,0,90,0,0,0`
   - Side: `--camera=0,0,0,90,0,90,0`
   - Close-up of changed area: `--camera=x,y,z,rx,ry,rz,dist`
4. Use `debug_colors=true` and low `$fn` (32) for fast iteration.
5. **Clean up** all `_test_*` files after verification.

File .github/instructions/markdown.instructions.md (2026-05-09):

---
applyTo: "**/*.md"
---

# 📝 Markdown Documentation Guidelines

## Purpose & Scope

These guidelines ensure documentation in HomeRacker stays consistent, discoverable, and actionable.
Every code change that adds, modifies, or removes functionality **must** include a corresponding documentation update.

## ✍️ Writing Style

- Use **emojis** to improve scannability (section headers, admonitions, list bullets where fitting).
- Be **brief** — prefer bullet points over prose. Link to existing docs instead of duplicating content.
- Use **code blocks** with language hints for commands and config snippets.
- Cross-reference from the parent `README.md` when adding new pages so they remain discoverable.

## 📐 Document Structure

If not stated otherwise by the user, every new documentation page must follow this skeleton:

```markdown
# 🏷️ Title

## 📌 What

What component/feature/process this covers and which code paths are affected.

## 🤔 Why

Use-case description, design rationale, and/or architectural context.

## 🔧 How

Step-by-step instructions, commands, and/or examples for a user and/or CI to integrate/execute.

## 📚 References

- Originating issue / PR / discussion
- Related documentation in the repo
- Upstream / vendor documentation
```

> Sections may be omitted only when truly not applicable (e.g., a pure reference page).

## 🏗️ Model README Template

Each model folder (`models/<name>/`) should have a `README.md` following this structure:

```markdown
# 🏷️ Model Name

## 📌 What

Brief description of the model — what it is, what problem it solves.

## 🤔 Why

Design rationale: why this shape, these dimensions, this approach.

## 🔧 How

How to use/customize the model:
- Customizer parameters
- OpenSCAD CLI examples
- Print settings or tips (if applicable)

## 📸 Catalog

Preview images for each part. Generate with `scadm export-png`:

| Part | Preview |
|------|---------|
| Part Name | ![Part Name](parts/renders/part_name.png) |

> For flat models (no `parts/` subfolder), show a single preview in `renders/` next to the `.scad` file.

To generate or refresh previews:

  scadm export-png models/<name>/parts/<part>.scad

## 📚 References

- Related models or libraries
- MakerWorld listing (if published)
```

> - The 📸 Catalog section must list **every** `.scad` file under `parts/` (or the model's main `.scad` for flat models) with a preview PNG.
> - PNGs are generated by `scadm export-png` and stored in a `renders/` subfolder next to their source `.scad` file.
> - When adding or modifying a parts file, **always** generate/refresh its PNG and update the Catalog table.
> - When adding a new model or part, also update the parent `models/README.md` index with a description and preview image.

## 🗂️ File Organization

- **Placement:** READMEs live next to their code — each model folder and `cmd/` subfolder gets its own `README.md`.
- **Naming:** Use lowercase `kebab-case`. Name files after the topic, not the ticket.
- **Restructuring:** When adding docs, check if existing files should be renamed or reorganized to avoid overlap. Keep the directory tree tidy — fewer well-named files beat many scattered ones.
- **Index:** Reference new model folders from `models/README.md`.

## 🔗 Linking Conventions

- Use **relative paths** for repo-internal links.
- For external resources (BOSL2 wiki, MakerWorld), include the full URL.

## 🚫 Anti-Patterns

- Don't create docs that only repeat what the code already says — add *context* the code can't convey.
- Don't leave placeholder sections empty — either fill them or remove the heading.
- Don't duplicate content across files — link to the single source of truth.
- Don't commit PNGs without a corresponding README entry linking them.
- Don't add or modify parts files without generating/refreshing preview PNGs.
- Don't update a model README without checking if the parent `models/README.md` index needs updating too.

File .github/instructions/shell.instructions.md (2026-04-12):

---
applyTo: "**/*.sh,**/*.yml,**/*.yaml"
---

# Shell Guidelines

## Strict Mode

Always start shell scripts and GitHub Actions `run:` blocks with:

```bash
set -euo pipefail
```

- `set -e`: Exit on error.
- `set -u`: Treat unset variables as errors.
- `set -o pipefail`: Fail on first error in a pipeline.

## Error-Safe Iteration

Capture command output before iterating so failures are caught by `set -e`:

```bash
# Bad — pipe masks command failure
gh pr list --json number --jq '.[].number' | while read -r pr; do ...

# Bad — process substitution does not reliably trip set -e
while read -r pr; do ...
done < <(gh pr list --json number --jq '.[].number')

# Good — command failure is caught before iterating
prs="$(gh pr list --json number --jq '.[].number')"
[[ -z "$prs" ]] && exit 0
while read -r pr; do ...
done <<< "$prs"
```

## Best Practices

- Quote variables: `"$var"` not `$var`.
- Use `[[ ]]` for conditionals, not `[ ]`.
- Use `$()` for command substitution, not backticks.
- Use `readonly` for constants.
- Prefer `printf` over `echo` for portable output.
- Use `trap` to clean up temporarily created resources on exit.

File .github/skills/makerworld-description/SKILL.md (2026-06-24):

---
name: makerworld-description
description: >
  Extract MakerWorld model descriptions into git-tracked DESCRIPTION.md files,
  update them after model changes, or convert them back to pasteable HTML for
  MakerWorld's CKEditor.
  USE FOR: extracting descriptions from MakerWorld model pages, creating new
  DESCRIPTION.md files, updating existing descriptions after releases,
  converting markdown descriptions to HTML for MakerWorld publishing.
  DO NOT USE FOR: uploading files to MakerWorld, managing print profiles, or
  OpenSCAD model creation (use @makerworld-model agent instead).
---

# 🌐 MakerWorld Description Skill

## 📌 What

Manages MakerWorld model descriptions as git-tracked `DESCRIPTION.md` files. Supports three flows:

1. **Extract** (MakerWorld → Git): Scrape a MakerWorld model page and produce a clean `DESCRIPTION.md` + images
2. **Update** (Git ↻ Git): Update an existing `DESCRIPTION.md` after model changes — new changelog entries, feature bullets, images
3. **Publish** (Git → MakerWorld): Convert `DESCRIPTION.md` to HTML for pasting into MakerWorld's CKEditor

## 🔧 Extract Flow

Given a MakerWorld model URL, extract the description into a `DESCRIPTION.md` file.

### Steps

1. **Ask the user** which model this is for and where to save it:
   - Target repo (`homeracker` or `homeracker-exclusive`)
   - Model name (e.g. `core`, `foot`, `frontpanel`)
   - Output path defaults to `models/<name>/makerworld/DESCRIPTION.md`

2. **Fetch the page** using `fetch_webpage` with query `"model description details"` and the MakerWorld URL.

3. **Parse the Description section**. The description content is between the `### Description` heading and the `### Comment & Rating` section. Extract only this content. Ignore:
   - Navigation elements, cookie banners, footer
   - Print Profile section, Bill of Materials
   - Comment & Rating section and all comments
   - Remixes, Related Models sections
   - "We use cookies" banner

4. **Clean the markdown**:
   - Convert extracted content to well-formatted markdown
   - Preserve: headings (##, ###), bold/italic, bullet lists, numbered lists, links, images, linked images (`[![alt](img)](url)`), horizontal rules
   - Strip: `[Image: Image]` placeholders, duplicate blank lines, trailing whitespace
   - Keep image URLs as-is initially (they'll be downloaded next)
   - **Use `<img>` tags instead of markdown image syntax** for all images. This allows preserving the `width` attribute. Use `width="800"` for images whose native width is ≥ 800px; for smaller images use their native width. Exceptions: HomeRacker logo (`width="300"`), Ko-fi QR code (`width="328"`). Do NOT set `height` — omitting it lets the browser scale proportionally. Example:
     ```html
     <img src="https://raw.githubusercontent.com/.../logo.webp" alt="Logo" width="800">
     ```
     For linked images, wrap the `<img>` in an `<a>` tag:
     ```html
     <a href="https://target-url"><img src="https://raw.githubusercontent.com/.../image.webp" alt="Alt" width="400"></a>
     ```
   - **Alignment is lost during extraction**: `fetch_webpage` strips `style` attributes, so centered text/headings from MakerWorld come through as plain markdown. This is a known limitation. After extraction, add a note at the bottom of the DESCRIPTION.md:
     ```markdown
     <!-- TODO: Review alignment — fetch_webpage strips style attributes. Compare with MakerWorld page and wrap centered elements in HTML blocks. -->
     ```
     When fixing alignment, use:
     - `<h2 style="text-align: center">Title</h2>` for centered headings
     - `<p style="text-align: center">...</p>` for centered paragraphs, images, or links
     - This renders correctly on GitHub (HTML passthrough) and in `md-to-mw.py`
   - **Detect orphan linked images**: `fetch_webpage` drops `<img>` elements inside `<a>` tags, producing empty links like `[](https://...)`. Collect all such `[](url)` patterns — these are linked images whose `src` was lost. See step 5a for resolution
   - **Be aware of invisible drops**: `fetch_webpage` silently drops `<iframe>` embeds (YouTube videos, etc.) with no trace at all — just blank whitespace. See step 5b for resolution

5. **Download images**:
   - Identify all image URLs in the description (from `makerworld.bblmw.com` CDN or other sources)
   - Skip external reference images (e.g. `encrypted-tbn0.gstatic.com` meme images) — keep those as URLs
   - Download MakerWorld CDN images to the **assets repo**: `assets/<target-repo>/models/<name>/makerworld/images/`
   - Use descriptive filenames based on context (e.g. `diagonal_supports.png`, `showcase_rack.jpg`)
   - After downloading, get pixel dimensions with `python cmd/export/image_dimensions.py <images-dir>` (for reference only — do not use native dimensions for `width`)
   - **Standard image width**: Use `width="800"` for all description images whose native width is ≥ 800px. For smaller images, use their native width. Exceptions: HomeRacker logo (`width="300"`), Ko-fi QR code (`width="328"`). This ensures a uniform look across all model descriptions.
   - **Check for common images**: Some images are shared across all models (e.g. `collection_banner.webp`, `kofi_qr_code.webp`). These live in `assets/common/makerworld/images/`. If a downloaded image already exists there (same content), delete the per-model copy and reference the common one: `https://raw.githubusercontent.com/kellerlabs/assets/main/common/makerworld/images/filename.webp`
   - Reference model-specific images using absolute URLs in `<img>` tags, applying the standard width rule above: use `width="800"` when the native width is ≥ 800px; otherwise use the native width. Example: `<img src="https://raw.githubusercontent.com/kellerlabs/assets/main/<target-repo>/models/<name>/makerworld/images/filename.png" alt="Description" width="800">`

5a. **Resolve orphan linked images** (from step 4):
   - For each `[](url)` pattern found, present the user with a numbered list showing the link target URL
   - Ask the user to open the MakerWorld page in a browser and identify what image is displayed for each link (e.g. a logo, a model thumbnail, a collection banner)
   - The user should provide the image URL (right-click → "Copy image address") or a description
   - Once URLs are obtained: download to `assets/<target-repo>/models/<name>/makerworld/images/`, replace the empty link with a proper linked image using absolute URL: `[![alt text](https://raw.githubusercontent.com/kellerlabs/assets/main/<target-repo>/models/<name>/makerworld/images/filename.png)](url)`
   - If the user cannot provide the URL, insert a TODO comment in the markdown: `<!-- TODO: linked image missing for url -->`

5b. **Resolve missing embeds** (from step 4):
   - Ask the user: "Are there any embedded videos (YouTube, etc.) on the MakerWorld description page that should be included?"
   - If yes, ask for the YouTube video URL(s) and where they appear in the description
   - Insert a markdown-compatible YouTube link in the appropriate location. Use a linked thumbnail image:
     ```markdown
     [![Video Title](https://img.youtube.com/vi/<VIDEO_ID>/maxresdefault.jpg)](https://www.youtube.com/watch?v=<VIDEO_ID>)
     ```
   - `md-to-mw.py` automatically converts these to CKEditor `<figure class="media">` embeds during publish

6. **Add YAML frontmatter** to the top of `DESCRIPTION.md`:
   ```yaml
   ---
   makerworld_url: https://makerworld.com/en/models/<id>-<slug>
   extracted: YYYY-MM-DD
   ---
   ```

7. **Save** the file to the target path.

8. **Verify** by reading back the file and checking:
   - Frontmatter is valid YAML
   - All images have been downloaded
   - No `[Image: Image]` placeholders remain
   - No orphan `[](url)` empty links remain (all resolved or marked with TODO)
   - Embedded videos are accounted for (user confirmed none missing, or added)
   - Markdown renders with proper heading hierarchy

## 📤 Publish Flow

Convert a `DESCRIPTION.md` file to HTML for pasting into MakerWorld.

### Steps

1. Direct the user to run the conversion script:
   ```bash
   python cmd/export/md-to-mw.py models/<name>/makerworld/DESCRIPTION.md
   ```
2. This generates `DESCRIPTION.html` in the same directory (gitignored).
3. Instruct the user to open the HTML file in a browser, select all (`Ctrl+A`), copy (`Ctrl+C`), then paste into MakerWorld's description editor.

## � Update Flow

Update an existing `DESCRIPTION.md` after model changes (new release, new features, removed parts, etc.).

### Steps

1. **Locate the description**: Read the model's `DESCRIPTION.md` and its YAML frontmatter (`extracted` or `created` date, `makerworld_url`).

2. **Detect the source repo**: Infer the repo from the file path (`homeracker` or `homeracker-exclusive`). Present the suggestion and ask for confirmation before proceeding.

3. **Read the changelog**: Read `CHANGELOG.md` in the source repo. Identify releases since the frontmatter date (`extracted` or `created`) or, if no date is usable, since the last changelog entry already mentioned in the description.

4. **Filter model-relevant changes**: From the new releases, extract only changes that affect this model's user-facing description:
   - ✅ New features, new parts, breaking changes, removed parts
   - ❌ CI/infra, docs-only, refactors, dependency bumps

   Present a summary of relevant changes and ask the user to confirm or adjust before editing.

5. **Update the description**:
   - **Changelog section**: Add new entries at the top of the `📜 Changelog` list. Follow the existing emoji + version + dash + description pattern. Drop entries that are no longer the most recent 3–4 (keep the list concise).
   - **Feature sections**: Add, update, or remove bullets in "What's in the Box" or equivalent sections to reflect added/removed parts or features.
   - **Flag rewrites**: If a feature was removed or significantly changed, flag the affected section with a `<!-- TODO: verify — feature X was removed/changed in vN.N.N -->` comment and ask the user for guidance.

6. **Check for new images**: Scan `assets/<repo>/models/<name>/makerworld/images/` for images added since the last update. If new images exist, suggest where to insert them. If none exist but the new features would benefit from visuals, ask the user whether to add any.

7. **Update frontmatter**: Add or update the `updated` field with today's date:
   ```yaml
   ---
   makerworld_url: https://makerworld.com/en/models/<id>-<slug>
   extracted: 2026-04-13
   updated: 2026-04-19
   ---
   ```

8. **Verify**: Read back the file and check:
   - Frontmatter dates are consistent (updated ≥ extracted/created)
   - Changelog entries are in reverse-chronological order
   - No stale feature bullets remain for removed parts
   - Image references still resolve

9. **Publish reminder**: After committing, remind the user to re-run `md-to-mw.py` and re-paste into MakerWorld if the model is already published (check `makerworld_url` ≠ `TBD`).

## �📁 File Convention

```
models/<name>/makerworld/
├── <name>.scad                    # MakerWorld parametric source
├── DESCRIPTION.md                 # Model description (source of truth)
├── DESCRIPTION.html               # Generated HTML (gitignored)
├── renders/                       # Auto-generated render previews
│   ├── <name>_mw_assembly_view.png
│   └── <name>_mw_plate_1.png
```

Images are stored in the **assets repo** (`kellerlabs/assets`):
```
assets/<repo>/models/<name>/makerworld/images/
├── showcase.jpg
└── diagonal_supports.png
```

Common images shared across all models are stored in the assets repo:
```
assets/common/makerworld/images/
├── homeracker_logo_banner.webp    # HomeRacker logo (linked to homeracker.org)
├── collection_banner.webp         # Official HomeRacker Collection banner
└── kofi_qr_code.webp              # Ko-fi donation QR code
```

Reference via: `https://raw.githubusercontent.com/kellerlabs/assets/main/common/makerworld/images/<file>`

## 🔁 Common Description Elements

All HomeRacker MakerWorld descriptions share recurring elements. When extracting, verify these are present:

1. **Centered header block** — everything from the top of the description until the first video embed or model-specific content must be centered using HTML style blocks. The logo is always `width="300"` and linked to `homeracker.org`. Pattern:
   ```html
   <p style="text-align: center">Intro text</p>
   <h2 style="text-align: center">Model Title</h2>
   <p style="text-align: center"><a href="https://homeracker.org/"><img src=".../common/makerworld/images/homeracker_logo_banner.webp" alt="HomeRacker Logo" width="300"></a></p>
   <p style="text-align: center">Subtitle / links</p>
   ```
2. **Collection banner** — linked image to the Official HomeRacker Collection. Uses `common/makerworld/images/collection_banner.webp`
3. **Ko-fi QR code** — in the ☕ Support section. Uses `common/makerworld/images/kofi_qr_code.webp`
4. **"🏡 What is HomeRacker?" section** (non-core models only) — includes the HomeRacker Core video embed (`g8k6X_axYug`) immediately after the heading, followed by links to homeracker.org and the collection

These elements are often dropped by `fetch_webpage` (logo as orphan linked image, video as invisible iframe). Always check for them during extraction.

## ⚠️ Important Notes

- **Cross-repo skill**: Requires both the source repo (`homeracker` or `homeracker-exclusive`) and the [`kellerlabs/assets`](https://github.com/kellerlabs/assets) repo. Maintainers push images directly to `assets/main`. Outside collaborators must open a PR on the assets repo for image changes.
- `DESCRIPTION.md` is the **source of truth**. Always edit it in git, never in MakerWorld directly.
- After editing `DESCRIPTION.md`, re-run `md-to-mw.py` and re-paste into MakerWorld.
- The conversion script embeds local images as base64 data URIs so the HTML is fully self-contained — no broken links, no browser permissions needed. External image URLs (http/https) are passed through unchanged.
- Since images are now hosted in the `kellerlabs/assets` repo with absolute URLs, `md-to-mw.py` passes them through directly — no base64 encoding needed for assets-hosted images.
- **Alignment**: Use inline HTML blocks (`<h2 style="text-align: center">`, `<p style="text-align: center">`) to preserve centered headings, images, and text from MakerWorld. These render correctly on GitHub and pass through to `md-to-mw.py` HTML output.
- **Image sizing**: Use `width="800"` as the standard for all description images whose native width is ≥ 800px; for smaller images use their native width (omit `height` so images scale proportionally). Exceptions: HomeRacker logo (`width="300"`), Ko-fi QR code (`width="328"`).
- MakerWorld CDN images (from `makerworld.bblmw.com`) should be downloaded to the assets repo during extraction. External reference images (memes, badges, etc.) can stay as external URLs.
- **Humanize after writing**: once a `DESCRIPTION.md` is created or edited, run the [`humanizer`](../humanizer/SKILL.md) skill over it to strip AI tells before publishing.

## 🐛 Known Limitations

### `fetch_webpage` drops linked images

`fetch_webpage` converts HTML to markdown but loses `<img>` elements nested inside `<a>` tags. This produces empty links like `[](https://some-url)` where a linked image (`<a href="..."><img src="..."></a>`) existed in the original HTML.

**Common patterns affected**:
- Logo/banner images linking to external sites (e.g. HomeRacker logo → homeracker.org)
- Model thumbnail images linking to other MakerWorld models
- Collection banner images linking to MakerWorld collections

**Workaround**: Step 5a in the Extract Flow asks the user to manually supply the missing image URLs by inspecting the page in a browser.

### `fetch_webpage` silently drops embedded iframes

`fetch_webpage` completely discards `<iframe>` elements (YouTube embeds, etc.) with **no trace** — no placeholder, no URL, just blank whitespace. Unlike linked images which leave a detectable `[](url)` pattern, embedded videos are entirely invisible in the output.

**Common patterns affected**:
- YouTube video embeds in description sections
- Any other `<iframe>`-based content

**Workaround**: Step 5b in the Extract Flow explicitly asks the user whether embedded videos exist on the page. Videos are stored as linked YouTube thumbnails in `DESCRIPTION.md`. During publish, `md-to-mw.py` automatically converts these to CKEditor 5 `<figure class="media">` embeds with `data-oembed-url`, which MakerWorld's editor recognises as native video embeds.

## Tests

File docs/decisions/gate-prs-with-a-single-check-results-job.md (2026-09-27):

# 📋 Gate PRs with a Single check-results Job

## 📌 Status

**Accepted**, 2026-09-27

## 🤔 Context

- Eight workflows run on `pull_request`, each as its own file with its own `paths:` filter.
- A path-filtered workflow cannot be a required check: when it does not run, the PR waits forever for it. So `integration-tests`, `mutation-tests`, `test-setup-openscad`, `validate-models` and `web` guard nothing at merge time.
- Renovate automerges on green checks, so an unrequired failing check only blocks it by luck of timing.
- The planned scadfmt agent flow ([#177](https://github.com/kellerlabs/homeracker/issues/177)) will need a human approval step that blocks the merge.

## 🔧 Decision

One PR workflow, `ci.yml`, modeled on [camunda/camunda](https://github.com/camunda/camunda/blob/main/.github/workflows/ci.yml):

- **`detect-changes`** computes path filters once and exposes one output per area.
- **Every PR job** is an existing workflow switched to `workflow_call`, called from `ci.yml` behind an `if:` on its filter.
- **`check-results`** runs with `if: always()`, needs every job, and fails on any `failure` or `cancelled`. `skipped` counts as success.
- **Branch protection** on `main` requires `check-results`, plus `validate-title`, which stays a standalone workflow: it must rerun on title edits, and rerunning the gate on every PR edit is too costly since Renovate rewrites PR bodies constantly.

### Alternatives Considered

| Approach | Verdict | Reason |
|---|---|---|
| Require each workflow directly | ❌ Rejected | Path-filtered workflows block PRs they skip |
| Drop path filters, run everything always | ❌ Rejected | Slow PRs, wasted runner minutes on OpenSCAD renders and E2E |
| Third-party "wait for all checks" action | ❌ Rejected | Polls the checks API, extra dependency, races with late-starting workflows |

## 📊 Consequences

- **Positive**: every PR job is required when it applies, including path-filtered ones.
- **Positive**: a job that needs a person (an environment with required reviewers) blocks the merge through `check-results`.
- **Negative**: a new job must be added to both the `detect-changes` filter and the `check-results` `needs:`; missing the latter silently makes it optional. See the [CI overview](../../.github/workflows/README.md).
- **Negative**: renaming `check-results` breaks branch protection until the rule is updated.

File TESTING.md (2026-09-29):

# Testing Guide

## General Testing Principles

Always test changes before committing:
- **Use existing test scripts** in `cmd/test/` when available
- **Write simple tests** if none exist (bash scripts, Python tests, or manual verification steps)
- **Document test steps** in commit messages or PR descriptions

## Site and Configurator E2E Tests

Playwright drives the built site in Chromium: every page, the hero canvas, and configurator journeys including error paths. The `site` job in [`web.yml`](.github/workflows/web.yml) runs it on every PR touching `site/` or `configurator/`, once at the root and once under a preview subpath.

```bash
cd site
npx playwright install --only-shell chromium   # once per Playwright version
npm run build
npm run e2e
```

A test fails on any page error, console error or failing same-origin request. `inventory.spec.ts` fails when a configurator control is not used by any test, so a new control needs a journey. Without OpenSCAD the build has no part meshes and the tests expect the schematic fallback; CI sets `PARTS_REQUIRED=1`. On failure, CI uploads the HTML report with screenshots and traces as the `playwright-report` artifact, and a PR comment lists each failing test with its error and a link to that artifact. The comment is created on the first failure and updated in place, back to ✅ once the suite passes. Fork PRs get the job summary only.

To check the failure report end to end, add the `e2e-probe-failure` label to the PR: `probe.spec.ts` then fails on purpose. Remove the label to go green again.

See [e2e.md](.claude/rules/e2e.md) for how to write tests and [e2e-test-site-and-configurator-with-playwright](docs/decisions/e2e-test-site-and-configurator-with-playwright.md) for why.

## scadfmt Tests

### Unit Tests

Unit tests cover every formatting rule, the CLI and the VS Code setup, and format every `.scad` file in the repo twice to prove the output is stable. The `scadfmt-unit-tests` pre-commit hook runs them on Linux when a commit touches `cmd/scadfmt/`, with a branch coverage gate in `cmd/scadfmt/pyproject.toml`. [Mutation testing](#mutation-testing) covers scadfmt like scadm. The `unit tests (windows)` job in [`scadfmt-tests.yml`](.github/workflows/scadfmt-tests.yml) runs them on Windows.

```bash
cd cmd/scadfmt
python -m pytest tests/ -q --cov
```

### Integration Tests (Canary)

The canary in `cmd/scadfmt/tests/canary/` uses every OpenSCAD construct. `check.sh` asserts that the pinned OpenSCAD parses it, that scadfmt turns it into `canary.expected.scad` and leaves that file unchanged, and that OpenSCAD's `.ast` output is identical before and after formatting. The `integration tests (OpenSCAD)` job runs it when `cmd/scadfmt/` or the OpenSCAD pin in `scadm.json` changes. Locally it needs `scadm install` first:

```bash
cmd/scadfmt/tests/canary/check.sh
```

A new language construct goes into `canary.scad`, then regenerate the expected file with `scadfmt format - < canary.scad > canary.expected.scad` and review the diff. When a nightly bump changes OpenSCAD's grammar, the [scadfmt agent](docs/decisions/agent-adapts-scadfmt-to-openscad-nightly.md) does this on the Renovate PR. The `scadfmt-e2e` label probes that flow on any PR, see the [CI overview](.github/workflows/README.md#-e2e-probe).

The same job runs `ast_check.sh` on the PR: every `.scad` file whose change is formatting only must give the pinned OpenSCAD the same `.ast` as before. That covers repo-wide reformats after a formatter or OpenSCAD change. Other PRs rely on scadfmt refusing any output whose tokens differ from its input. Locally:

```bash
cmd/scadfmt/tests/ast_check.sh origin/main
```

## scadm Tests

### Unit Tests

Fast, mocked tests. The `scadm-tests` pre-commit hook runs them when a commit touches `cmd/scadm/`, so a commit elsewhere in the repo will not exercise them. Run them by hand after changing anything scadm depends on.

```bash
cd cmd/scadm
python -m pytest tests/ -m "not integration" -v
```

### Integration Tests

CLI integration tests exercise real `scadm` commands against temporary workspaces. Run via CI workflow (`.github/workflows/integration-tests.yml`) on **ubuntu + windows** matrix.

| Marker | What | Network | Speed |
|---|---|---|---|
| `integration` (no `slow`) | Config parsing, `--info`, `--check`, vscode settings, cache | ⚡ version resolution only | ~5s |
| `integration` + `slow` | Binary download, library install | ✅ | ~60s |

#### Running Locally

```bash
cd cmd/scadm

# All integration tests
python -m pytest tests/test_cli_integration.py -m integration -v

# Fast only (no downloads)
python -m pytest tests/test_cli_integration.py -m "integration and not slow" -v
```

> **Prerequisite**: Install scadm in editable mode first: `pip install -e cmd/scadm`

#### When to Update

- Adding or modifying a CLI subcommand → add/update integration test
- Changing `scadm.json` config schema → update config-dependent tests
- Changing installer/resolver behavior → update relevant slow tests

### Code Coverage

The `scadm-tests` hook runs the unit tests with `--cov`. It fails when branch coverage drops below `fail_under` in [`cmd/scadm/pyproject.toml`](cmd/scadm/pyproject.toml). It also sets `PYTHONWARNDEFAULTENCODING=1`, so text I/O without an explicit `encoding=` fails the tests (it breaks on Windows with a non-UTF-8 locale).

```bash
cd cmd/scadm
PYTHONWARNDEFAULTENCODING=1 python -m pytest tests/ -m "not integration" --cov                    # enforce the gate
PYTHONWARNDEFAULTENCODING=1 python -m pytest tests/ -m "not integration" --cov --cov-report=html  # browse htmlcov/index.html
```

When your change lifts coverage well past the gate, raise `fail_under` in the same PR. Never lower it.

### Mutation Testing

`mutmut` changes the `scadm` and `scadfmt` sources one small edit at a time and reruns the unit tests. A **survived** mutant means no test noticed the change, so a test is missing or its assertion is too weak. Linux and macOS only (Windows: use WSL).

On a PR, [`mutation-tests.yml`](.github/workflows/mutation-tests.yml) mutates only the functions the PR changed, per package, and edits one PR comment with a section per package listing the survivors (fork PRs: job summary only). Kill each survivor with a test, or mark a true equivalent with `# pragma: no mutate`. Log calls, argparse help text and exception messages are skipped by `do_not_mutate_patterns`. A survivor in a changed function fails the job, also when a setup change mutated the whole package. The run stops after 5 minutes and the gate judges the results it has. Release-please PRs skip it. A weekly full run per package posts its stats to Discord `#homeracker-ci` and refreshes that package's badge.

```bash
cd cmd/scadm   # or cmd/scadfmt
export PYTHONWARNDEFAULTENCODING=1 PYTHONWARNINGS=ignore::EncodingWarning  # checks the package's I/O, not mutmut's
mutmut run                                        # full run, ~2 min (scadfmt ~1 min)
mutmut run "scadm.flatten.x_flatten_all__mutmut_*"  # one function, as a PR run does (scadm)
mutmut run "scadfmt.formatter.x__role__mutmut_*"    # the same for scadfmt
mutmut results                                    # list surviving mutants
mutmut show <mutant-name>                         # diff of one mutant
```

Known equivalents: `encoding="UTF-8"` for `"utf-8"`, dropping `open()`'s default `"r"` mode, `None` in place of `False`. The pragma only takes effect on a statement's first line.

See [gate-coverage-and-surviving-mutants-in-changed-functions](docs/decisions/gate-coverage-and-surviving-mutants-in-changed-functions.md) for why.

## Renovate Configuration Testing

When modifying `renovate.json5`, always test changes before merging to prevent incorrect PRs.

### Workflow

1. **Create feature branch**
   ```bash
   git checkout -b fix/renovate-<description>
   ```

2. **Make changes and commit**
   ```bash
   git add renovate.json5
   git commit -m "fix(renovate): <description>"
   ```

3. **Push to remote** (required for testing)
   ```bash
   git push -u origin fix/renovate-<description>
   ```

4. **Test locally**
   ```bash
   ./cmd/test/test-renovate-local.sh
   ```

5. **Validate output**
   - Check that dependencies are detected correctly
   - Verify version extraction matches expected format
   - Confirm updates are grouped as intended

### What to Check in the Output

**OpenSCAD version extraction**, which uses a separate datasource per platform:
- `OpenSCAD-Windows`: version without `.ai` suffix
- `OpenSCAD-Linux`: version with `.ai` suffix preserved

**Grouping and automerge**, for any rule in `renovate.json5` carrying a `groupSlug`:
- A **single branch** `renovate/<groupSlug>` holding every dependency in the group
- Major and minor updates combined in that one branch where the rule sets `separateMajorMinor: false`, with no separate `renovate/major-<groupSlug>` branch
- `"automerge": true` in the branch configuration where the rule enables it

### Why Remote Push is Required

Renovate test fetches from GitHub, so changes must exist remotely before testing validates them.

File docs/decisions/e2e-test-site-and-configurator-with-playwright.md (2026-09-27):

# 📋 E2E-test the site and configurator with Playwright on every web PR

## 📌 Status

**Accepted**: 2026-09-27

## 🤔 Context

- npm updates to `site/` and `configurator/` are not automerged beyond a patch allow-list, because no check renders a page: a runtime break passes eslint, tsc, Vitest and the build.
- Checking each Renovate preview by hand is slow and misses things.
- Typical runtime breaks: an uncaught error on load, a chunk or asset that 404s (worse under the `/preview/pr-<n>/` subpath), a broken `STLLoader` or parts manifest, a blank WebGL canvas, broken clipboard or share links.
- An E2E suite only helps while it keeps up with the UI. A feature that ships without a journey is a blind spot nobody notices.

## 🔧 Decision

**Framework: Playwright (`@playwright/test`) in `site/e2e/`.**

- Open source, actively maintained, built-in runner with retries, traces and request stubbing. The npm version pins the browser, so Renovate bumps both together.
- One package: the site mounts the configurator, so testing the site build covers both apps.
- Alternatives rejected:
  - Cypress: no real WebKit, heavier, parallel runs need the paid Cloud.
  - WebdriverIO: its strength is real mobile devices, which this project does not need.
  - Vitest browser mode: suits component tests, not journeys through the built site.
  - Visual snapshot services (Argos, Percy, Chromatic): CI renders WebGL in software, and three.js bumps change pixels legitimately, so baselines would churn.

**Environment: the built site on the CI runner, not the Pages preview.**

- The `site` job in [`web.yml`](../../.github/workflows/web.yml) builds `dist/` with the real part meshes, serves it with `astro preview` on localhost, and runs headless Chromium against it. A second build with `SITE_BASE=/preview/pr-0/` runs the suite again under a subpath.
- This gates the PR before merge, including Renovate PRs, is the same for every run of a commit, works for forks, and does not depend on the shared `pages` concurrency group.
- Alternative deferred: a smoke test against the deployed preview. It would add coverage of Pages itself (redirects, the real domain) at the cost of a slow, coupled job. Revisit if Pages serving ever breaks.

**What is tested.**

- 🩺 A fixture fails every test on an uncaught page error, a console error, or a same-origin request that fails or returns 4xx/5xx.
- 🗺️ Every page in `dist/` gets a smoke test (status, title, one `h1`, every internal link resolves). The list comes from the build, so a new page is covered automatically. Also runs at a mobile viewport.
- 🧊 The canvases carry `data-render="parts"` or `"schematic"`, and a screenshot must contain HomeRacker yellow, proving WebGL drew the rack.
- 🧭 Configurator journeys: default rack, a shared link with an exact parts list, footprint and row editing, panels (click, keyboard, shortcuts), copy link and Markdown, session restore, and error paths (unparsable input, out-of-range values, malformed links, printbed overflow, missing part meshes).

**Reporting failures.**

- 💬 A failing run posts one PR comment, edited in place: each failing test with its error, a link to the report artifact (screenshots, traces) and the run. It flips to ✅ when the suite passes and is never created for a PR that never failed. A separate job holds `pull-requests: write`; the build and tests keep read-only access. Fork PRs get the job summary only.
- 🧪 The `e2e-probe-failure` label makes one probe test fail on purpose, so the report pipeline can be checked on any PR. Label changes rerun only the `site` job.
- 🖼️ Screenshots stay in the workflow artifact (7-day retention). Inline images would need committing them to a repository, which grows its history for good.

**Keeping the suite current: deterministic gates first, guidance second.**

- 🔒 Control inventory ([`inventory.spec.ts`](../../site/e2e/inventory.spec.ts)): every configurator control rendered in any test must be used by at least one test, or CI fails. Exemptions are listed in the spec with a reason.
- 🔒 Page inventory: automatic, because the smoke test enumerates `dist/`.
- 📜 The path-scoped rule [`.claude/rules/e2e.md`](../../.claude/rules/e2e.md) loads for agents editing `site/` or `configurator/`, and the PR template asks for the E2E change.
- Alternatives rejected:
  - An agent skill alone: nothing enforces it for humans or agents that skip it.
  - Failing a PR that changes `src/` without touching `e2e/`: refactors trip it constantly and an override label becomes a reflex.
- Deferred: a coverage gate on the lines each PR changes (V8 coverage from Chromium), once the suite has been stable for a few weeks.

## 📊 Consequences

- ✅ Dependency PRs get a runtime check, so Renovate automerges minor and patch updates of the allow-listed npm packages, `@playwright/test` included. Majors and `three` stay manual.
- ✅ A new page or control fails CI until a test covers it.
- ❌ The inventory gate proves a control was used, not that its effect was asserted. Review still has to check the assertion.
- ❌ The `site` job grows by a few minutes (browser install, second build, two runs).
- ❌ Pages-specific serving behaviour is not covered.

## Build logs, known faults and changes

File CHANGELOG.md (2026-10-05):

# Changelog

## [3.19.0](https://github.com/kellerlabs/homeracker/compare/homeracker-v3.18.0...homeracker-v3.19.0) (2026-10-05)

### ✨ Features

* **scadfmt:** write VS Code settings into a .code-workspace file; fail PRs on surviving mutants ([#531](https://github.com/kellerlabs/homeracker/issues/531)) ([942938e](https://github.com/kellerlabs/homeracker/commit/942938e911508123dd11ee481c4f3281266c2cd3))

### 📦 Dependencies

* update dependency belfryscad/bosl2 to v2.0.762 ([#534](https://github.com/kellerlabs/homeracker/issues/534)) ([ba2905f](https://github.com/kellerlabs/homeracker/commit/ba2905f369d4d78e697092bc017a1b9e92274a80))
* update dependency kellerlab-pre-commit-hooks to v0.3.12 ([#539](https://github.com/kellerlabs/homeracker/issues/539)) ([a44b375](https://github.com/kellerlabs/homeracker/commit/a44b375f6c93df2d06381096cb54ed000c25c62e))
* update dependency markdown to v3.11 ([#537](https://github.com/kellerlabs/homeracker/issues/537)) ([fda2ce2](https://github.com/kellerlabs/homeracker/commit/fda2ce2abdf609257c82ae8b8e7a6fa8af98e14b))
* update dependency openscad to v2026.10.02 ([#538](https://github.com/kellerlabs/homeracker/issues/538)) ([bfb7069](https://github.com/kellerlabs/homeracker/commit/bfb706944b56dff02e79a2f135ef802377aaea24))
* update dependency typescript-eslint to v8.71.0 ([#541](https://github.com/kellerlabs/homeracker/issues/541)) ([8a6fb3d](https://github.com/kellerlabs/homeracker/commit/8a6fb3d8797a60fad2bc6433e1a1114a04eb9b9e))
* update npm dependencies ([#536](https://github.com/kellerlabs/homeracker/issues/536)) ([13b67af](https://github.com/kellerlabs/homeracker/commit/13b67af20d7957aaa98473a7c47bb74e619e44a9))
* update pre-commit hooks ([#533](https://github.com/kellerlabs/homeracker/issues/533)) ([e4f6b25](https://github.com/kellerlabs/homeracker/commit/e4f6b258843c29616e4f4a6dff542c1383826c15))

## [3.18.0](https://github.com/kellerlabs/homeracker/compare/homeracker-v3.17.0...homeracker-v3.18.0) (2026-09-28)

### ✨ Features

* **scadfmt:** adapt scadfmt to new OpenSCAD nightlies with an agent ([#526](https://github.com/kellerlabs/homeracker/issues/526)) ([b1935c0](https://github.com/kellerlabs/homeracker/commit/b1935c050fb564dd223d5e3fd582e056fd5ff8d8))
* **scadfmt:** add coverage and mutation testing with badges ([#521](https://github.com/kellerlabs/homeracker/issues/521)) ([f81e176](https://github.com/kellerlabs/homeracker/commit/f81e176b2ba7ac3f1c064a170dbdb700e5f4c110))
* **scadfmt:** format all .scad files and enforce it in pre-commit ([#524](https://github.com/kellerlabs/homeracker/issues/524)) ([3e80080](https://github.com/kellerlabs/homeracker/commit/3e80080a2936ac4e83547dde47b9f503a3f236bc))

### 🐛 Bug Fixes

* **scadfmt:** keep existing tests read-only for the agent ([#529](https://github.com/kellerlabs/homeracker/issues/529)) ([a1cd300](https://github.com/kellerlabs/homeracker/commit/a1cd3000fec42a74e88424d1f3bd2e5d26196208))
* **scadfmt:** let the agent finish unattended ([#527](https://github.com/kellerlabs/homeracker/issues/527)) ([fb63e67](https://github.com/kellerlabs/homeracker/commit/fb63e67817d0784f66f67737e9411d5b4896e45c))

### 📦 Dependencies

* update dependency astro to v7.3.4 ([#522](https://github.com/kellerlabs/homeracker/issues/522)) ([1260e61](https://github.com/kellerlabs/homeracker/commit/1260e610365ed08dba3d5252eafb6ba2d6f1a962))

### 🔧 Miscellaneous

* skip the scadfmt reformat in git blame ([#525](https://github.com/kellerlabs/homeracker/issues/525)) ([aebd26d](https://github.com/kellerlabs/homeracker/commit/aebd26d02e64a79dc1bf05490cd73f859205da5f))

## [3.17.0](https://github.com/kellerlabs/homeracker/compare/homeracker-v3.16.0...homeracker-v3.17.0) (2026-09-27)

### ✨ Features

* **scadfmt:** add token-based OpenSCAD formatter ([#520](https://github.com/kellerlabs/homeracker/issues/520)) ([830ff0d](https://github.com/kellerlabs/homeracker/commit/830ff0dbf5d20c8a0a128e82f3842a20ab96339d))

### 🔄 CI/CD

* gate PRs with a single check-results job ([#519](https://github.com/kellerlabs/homeracker/issues/519)) ([0b052e6](https://github.com/kellerlabs/homeracker/commit/0b052e6bac7f7928ca5154440c87985c0740c053))

### 🧪 Tests

* **site:** add Playwright E2E suite for site and configurator ([#515](https://github.com/kellerlabs/homeracker/issues/515)) ([edc2b6e](https://github.com/kellerlabs/homeracker/commit/edc2b6eaf7b3f8da2132d8c3a4190bb3192b64f1))

## [3.16.0](https://github.com/kellerlabs/homeracker/compare/homeracker-v3.15.1...homeracker-v3.16.0) (2026-09-27)

### ✨ Features

* **scadm:** gate unit coverage at 90% and run weekly mutation tests ([#507](https://github.com/kellerlabs/homeracker/issues/507)) ([0600151](https://github.com/kellerlabs/homeracker/commit/060015180e8fdbf82a5844b68e21862c0e939546))
* **scadm:** scope mutation tests to changed functions, report weekly to Discord ([#509](https://github.com/kellerlabs/homeracker/issues/509)) ([a252759](https://github.com/kellerlabs/homeracker/commit/a252759ec6aac611df17898c0211c2b4a0c0f00e))

### 🐛 Bug Fixes

* **ci:** drop persisted checkout credentials and enforce zizmor artipacked ([#513](https://github.com/kellerlabs/homeracker/issues/513)) ([a7099c5](https://github.com/kellerlabs/homeracker/commit/a7099c5025952593b44ab544f6d79e9bd7d08db5))
* **ci:** pass action inputs via env and enforce zizmor template-injection ([#510](https://github.com/kellerlabs/homeracker/issues/510)) ([74e77b1](https://github.com/kellerlabs/homeracker/commit/74e77b1e9474b3bb67c7fc0fdd77b05a5aec6229))
* **ci:** scope GitHub App tokens and enforce zizmor github-app ([#512](https://github.com/kellerlabs/homeracker/issues/512)) ([5b5ee9d](https://github.com/kellerlabs/homeracker/commit/5b5ee9df977290421c62b1b4873aa9441dd2df68))

### 📦 Dependencies

* update dependency belfryscad/bosl2 to v2.0.757 ([#500](https://github.com/kellerlabs/homeracker/issues/500)) ([3563a22](https://github.com/kellerlabs/homeracker/commit/3563a22c61d02a59c9d02159eb944c1a509f0d79))
* update dependency openscad to v2026.09.23 ([#502](https://github.com/kellerlabs/homeracker/issues/502)) ([0f0f096](https://github.com/kellerlabs/homeracker/commit/0f0f096e5aa38aac4b13fb4459af0d0df2cdb999))
* update dependency typescript-eslint to v8.70.1 ([#506](https://github.com/kellerlabs/homeracker/issues/506)) ([015683f](https://github.com/kellerlabs/homeracker/commit/015683f3335d8fed804b34a2f7120d9a5f536722))
* update npm dependencies ([#503](https://github.com/kellerlabs/homeracker/issues/503)) ([0b6aadd](https://github.com/kellerlabs/homeracker/commit/0b6aaddb104f9fb699612ea8df9db84fe13649c4))

### 📚 Documentation

* **ci:** explain why zizmor self-repository stays disabled ([#514](https://github.com/kellerlabs/homeracker/issues/514)) ([d97e1e6](https://github.com/kellerlabs/homeracker/commit/d97e1e608c3b69fc074883fc82c677152c5595f2))

### 🔄 CI/CD

* **mutation:** skip mutation tests on release-please PRs ([#511](https://github.com/kellerlabs/homeracker/issues/511)) ([acc4c44](https://github.com/kellerlabs/homeracker/commit/acc4c44a2d83e3706173e9b2b218527b5b5ff7e4))

## [3.15.1](https://github.com/kellerlabs/homeracker/compare/homeracker-v3.15.0...homeracker-v3.15.1) (2026-09-21)

### 📦 Dependencies

* update dependency @types/node to v26.6.1 ([#499](https://github.com/kellerlabs/homeracker/issues/499)) ([8a5b37a](https://github.com/kellerlabs/homeracker/commit/8a5b37a5463c0d19549187a19b53f72a58e7b0a5))
* update npm dependencies ([#493](https://github.com/kellerlabs/homeracker/issues/493)) ([5f130ef](https://github.com/kellerlabs/homeracker/commit/5f130ef2abb9e468e9e39df1b77f7d8f95b43be6))

## [3.15.0](https://github.com/kellerlabs/homeracker/compare/homeracker-v3.14.1...homeracker-v3.15.0) (2026-09-20)

### ✨ Features

* add bracket model and retire flexmount ([#496](https://github.com/kellerlabs/homeracker/issues/496)) ([df78bfa](https://github.com/kellerlabs/homeracker/commit/df78bfa42d90ba74a9b7f9cb63ba26147270a648))

### 📦 Dependencies

* update dependency @types/three to v0.186.0 ([#494](https://github.com/kellerlabs/homeracker/issues/494)) ([ceaa4fa](https://github.com/kellerlabs/homeracker/commit/ceaa4fa3bd00ee11f489c2a12954caf3865bfaf4))
* update dependency belfryscad/bosl2 to v2.0.755 ([#491](https://github.com/kellerlabs/homeracker/issues/491)) ([26d6763](https://github.com/kellerlabs/homeracker/commit/26d676359cbdc67e563a349f45804d93a2bfdbb8))
* update dependency openscad to v2026.09.18 ([#492](https://github.com/kellerlabs/homeracker/issues/492)) ([7784c20](https://github.com/kellerlabs/homeracker/commit/7784c20d6d7ceac044d1f2f87ee26eb965b2cebf))

## [3.14.1](https://github.com/kellerlabs/homeracker/compare/homeracker-v3.14.0...homeracker-v3.14.1) (2026-09-14)

### 🐛 Bug Fixes

* **configurator:** mount panels and their lock pins the way the parts do ([#489](https://github.com/kellerlabs/homeracker/issues/489)) ([f845659](https://github.com/kellerlabs/homeracker/commit/f84565986d7af557fd7c98cdec3880b53901ca45))

### 📦 Dependencies

* update dependency belfryscad/bosl2 to v2.0.754 ([#481](https://github.com/kellerlabs/homeracker/issues/481)) ([d0cd7a2](https://github.com/kellerlabs/homeracker/commit/d0cd7a20530b3617a03efedac62f801d7117099c))
* update dependency openscad to v2026.09.11 ([#482](https://github.com/kellerlabs/homeracker/issues/482)) ([150a416](https://github.com/kellerlabs/homeracker/commit/150a4164c6b625974f358074c171c4d1f2974c98))
* update dependency three to v0.186.0 ([#490](https://github.com/kellerlabs/homeracker/issues/490)) ([f83961a](https://github.com/kellerlabs/homeracker/commit/f83961a1c38634b957bca6603d521a7070feb5ac))
* update npm dependencies ([#488](https://github.com/kellerlabs/homeracker/issues/488)) ([7d08f22](https://github.com/kellerlabs/homeracker/commit/7d08f226db90ff54f9248d05bc1addbf07c28867))
* update pre-commit hook renovatebot/pre-commit-hooks to v44.57.3 ([#476](https://github.com/kellerlabs/homeracker/issues/476)) ([ab296e0](https://github.com/kellerlabs/homeracker/commit/ab296e09b858535f99bca30abed239ee73dbf743))
* update vitest to v5 and skip the TypeScript 7.0 line ([#485](https://github.com/kellerlabs/homeracker/issues/485)) ([3ef4b7c](https://github.com/kellerlabs/homeracker/commit/3ef4b7cb2958afeddb7f6e3c312177bba05335b2))

### ♻️ Code Refactoring

* **ci:** source the igga version manager from its published preset ([#479](https://github.com/kellerlabs/homeracker/issues/479)) ([742f80e](https://github.com/kellerlabs/homeracker/commit/742f80ee188a26a471812ad4e028b2849fc311de))
* **instructions:** make AGENTS.md canonical and align docs with house-style ([#484](https://github.com/kellerlabs/homeracker/issues/484)) ([ef337d5](https://github.com/kellerlabs/homeracker/commit/ef337d57ba903edb2602e5dc6b36c18c2fe36a8d))

## [3.14.0](https://github.com/kellerlabs/homeracker/compare/homeracker-v3.13.8...homeracker-v3.14.0) (2026-09-05)

### ✨ Features

* add a 3d configurator and rework github pages ([#460](https://github.com/kellerlabs/homeracker/issues/460)) ([0336a9f](https://github.com/kellerlabs/homeracker/commit/0336a9f7b906b6a192b13b82d925336333ddfcc2))
* add release-age guard and npm automerge allow-lists to renovate ([#470](https://github.com/kellerlabs/homeracker/issues/470)) ([691a1da](https://github.com/kellerlabs/homeracker/commit/691a1da95a9aa461a1b3b543153631620aeba47a))
* batch npm updates into one PR and automerge patches only ([#477](https://github.com/kellerlabs/homeracker/issues/477)) ([3e1c37c](https://github.com/kellerlabs/homeracker/commit/3e1c37c14585643192b8984947716c4cde100c80))
* **ci:** deploy a preview of each pull request to GitHub Pages ([#472](https://github.com/kellerlabs/homeracker/issues/472)) ([4f986cb](https://github.com/kellerlabs/homeracker/commit/4f986cb87d92e7f68e51bfae819ca936e4a2e884))
* **ci:** pin every action to a commit SHA and enforce it with zizmor ([#475](https://github.com/kellerlabs/homeracker/issues/475)) ([569b564](https://github.com/kellerlabs/homeracker/commit/569b564762600cf9321bf3b33f32d614d3d1b03b))
* make Dirnei codeowner of configurator and site ([#469](https://github.com/kellerlabs/homeracker/issues/469)) ([210814b](https://github.com/kellerlabs/homeracker/commit/210814b5864934160ac5b9bc4fa52e35f7aa9f20))
* **site:** serve the site from a configurable base path ([#471](https://github.com/kellerlabs/homeracker/issues/471)) ([c19a579](https://github.com/kellerlabs/homeracker/commit/c19a579abb6eeeeea76c57c0a4a69b421267ea73))

### 📦 Dependencies

* update dependency belfryscad/bosl2 to v2.0.752 ([#461](https://github.com/kellerlabs/homeracker/issues/461)) ([554256d](https://github.com/kellerlabs/homeracker/commit/554256decbd53cc348af2e8414791db6ee57a62d))
* update dependency kellerlab-pre-commit-hooks to v0.3.11 ([#462](https://github.com/kellerlabs/homeracker/issues/462)) ([44a62fa](https://github.com/kellerlabs/homeracker/commit/44a62fa10a229d9ad260cc68dd548ea9fb53d1ac))
* update dependency openscad to v2026.09.03 ([#463](https://github.com/kellerlabs/homeracker/issues/463)) ([1b52244](https://github.com/kellerlabs/homeracker/commit/1b522445bdc34e5cd02daf2ef605930da28996d9))
* update pre-commit hooks ([#458](https://github.com/kellerlabs/homeracker/issues/458)) ([2e178a8](https://github.com/kellerlabs/homeracker/commit/2e178a8b44ee625780c9eae1d235f89974c8c355))

## [3.13.8](https://github.com/kellerlabs/homeracker/compare/homeracker-v3.13.7...homeracker-v3.13.8) (2026-08-29)

### 📦 Dependencies

* update dependency belfryscad/bosl2 to v2.0.751 ([#455](https://github.com/kellerlabs/homeracker/issues/455)) ([42c014f](https://github.com/kellerlabs/homeracker/commit/42c014f5c9b5526e4ac9a930b11977bb09517457))
* update dependency openscad to v2026.08.29 ([#456](https://github.com/kellerlabs/homeracker/issues/456)) ([717bd43](https://github.com/kellerlabs/homeracker/commit/717bd43cbc3445e9735b2b6d652ef6c558ee0992))

## [3.13.7](https://github.com/kellerlabs/homeracker/compare/homeracker-v3.13.6...homeracker-v3.13.7) (2026-08-22)

### 📦 Dependencies

* update dependency belfryscad/bosl2 to v2.0.750 ([#452](https://github.com/kellerlabs/homeracker/issues/452)) ([a4a8254](https://github.com/kellerlabs/homeracker/commit/a4a82541bb7eb541b6777a5a90d07752d83acd08))
* update dependency openscad to v2026.08.19 ([#453](https://github.com/kellerlabs/homeracker/issues/453)) ([dc744c3](https://github.com/kellerlabs/homeracker/commit/dc744c3f684483b8438269eb98fdf0408f127a4e))

## [3.13.6](https://github.com/kellerlabs/homeracker/compare/homeracker-v3.13.5...homeracker-v3.13.6) (2026-08-15)

### 📦 Dependencies

* update dependency belfryscad/bosl2 to v2.0.749 ([#447](https://github.com/kellerlabs/homeracker/issues/447)) ([e0bd31b](https://github.com/kellerlabs/homeracker/commit/e0bd31be42643a95071b21cc8c5fb17128d3a338))
* update dependency kellerlab-pre-commit-hooks to v0.3.10 ([#448](https://github.com/kellerlabs/homeracker/issues/448)) ([ca496c3](https://github.com/kellerlabs/homeracker/commit/ca496c3cc6b0880aaedf48565386bceeaf1681d1))
* update dependency openscad to v2026.08.13 ([#449](https://github.com/kellerlabs/homeracker/issues/449)) ([be6c5fa](https://github.com/kellerlabs/homeracker/commit/be6c5fa62ff58b003567790d271cbaf72870db62))

## [3.13.5](https://github.com/kellerlabs/homeracker/compare/homeracker-v3.13.4...homeracker-v3.13.5) (2026-08-08)

### 📦 Dependencies

* update dependency openscad to v2026.08.03 ([#444](https://github.com/kellerlabs/homeracker/issues/444)) ([283cdfc](https://github.com/kellerlabs/homeracker/commit/283cdfc52f268e8ac4298eaa163c5efe291291fa))

## [3.13.4](https://github.com/kellerlabs/homeracker/compare/homeracker-v3.13.3...homeracker-v3.13.4) (2026-08-02)

### 📦 Dependencies

* update dependency kellerlab-pre-commit-hooks to v0.3.9 ([#439](https://github.com/kellerlabs/homeracker/issues/439)) ([b0501bf](https://github.com/kellerlabs/homeracker/commit/b0501bf4d1d80b8a4c4e2e93b0b83a08a7c0d753))
* update dependency markdown to v3.10.3 ([#440](https://github.com/kellerlabs/homeracker/issues/440)) ([7661fc4](https://github.com/kellerlabs/homeracker/commit/7661fc461be1830fe1d3127b7aa1f6058aa03084))
* update dependency openscad to v2026.07.26 ([#441](https://github.com/kellerlabs/homeracker/issues/441)) ([70411b5](https://github.com/kellerlabs/homeracker/commit/70411b53418b7d37a4f03054af5e7333a57ac370))
* update pre-commit hook renovatebot/pre-commit-hooks to v44 ([#442](https://github.com/kellerlabs/homeracker/issues/442)) ([865aeb7](https://github.com/kellerlabs/homeracker/commit/865aeb764670797f72b1681bf02206ea674b45ba))

## [3.13.3](https://github.com/kellerlabs/homeracker/compare/homeracker-v3.13.2...homeracker-v3.13.3) (2026-07-25)

### 📦 Dependencies

* update dependency openscad to v2026.07.20 ([#435](https://github.com/kellerlabs/homeracker/issues/435)) ([58676af](https://github.com/kellerlabs/homeracker/commit/58676af34e886960d041f92402cc71ad2678e4ab))
* update dependency openscad to v2026.07.24 ([#438](https://github.com/kellerlabs/homeracker/issues/438)) ([2bc930c](https://github.com/kellerlabs/homeracker/commit/2bc930cf2b221e337f321f698aeed4c5b29f7a3a))

## [3.13.2](https://github.com/kellerlabs/homeracker/compare/homeracker-v3.13.1...homeracker-v3.13.2) (2026-07-18)

### 📦 Dependencies

* update dependency openscad to v2026.07.16 ([#433](https://github.com/kellerlabs/homeracker/issues/433)) ([d692746](https://github.com/kellerlabs/homeracker/commit/d69274611c4ed51925530e88f2877c6cc0716a46))

## [3.13.1](https://github.com/kellerlabs/homeracker/compare/homeracker-v3.13.0...homeracker-v3.13.1) (2026-07-11)

### 📦 Dependencies

* update dependency belfryscad/bosl2 to v2.0.747 ([#429](https://github.com/kellerlabs/homeracker/issues/429)) ([dc68574](https://github.com/kellerlabs/homeracker/commit/dc685747f6ae1e57b5b3571ee7d9c2edb7c6309f))
* update dependency openscad to v2026.07.09 ([#430](https://github.com/kellerlabs/homeracker/issues/430)) ([57e8c0c](https://github.com/kellerlabs/homeracker/commit/57e8c0c9dfd352331456ddb605fef2f108e60223))

## [3.13.0](https://github.com/kellerlabs/homeracker/compare/homeracker-v3.12.3...homeracker-v3.13.0) (2026-07-04)

### ✨ Features

* insta360 Link 2C Pro adapter for Elgato Prompter ([#427](https://github.com/kellerlabs/homeracker/issues/427)) ([adf7920](https://github.com/kellerlabs/homeracker/commit/adf7920f38f5658c589a5337603248711de26ead))

### 📦 Dependencies

* update dependency belfryscad/bosl2 to v2.0.746 ([#424](https://github.com/kellerlabs/homeracker/issues/424)) ([4fe34d9](https://github.com/kellerlabs/homeracker/commit/4fe34d969795744e4cbf9aef5c41a7fde729131a))
* update dependency kellerlab-pre-commit-hooks to v0.3.8 ([#425](https://github.com/kellerlabs/homeracker/issues/425)) ([f94b356](https://github.com/kellerlabs/homeracker/commit/f94b356eb1f01f86f2a162089a303eb4dfafbaff))
* update dependency openscad to v2026.07.01 ([#426](https://github.com/kellerlabs/homeracker/issues/426)) ([aef56e5](https://github.com/kellerlabs/homeracker/commit/aef56e5a9b83cfbb886637a47e81ed164156e9b3))
* update pre-commit hooks ([#422](https://github.com/kellerlabs/homeracker/issues/422)) ([e7d025a](https://github.com/kellerlabs/homeracker/commit/e7d025a630485d59f0a42c09f4f4f651c2c9ba36))

## [3.12.3](https://github.com/kellerlabs/homeracker/compare/homeracker-v3.12.2...homeracker-v3.12.3) (2026-06-27)

### 🐛 Bug Fixes

* **panel/split:** color uncolored cutters; fix lockpin cap manifold seam ([#420](https://github.com/kellerlabs/homeracker/issues/420)) ([7bb2fe5](https://github.com/kellerlabs/homeracker/commit/7bb2fe54a89b629d9aa0e29fc763abe74ff7bd55))

## [3.12.2](https://github.com/kellerlabs/homeracker/compare/homeracker-v3.12.1...homeracker-v3.12.2) (2026-06-27)

### 🐛 Bug Fixes

* **panel:** keep one uniform color when mount plates are removed ([#419](https://github.com/kellerlabs/homeracker/issues/419)) ([3fd37cc](https://github.com/kellerlabs/homeracker/commit/3fd37ccd29e9f72f2b3fa7f03a358e2638370d6f))

### 📦 Dependencies

* update dependency belfryscad/bosl2 to v2.0.745 ([#416](https://github.com/kellerlabs/homeracker/issues/416)) ([e7b62ca](https://github.com/kellerlabs/homeracker/commit/e7b62cafc43fbb4f25b1e3842f82db882affc2ee))
* update dependency kellerlab-pre-commit-hooks to v0.3.7 ([#417](https://github.com/kellerlabs/homeracker/issues/417)) ([0193375](https://github.com/kellerlabs/homeracker/commit/01933759a918eba33ec7753d293f1032cab61f70))
* update dependency openscad to v2026.06.21 ([#407](https://github.com/kellerlabs/homeracker/issues/407)) ([b5c40bf](https://github.com/kellerlabs/homeracker/commit/b5c40bf3180563025cf452fa3449a959508676e1))

### 📚 Documentation

* **skills:** add humanizer skill ([#414](https://github.com/kellerlabs/homeracker/issues/414)) ([bcc42ec](https://github.com/kellerlabs/homeracker/commit/bcc42ec7eb13b7afcebe868623cf5976f369f427))

## [3.12.1](https://github.com/kellerlabs/homeracker/compare/homeracker-v3.12.0...homeracker-v3.12.1) (2026-06-21)

### 🐛 Bug Fixes

* **split:** strengthen lock pin and ease split-panel pin insertion ([#413](https://github.com/kellerlabs/homeracker/issues/413)) ([2bca702](https://github.com/kellerlabs/homeracker/commit/2bca70255b2c828d0c6d0c63453811517e1fea51))

### 📚 Documentation

* **agent:** fix exclusive collection name and Core link in description template ([#411](https://github.com/kellerlabs/homeracker/issues/411)) ([8529445](https://github.com/kellerlabs/homeracker/commit/85294457aa204886086307bb5957ffef485872ab))

## [3.12.0](https://github.com/kellerlabs/homeracker/compare/homeracker-v3.11.1...homeracker-v3.12.0) (2026-06-20)

### ✨ Features

* **skills:** add grill-my-plan skill + exclude tests from pylint ([#410](https://github.com/kellerlabs/homeracker/issues/410)) ([13cdb17](https://github.com/kellerlabs/homeracker/commit/13cdb17c8f9c7b64d08cb359409ad6fe828aac68))

## [3.11.1](https://github.com/kellerlabs/homeracker/compare/homeracker-v3.11.0...homeracker-v3.11.1) (2026-06-20)

### 🐛 Bug Fixes

* **panel:** rename lockpin_hole to panel_lockpin_hole to avoid name collision ([#406](https://github.com/kellerlabs/homeracker/issues/406)) ([054c4e6](https://github.com/kellerlabs/homeracker/commit/054c4e6aee75f20416ef32621a4030ecfe793ce3))

### 📦 Dependencies

* update dependency kellerlab-pre-commit-hooks to v0.3.6 ([#402](https://github.com/kellerlabs/homeracker/issues/402)) ([0d07d38](https://github.com/kellerlabs/homeracker/commit/0d07d3874c412358dcfff3ebce2eca18b67b35bc))
* update openscad nightly to v2026.06.19 ([#404](https://github.com/kellerlabs/homeracker/issues/404)) ([ea020a3](https://github.com/kellerlabs/homeracker/commit/ea020a3077d36a07ae0d971a0650404c41f6a435))

## [3.11.0](https://github.com/kellerlabs/homeracker/compare/homeracker-v3.10.0...homeracker-v3.11.0) (2026-06-18)

### ✨ Features

* **keystone:** native geometry backend toggle + grill-my-model skill ([#400](https://github.com/kellerlabs/homeracker/issues/400)) ([546f37d](https://github.com/kellerlabs/homeracker/commit/546f37d167a2b7689d27fc495944464fd4ba2ca4))

## [3.10.0](https://github.com/kellerlabs/homeracker/compare/homeracker-v3.9.0...homeracker-v3.10.0) (2026-06-14)

### ✨ Features

* **panel:** expose rackpanel usable-frame helpers + child passthrough ([#399](https://github.com/kellerlabs/homeracker/issues/399)) ([044e3ae](https://github.com/kellerlabs/homeracker/commit/044e3ae4daffa2825ade17f21348de3065ff2137))

### 📦 Dependencies

* update openscad nightly to v2026.06.12 ([#397](https://github.com/kellerlabs/homeracker/issues/397)) ([e8a2f3f](https://github.com/kellerlabs/homeracker/commit/e8a2f3fd61209e9a5886579c30cc7a862ebee687))

## [3.9.0](https://github.com/kellerlabs/homeracker/compare/homeracker-v3.8.0...homeracker-v3.9.0) (2026-06-13)

### ✨ Features

* **keystone:** add label_position above/below for label slots ([#396](https://github.com/kellerlabs/homeracker/issues/396)) ([5377742](https://github.com/kellerlabs/homeracker/commit/53777422ca29416b715b39eb2c9c5ee7f275766a))

### 📦 Dependencies

* update openscad nightly to v2026.06.11 ([#394](https://github.com/kellerlabs/homeracker/issues/394)) ([29a20b8](https://github.com/kellerlabs/homeracker/commit/29a20b8561320c9c8185bd2a4a6e977699d50083))

## [3.8.0](https://github.com/kellerlabs/homeracker/compare/homeracker-v3.7.0...homeracker-v3.8.0) (2026-06-07)

### ✨ Features

* **panel:** split panels, back-brace stiffener & panel depth ([#393](https://github.com/kellerlabs/homeracker/issues/393)) ([3d2ae7d](https://github.com/kellerlabs/homeracker/commit/3d2ae7de7260b11c13058cd02d4b7354ae7fab1f))

### 📦 Dependencies

* update dependency belfryscad/bosl2 to v2.0.743 ([#390](https://github.com/kellerlabs/homeracker/issues/390)) ([124202e](https://github.com/kellerlabs/homeracker/commit/124202ed21d1df0dabdc3bce85621a0f942d4db9))
* update dependency kellerlab-pre-commit-hooks to v0.3.5 ([#391](https://github.com/kellerlabs/homeracker/issues/391)) ([65186c0](https://github.com/kellerlabs/homeracker/commit/65186c0997be0c970057c43e3cfb1a13fffde2fb))
* update openscad nightly to v2026.06.06 ([#392](https://github.com/kellerlabs/homeracker/issues/392)) ([a02ed6d](https://github.com/kellerlabs/homeracker/commit/a02ed6de9b25f1319fcb8abc0efdc56d47644fbe))
* update pre-commit hooks ([#387](https://github.com/kellerlabs/homeracker/issues/387)) ([a654907](https://github.com/kellerlabs/homeracker/commit/a6549077d5dc21bd5f6a4fe0038f8ba00c39ab22))

## [3.7.0](https://github.com/kellerlabs/homeracker/compare/homeracker-v3.6.2...homeracker-v3.7.0) (2026-05-31)

### ✨ Features

* **keystone:** add dimensions helper, label plate modes, and shorten inner hooks ([#385](https://github.com/kellerlabs/homeracker/issues/385)) ([ce7106c](https://github.com/kellerlabs/homeracker/commit/ce7106c7b9cc4b5bb2dd9f0bf478d2c0e26ca7ff))

## [3.6.2](https://github.com/kellerlabs/homeracker/compare/homeracker-v3.6.1...homeracker-v3.6.2) (2026-05-30)

### 🐛 Bug Fixes

* **panel:** stabilize anchor positions and correct mount_extension ([#383](https://github.com/kellerlabs/homeracker/issues/383)) ([9145cc5](https://github.com/kellerlabs/homeracker/commit/9145cc5c9f8a0e9586a6c8db66774ac1de555fa5))

## [3.6.1](https://github.com/kellerlabs/homeracker/compare/homeracker-v3.6.0...homeracker-v3.6.1) (2026-05-30)

### 🐛 Bug Fixes

* **panel:** correct attachable bounding box to include tolerance ([#382](https://github.com/kellerlabs/homeracker/issues/382)) ([a32a248](https://github.com/kellerlabs/homeracker/commit/a32a24897bf324a13da96f4c3fd8b25f7840e541))
* **panel:** remove extra TOLERANCE from panel dimensions ([#381](https://github.com/kellerlabs/homeracker/issues/381)) ([b906ae0](https://github.com/kellerlabs/homeracker/commit/b906ae024114f488722275261eb6ea2ffc33ea21))

### 📦 Dependencies

* update dependency kellerlab-pre-commit-hooks to v0.3.4 ([#379](https://github.com/kellerlabs/homeracker/issues/379)) ([84ac7b1](https://github.com/kellerlabs/homeracker/commit/84ac7b1bec5f34cb91c2038d3760fb73aad1c22a))

## [3.6.0](https://github.com/kellerlabs/homeracker/compare/homeracker-v3.5.0...homeracker-v3.6.0) (2026-05-25)

### ✨ Features

* **keystone:** add parametric keystone jack socket module ([#377](https://github.com/kellerlabs/homeracker/issues/377)) ([7cb2168](https://github.com/kellerlabs/homeracker/commit/7cb2168c5ee94ec7e84bc05c3444b195554b654f))

## [3.5.0](https://github.com/kellerlabs/homeracker/compare/homeracker-v3.4.1...homeracker-v3.5.0) (2026-05-24)

### ✨ Features

* **panel:** add rack panel with configurable bore patterns ([#369](https://github.com/kellerlabs/homeracker/issues/369)) ([ede2d1b](https://github.com/kellerlabs/homeracker/commit/ede2d1bded90d198ddba068b5d778aec020c76d6))

### 📦 Dependencies

* update dependency belfryscad/bosl2 to v2.0.741 ([#373](https://github.com/kellerlabs/homeracker/issues/373)) ([244e188](https://github.com/kellerlabs/homeracker/commit/244e188d653c43a158b5a22923862d1bd39f7958))
* update dependency kellerlab-pre-commit-hooks to v0.3.3 ([#374](https://github.com/kellerlabs/homeracker/issues/374)) ([19d2131](https://github.com/kellerlabs/homeracker/commit/19d21311dfbd4aca735f9ac87a38b794ec56c3f1))

### ♻️ Code Refactoring

* **core:** extract reusable lockpin_hole() module ([4495128](https://github.com/kellerlabs/homeracker/commit/44951289a568ca6f16fdcdeaff097bb27f5e646d))

## [3.4.1](https://github.com/kellerlabs/homeracker/compare/homeracker-v3.4.0...homeracker-v3.4.1) (2026-05-16)

### 📦 Dependencies

* update dependency kellerlab-pre-commit-hooks to v0.3.2 ([#370](https://github.com/kellerlabs/homeracker/issues/370)) ([59a8689](https://github.com/kellerlabs/homeracker/commit/59a868981cca14b0294d8debb0aa4e797293c6ce))

## [3.4.0](https://github.com/kellerlabs/homeracker/compare/homeracker-v3.3.2...homeracker-v3.4.0) (2026-05-10)

### ✨ Features

* **panel:** add parametric panel library ([#368](https://github.com/kellerlabs/homeracker/issues/368)) ([64f3595](https://github.com/kellerlabs/homeracker/commit/64f35958db8446c46a7fafed87f56631a5db61f7))
* **scadm:** add export-png command and decision-records skill ([#366](https://github.com/kellerlabs/homeracker/issues/366)) ([4fac176](https://github.com/kellerlabs/homeracker/commit/4fac17681d01b9cb58f98809fbb37494db55445e))

### 📦 Dependencies

* update dependency belfryscad/bosl2 to v2.0.739 ([#365](https://github.com/kellerlabs/homeracker/issues/365)) ([3505872](https://github.com/kellerlabs/homeracker/commit/35058727417964aa8c7d5badb81fb9c1f036679f))

## [3.3.2](https://github.com/kellerlabs/homeracker/compare/homeracker-v3.3.1...homeracker-v3.3.2) (2026-05-04)

### 📦 Dependencies

* update dependency belfryscad/bosl2 to v2.0.736 ([#360](https://github.com/kellerlabs/homeracker/issues/360)) ([f91a545](https://github.com/kellerlabs/homeracker/commit/f91a5451abfd9a99ad7b6457481451681cf47c4e))
* update dependency kellerlab-pre-commit-hooks to v0.3.1 ([#361](https://github.com/kellerlabs/homeracker/issues/361)) ([150a648](https://github.com/kellerlabs/homeracker/commit/150a6486998503e29a20b62d0a6852b198b69b4e))
* update dependency openscad to v2026.04.26 ([#362](https://github.com/kellerlabs/homeracker/issues/362)) ([716a52e](https://github.com/kellerlabs/homeracker/commit/716a52ee5ef1f171f61dd8de98aa962afb359e5c))
* update pre-commit hook renovatebot/pre-commit-hooks to v43.141.2 ([#358](https://github.com/kellerlabs/homeracker/issues/358)) ([5103bea](https://github.com/kellerlabs/homeracker/commit/5103bea12509e00c0d8b4b4f42c30f54444b7052))

## [3.3.1](https://github.com/kellerlabs/homeracker/compare/homeracker-v3.3.0...homeracker-v3.3.1) (2026-04-25)

### 📦 Dependencies

* update dependency belfryscad/bosl2 to v2.0.735 ([#354](https://github.com/kellerlabs/homeracker/issues/354)) ([23e0c6a](https://github.com/kellerlabs/homeracker/commit/23e0c6a5bcca4525d920a59a6ab5e14eb6daf557))
* update dependency openscad to v2026.04.25 ([#355](https://github.com/kellerlabs/homeracker/issues/355)) ([da986e3](https://github.com/kellerlabs/homeracker/commit/da986e3f1b714a36eac835872fdf120c6ec8ffe3))

## [3.3.0](https://github.com/kellerlabs/homeracker/compare/homeracker-v3.2.0...homeracker-v3.3.0) (2026-04-19)

### ✨ Features

* **agents:** add makerworld-description agent ([#350](https://github.com/kellerlabs/homeracker/issues/350)) ([2fa4850](https://github.com/kellerlabs/homeracker/commit/2fa4850fa5ce07f4a9fa56bcd67321dfacc5ffb5))

### 🐛 Bug Fixes

* **export:** resolve relative links to GitHub URLs in md-to-mw ([#351](https://github.com/kellerlabs/homeracker/issues/351)) ([a44d361](https://github.com/kellerlabs/homeracker/commit/a44d361f260b75dec5f8a117898fb2a82bc3d200))
* **renovate:** revert $match to $contains in JSONata queries ([#345](https://github.com/kellerlabs/homeracker/issues/345)) ([a10a9bd](https://github.com/kellerlabs/homeracker/commit/a10a9bde77e208f202e4e28087bce6f1f172d8f1))

### 📦 Dependencies

* update dependency openscad to v2026.04.16 ([#347](https://github.com/kellerlabs/homeracker/issues/347)) ([411d5ba](https://github.com/kellerlabs/homeracker/commit/411d5ba8788df547104f42c5b4343460af4e0ab2))
* update pre-commit hook renovatebot/pre-commit-hooks to v43.129.0 ([#348](https://github.com/kellerlabs/homeracker/issues/348)) ([aabbce3](https://github.com/kellerlabs/homeracker/commit/aabbce3bf3aa67934b6b659e333439de464579a4))

### 📚 Documentation

* **core:** add foot insert and update changelog in MakerWorld description ([#352](https://github.com/kellerlabs/homeracker/issues/352)) ([467a0db](https://github.com/kellerlabs/homeracker/commit/467a0dbd15c7840c53bac38dd817125b8ae57bd9))
* **core:** slim down MakerWorld description ([#349](https://github.com/kellerlabs/homeracker/issues/349)) ([df5b4a1](https://github.com/kellerlabs/homeracker/commit/df5b4a1fae47fb180cbde11a1a6582ed53726997))

## [3.2.0](https://github.com/kellerlabs/homeracker/compare/homeracker-v3.1.0...homeracker-v3.2.0) (2026-04-18)

### ✨ Features

* **flatten:** resilient parsing, dead-code elimination, section tolerance ([#327](https://github.com/kellerlabs/homeracker/issues/327)) ([3509d66](https://github.com/kellerlabs/homeracker/commit/3509d660beaffba18146d43faa64d78390e17944))
* improve makerworld description tooling ([#341](https://github.com/kellerlabs/homeracker/issues/341)) ([a8417dc](https://github.com/kellerlabs/homeracker/commit/a8417dc527472f5d41252da75abe71db5b576dec))
* migrate images to assets repo, add MakerWorld extract/publish tooling ([#337](https://github.com/kellerlabs/homeracker/issues/337)) ([5d9da76](https://github.com/kellerlabs/homeracker/commit/5d9da76d5f84bbecef7da5db18597922c3c17d41))
* **scadm:** dynamic OpenSCAD version resolution ([#311](https://github.com/kellerlabs/homeracker/issues/311)) ([026c5d8](https://github.com/kellerlabs/homeracker/commit/026c5d85cfbaa599ff6ffc838017f1eb3c8b9942))

### 📦 Dependencies

* update dependency markdown to v3.10.2 ([#340](https://github.com/kellerlabs/homeracker/issues/340)) ([16c73d6](https://github.com/kellerlabs/homeracker/commit/16c73d6ed9afe3c7a9296294368b6d40b9e54860))

### ♻️ Code Refactoring

* **renovate:** centralize custom managers in shared preset ([#344](https://github.com/kellerlabs/homeracker/issues/344)) ([564c218](https://github.com/kellerlabs/homeracker/commit/564c218f65f6d6f01cee34f455dd37c6b8d0a0d1))

## [3.1.0](https://github.com/kellerlabs/homeracker/compare/homeracker-v3.0.0...homeracker-v3.1.0) (2026-04-12)

### ✨ Features

* use shared pre-commit-hooks from kellerlabs/pre-commit-hooks ([#334](https://github.com/kellerlabs/homeracker/issues/334)) ([bb0e23a](https://github.com/kellerlabs/homeracker/commit/bb0e23aa9c0dbbd8dee044f5e8359e1bbd0fcfa0))

### 🐛 Bug Fixes

* guard against empty PR list in automerge ([#335](https://github.com/kellerlabs/homeracker/issues/335)) ([a6343b5](https://github.com/kellerlabs/homeracker/commit/a6343b5fefb96887f2ea06a6f5862e6e3f5658ec))

### 🔄 CI/CD

* **release-please:** exclude sub-packages and workflows from root release ([#331](https://github.com/kellerlabs/homeracker/issues/331)) ([d11275d](https://github.com/kellerlabs/homeracker/commit/d11275d2dce7bd08d651f20d940ac85213c6d651))

## [3.0.0](https://github.com/kellerlabs/homeracker/compare/homeracker-v2.0.1...homeracker-v3.0.0) (2026-04-11)

### ⚠ BREAKING CHANGES

* **setup-openscad:** add scadm-requirements input, remove default version ([#329](https://github.com/kellerlabs/homeracker/issues/329))

### ✨ Features

* **setup-openscad:** add scadm-requirements input, remove default version ([#329](https://github.com/kellerlabs/homeracker/issues/329)) ([85fa9f8](https://github.com/kellerlabs/homeracker/commit/85fa9f8c289be47bfa0d56ec9590606aa8d8fa83))

## [2.0.1](https://github.com/kellerlabs/homeracker/compare/homeracker-v2.0.0...homeracker-v2.0.1) (2026-04-11)

### 🐛 Bug Fixes

* remove Customizer section markers from lib files ([#325](https://github.com/kellerlabs/homeracker/issues/325)) ([1530e6c](https://github.com/kellerlabs/homeracker/commit/1530e6c97ba22f65fdda0eb64904ef7f2f446cad))

### 📦 Dependencies

* update openscad nightly to v2026.04.08 ([#322](https://github.com/kellerlabs/homeracker/issues/322)) ([ab8340f](https://github.com/kellerlabs/homeracker/commit/ab8340f163deb35015fcdcb4d37729e6f60bdbd8))

## [2.0.0](https://github.com/kellerlabs/homeracker/compare/homeracker-v1.12.0...homeracker-v2.0.0) (2026-04-06)

### ⚠ BREAKING CHANGES

* add standalone foot insert, remove is_foot from connector ([#316](https://github.com/kellerlabs/homeracker/issues/316))

### ✨ Features

* add standalone foot insert, remove is_foot from connector ([#316](https://github.com/kellerlabs/homeracker/issues/316)) ([603c6b1](https://github.com/kellerlabs/homeracker/commit/603c6b18a663cf7baab808741c2e523bc6ef14e2))
* **racklink:** add racklink model for connecting rack columns ([#307](https://github.com/kellerlabs/homeracker/issues/307)) ([8d533c9](https://github.com/kellerlabs/homeracker/commit/8d533c96d0348618b26842afbfa256377beb3cf7))
* **sleeve:** extract sleeve into standalone model ([#312](https://github.com/kellerlabs/homeracker/issues/312)) ([9683aa1](https://github.com/kellerlabs/homeracker/commit/9683aa1d9dd876a4ca1a5854ffeb658c9a69ec67))

### 📦 Dependencies

* update dependency belfryscad/bosl2 to v2.0.731 ([#318](https://github.com/kellerlabs/homeracker/issues/318)) ([5ab447e](https://github.com/kellerlabs/homeracker/commit/5ab447e499d61e3afbc156a50a0e2ecb554cecf2))
* update openscad nightly to v2026.04.03 ([#313](https://github.com/kellerlabs/homeracker/issues/313)) ([d3e23fe](https://github.com/kellerlabs/homeracker/commit/d3e23fe663f83f83b1ac922adb1e60f28a608acc))
* update openscad nightly to v2026.04.04 ([#315](https://github.com/kellerlabs/homeracker/issues/315)) ([97d4093](https://github.com/kellerlabs/homeracker/commit/97d40934437f7269ce0f691232bb2230e1a3bd52))
* update pre-commit hook renovatebot/pre-commit-hooks to v43.104.3 ([#317](https://github.com/kellerlabs/homeracker/issues/317)) ([a472bcd](https://github.com/kellerlabs/homeracker/commit/a472bcdeb9b4942ad9aa1eb4ff988695d63eaac6))
* update pre-commit hook renovatebot/pre-commit-hooks to v43.104.4 ([#319](https://github.com/kellerlabs/homeracker/issues/319)) ([da955bb](https://github.com/kellerlabs/homeracker/commit/da955bbb77ce6a7ce6268cc1ddbd68b4cdd99c10))
* update pre-commit hooks ([#314](https://github.com/kellerlabs/homeracker/issues/314)) ([85e92ac](https://github.com/kellerlabs/homeracker/commit/85e92ac2334f9b3f876e21e4be442fe8c7272907))

### 🔄 CI/CD

* **renovate:** reduce update cadence for BOSL2, OpenSCAD nightly, and pre-commit hooks ([#321](https://github.com/kellerlabs/homeracker/issues/321)) ([7869468](https://github.com/kellerlabs/homeracker/commit/7869468117cb4a4098c7a905fd3aee85b06278f8))

## [1.12.0](https://github.com/kellerlabs/homeracker/compare/homeracker-v1.11.0...homeracker-v1.12.0) (2026-03-29)

### ✨ Features

* **inception:** add support bin and support grid with gridfinity bin base improvements ([#295](https://github.com/kellerlabs/homeracker/issues/295)) ([4f81177](https://github.com/kellerlabs/homeracker/commit/4f8117796be9b2a2f1bac3050b8eb1cf4ea43865))

### 📦 Dependencies

* update openscad nightly to v2026.03.28 ([#304](https://github.com/kellerlabs/homeracker/issues/304)) ([ce843da](https://github.com/kellerlabs/homeracker/commit/ce843da3951053badac8de6d6fe63c2154828874))
* update pre-commit hook renovatebot/pre-commit-hooks to v43.96.0 ([#302](https://github.com/kellerlabs/homeracker/issues/302)) ([8fa723d](https://github.com/kellerlabs/homeracker/commit/8fa723d6882cfc65e016aa5ca557bb4006c0fef8))
* update pre-commit hook renovatebot/pre-commit-hooks to v43.98.0 ([#305](https://github.com/kellerlabs/homeracker/issues/305)) ([2e0f5c5](https://github.com/kellerlabs/homeracker/commit/2e0f5c53afa67079b59b928b30465d723f897bdf))
* update pre-commit hook renovatebot/pre-commit-hooks to v43.99.0 ([#306](https://github.com/kellerlabs/homeracker/issues/306)) ([f0ae82d](https://github.com/kellerlabs/homeracker/commit/f0ae82dbbc45d62f41cde0929e55cfebb37236f0))
* update pre-commit hook renovatebot/pre-commit-hooks to v43.99.1 ([#309](https://github.com/kellerlabs/homeracker/issues/309)) ([1672100](https://github.com/kellerlabs/homeracker/commit/1672100b167dc40a446f8f29d446046bd6200fbe))

### 🔧 Miscellaneous

* inception lib fixes & model-polish agent ([#308](https://github.com/kellerlabs/homeracker/issues/308)) ([8a6fdcd](https://github.com/kellerlabs/homeracker/commit/8a6fdcdc64ffe31aa0185467041a4c9ca571a130))
* untrack .flatten-checksums and cache it in CI ([#301](https://github.com/kellerlabs/homeracker/issues/301)) ([c2438c2](https://github.com/kellerlabs/homeracker/commit/c2438c290fd8a5fbfd94b61477226be0ef01e953))

## [1.11.0](https://github.com/kellerlabs/homeracker/compare/homeracker-v1.10.3...homeracker-v1.11.0) (2026-03-23)

### ✨ Features

* **scadm:** add --source and --flattened flags to render command ([#294](https://github.com/kellerlabs/homeracker/issues/294)) ([98a53ed](https://github.com/kellerlabs/homeracker/commit/98a53ed447be7a698d976dd44b41c9ae998fc436))

### 🐛 Bug Fixes

* pinpusher model syntax with invalid trailing comma ([#299](https://github.com/kellerlabs/homeracker/issues/299)) ([fce4046](https://github.com/kellerlabs/homeracker/commit/fce4046f08af0d7e41217c6f3af2c8b4af39d9c0))

### 📦 Dependencies

* update dependency belfryscad/bosl2 to v2.0.730 ([#296](https://github.com/kellerlabs/homeracker/issues/296)) ([024d13d](https://github.com/kellerlabs/homeracker/commit/024d13df835e816c7238d1eec9e154e76103979f))
* update openscad nightly to v2026.03.20 ([#291](https://github.com/kellerlabs/homeracker/issues/291)) ([a42cc01](https://github.com/kellerlabs/homeracker/commit/a42cc01b3b7ccf7b2d8fcb01ae5af95161a6b618))
* update openscad nightly to v2026.03.22 ([#297](https://github.com/kellerlabs/homeracker/issues/297)) ([5901af2](https://github.com/kellerlabs/homeracker/commit/5901af28d0968a7a2b2526f540fb674f6e74ff45))
* update pre-commit hook renovatebot/pre-commit-hooks to v43.84.2 ([#292](https://github.com/kellerlabs/homeracker/issues/292)) ([7ae007a](https://github.com/kellerlabs/homeracker/commit/7ae007a0a8b2361c5a58b98e45f8ed4046e6f543))
* update pre-commit hook renovatebot/pre-commit-hooks to v43.86.0 ([#298](https://github.com/kellerlabs/homeracker/issues/298)) ([51de2ee](https://github.com/kellerlabs/homeracker/commit/51de2ee9fafbd1279d3dcc9002489ef0b3bdb97d))

## [1.10.3](https://github.com/kellerlabs/homeracker/compare/homeracker-v1.10.2...homeracker-v1.10.3) (2026-03-20)

### 🐛 Bug Fixes

* **scadm:** hash flatten.py at fixed position in compute_checksum ([#289](https://github.com/kellerlabs/homeracker/issues/289)) ([a584dc2](https://github.com/kellerlabs/homeracker/commit/a584dc29201019840ca389d2f0420de8b704d136))

## [1.10.2](https://github.com/kellerlabs/homeracker/compare/homeracker-v1.10.1...homeracker-v1.10.2) (2026-03-20)

### 🐛 Bug Fixes

* **scadm:** sort deps by relative path in compute_checksum ([#287](https://github.com/kellerlabs/homeracker/issues/287)) ([b0a6be7](https://github.com/kellerlabs/homeracker/commit/b0a6be7c682728cda729950855bec71ebd473296))

## [1.10.1](https://github.com/kellerlabs/homeracker/compare/homeracker-v1.10.0...homeracker-v1.10.1) (2026-03-20)

### 📚 Documentation

* **scadm:** add flatten file structure conventions ([7d644bc](https://github.com/kellerlabs/homeracker/commit/7d644bc56b84edceb3f758f0746544183ebdbefc))

### 🔧 Miscellaneous

* add sync-instructions release-please package ([e85532b](https://github.com/kellerlabs/homeracker/commit/e85532bf21e697d0140409817533cbb3ed8e7178))
* **sync-instructions:** address PR review feedback ([00f4b4c](https://github.com/kellerlabs/homeracker/commit/00f4b4c1c450cdccdcfe07f07e46165a1efdc0a6))

### ♻️ Code Refactoring

* rename makerworld/ directories to flattened/ ([#284](https://github.com/kellerlabs/homeracker/issues/284)) ([8c937db](https://github.com/kellerlabs/homeracker/commit/8c937db5ace61cc3a0bade19aa258587db86cdff))

## [1.10.0](https://github.com/kellerlabs/homeracker/compare/homeracker-v1.9.1...homeracker-v1.10.0) (2026-03-20)

### ✨ Features

* **export:** add per-model checksum caching for makerworld exports ([#282](https://github.com/kellerlabs/homeracker/issues/282)) ([127ae46](https://github.com/kellerlabs/homeracker/commit/127ae462b1bb7dc85f79dbcc8d892dce4672b29e))
* lockpin pusher tool and PNG export script ([#276](https://github.com/kellerlabs/homeracker/issues/276)) ([825ad85](https://github.com/kellerlabs/homeracker/commit/825ad8541152d7cb15b6b97ac712c27c61702cbe))
* **lockpin:** add foot-side neck extension option ([#280](https://github.com/kellerlabs/homeracker/issues/280)) ([9a239f4](https://github.com/kellerlabs/homeracker/commit/9a239f46c31ebaab139d13e20455e815c9a670cf))
* **scadm:** add flatten and render subcommands ([#283](https://github.com/kellerlabs/homeracker/issues/283)) ([9816c3c](https://github.com/kellerlabs/homeracker/commit/9816c3ccebf0c0a012376dc4158a6c2dcfd70bd3))

### 📦 Dependencies

* update camunda/infra-global-github-actions action to pull-request-1.0.1 ([#279](https://github.com/kellerlabs/homeracker/issues/279)) ([a81c7e4](https://github.com/kellerlabs/homeracker/commit/a81c7e4b4c2b14c5aec68d43b311a82aa727dc51))

### 📚 Documentation

* restructure models and update documentation ([#281](https://github.com/kellerlabs/homeracker/issues/281)) ([f82249e](https://github.com/kellerlabs/homeracker/commit/f82249e18346350cf86865e04046a288759be439))

### 🔄 CI/CD

* **renovate:** switch infra-global-github-actions to semver tags ([#278](https://github.com/kellerlabs/homeracker/issues/278)) ([1b9e9b5](https://github.com/kellerlabs/homeracker/commit/1b9e9b57a92d9b0215a76ce6c4e8b0e1ed327d64))

## [1.9.1](https://github.com/kellerlabs/homeracker/compare/homeracker-v1.9.0...homeracker-v1.9.1) (2026-03-16)

### 📦 Dependencies

* update pre-commit hook renovatebot/pre-commit-hooks to v43.76.2 ([#274](https://github.com/kellerlabs/homeracker/issues/274)) ([86aadda](https://github.com/kellerlabs/homeracker/commit/86aaddaf47cba165fdf8a571eb1e3aaacacc77d3))

## [1.9.0](https://github.com/kellerlabs/homeracker/compare/homeracker-v1.8.0...homeracker-v1.9.0) (2026-03-15)

### ✨ Features

* **setup-openscad:** make action reusable across repositories ([#273](https://github.com/kellerlabs/homeracker/issues/273)) ([055e784](https://github.com/kellerlabs/homeracker/commit/055e78444f59d351e8a943ab7c8ae04d8c34f259))

### 📦 Dependencies

* update pre-commit hook renovatebot/pre-commit-hooks to v43.76.1 ([#270](https://github.com/kellerlabs/homeracker/issues/270)) ([5391857](https://github.com/kellerlabs/homeracker/commit/53918579eecfbca2db0e0040cd7d0ee61f7c9bf0))

## [1.8.0](https://github.com/kellerlabs/homeracker/compare/homeracker-v1.7.8...homeracker-v1.8.0) (2026-03-15)

### ✨ Features

* **ci:** switch BOSL2 to release tags & add SessionStart hook ([#265](https://github.com/kellerlabs/homeracker/issues/265)) ([020cf14](https://github.com/kellerlabs/homeracker/commit/020cf1492aba0c00f9e580a832a9cca949b85f2e))
* **core:** extended lockpin with neck extensions and grip types ([#259](https://github.com/kellerlabs/homeracker/issues/259)) ([4720f98](https://github.com/kellerlabs/homeracker/commit/4720f982537fdbd2fdf97548173c62e1962d124e))

### 🐛 Bug Fixes

* **renovate:** disable prHourlyLimit ([#266](https://github.com/kellerlabs/homeracker/issues/266)) ([3b0894c](https://github.com/kellerlabs/homeracker/commit/3b0894c3e2975422d751f668a413a1339b6ba74e))

### 📦 Dependencies

* update actions/create-github-app-token action to v3 ([#268](https://github.com/kellerlabs/homeracker/issues/268)) ([75d0098](https://github.com/kellerlabs/homeracker/commit/75d009856e314c25cb399ecba3709ae3dccd6711))
* update belfryscad/bosl2 digest to bfc4e74 ([#260](https://github.com/kellerlabs/homeracker/issues/260)) ([a571590](https://github.com/kellerlabs/homeracker/commit/a57159047591fd9f9ad5b9ccbf38e87495bbfa7f))
* update camunda/infra-global-github-actions digest to f5807d2 ([#261](https://github.com/kellerlabs/homeracker/issues/261)) ([612947b](https://github.com/kellerlabs/homeracker/commit/612947b1a3a6a94ca78dc52df4a7797d759a535e))
* update dependency belfryscad/bosl2 to v2.0.727 ([#267](https://github.com/kellerlabs/homeracker/issues/267)) ([8f85820](https://github.com/kellerlabs/homeracker/commit/8f858200162e312e54a5dd470dc1e1594b816d66))
* update openscad nightly to v2026.03.14 ([#263](https://github.com/kellerlabs/homeracker/issues/263)) ([7a0aead](https://github.com/kellerlabs/homeracker/commit/7a0aead7d97c07fee22003efd0268cf83d016726))
* update pre-commit hooks ([#264](https://github.com/kellerlabs/homeracker/issues/264)) ([c55691d](https://github.com/kellerlabs/homeracker/commit/c55691d52b719b2d69238c1b4789813f027046c5))

### 🔄 CI/CD

* cache CI environments & add PR template ([#269](https://github.com/kellerlabs/homeracker/issues/269)) ([ca78385](https://github.com/kellerlabs/homeracker/commit/ca783858fbc69842d064dbb92e608504b11784fc))

## [1.7.8](https://github.com/kellerlabs/homeracker/compare/homeracker-v1.7.7...homeracker-v1.7.8) (2026-03-08)

### 📦 Dependencies

* update belfryscad/bosl2 digest to eadc19a ([#254](https://github.com/kellerlabs/homeracker/issues/254)) ([e4207f3](https://github.com/kellerlabs/homeracker/commit/e4207f3fede8aad80904343cf14d8a9aeefb8ba6))
* update camunda/infra-global-github-actions digest to a6b5d34 ([#256](https://github.com/kellerlabs/homeracker/issues/256)) ([e00f010](https://github.com/kellerlabs/homeracker/commit/e00f010c2ad7504abd5068d0b60bc57442c5b1c9))
* update pre-commit hook renovatebot/pre-commit-hooks to v43.46.6 ([#251](https://github.com/kellerlabs/homeracker/issues/251)) ([109028c](https://github.com/kellerlabs/homeracker/commit/109028c4b16e84e8572b05e301e9967491198815))
* update pre-commit hook renovatebot/pre-commit-hooks to v43.59.3 ([#257](https://github.com/kellerlabs/homeracker/issues/257)) ([9c3abe7](https://github.com/kellerlabs/homeracker/commit/9c3abe7d847d818ac69e6cdc88f779582ddeea7f))
* update pre-commit hooks ([#255](https://github.com/kellerlabs/homeracker/issues/255)) ([3c65f00](https://github.com/kellerlabs/homeracker/commit/3c65f008f88d7e4019d21f81b5532c17b8f92484))

### 📚 Documentation

* link homeracker-community repo in README and CONTRIBUTING ([#258](https://github.com/kellerlabs/homeracker/issues/258)) ([0f3df06](https://github.com/kellerlabs/homeracker/commit/0f3df067a4aa9d8286c6bf9b6296154ba8353857))

## [1.7.7](https://github.com/kellerlabs/homeracker/compare/homeracker-v1.7.6...homeracker-v1.7.7) (2026-03-01)

### 📦 Dependencies

* update actions/upload-artifact action to v7 ([#250](https://github.com/kellerlabs/homeracker/issues/250)) ([4508c92](https://github.com/kellerlabs/homeracker/commit/4508c92469ef3ab88d75c6340223211a43329ce4))
* update belfryscad/bosl2 digest to 83fbdf2 ([#245](https://github.com/kellerlabs/homeracker/issues/245)) ([b6573e3](https://github.com/kellerlabs/homeracker/commit/b6573e331078ff0072b1747ef3bc51e1c3dc766b))
* update camunda/infra-global-github-actions digest to ddce993 ([#246](https://github.com/kellerlabs/homeracker/issues/246)) ([b06b8da](https://github.com/kellerlabs/homeracker/commit/b06b8da0baa92972f0b74f803bab64147bd7d82d))
* update openscad nightly to v2026.02.25 ([#247](https://github.com/kellerlabs/homeracker/issues/247)) ([46b50a7](https://github.com/kellerlabs/homeracker/commit/46b50a7c8c979c708965bc8ed6641b279ced12b9))
* update openscad nightly to v2026.03.01 ([#252](https://github.com/kellerlabs/homeracker/issues/252)) ([d6f44de](https://github.com/kellerlabs/homeracker/commit/d6f44dee43bec06a9cea88ba1de920c0330f9898))
* update pre-commit hook renovatebot/pre-commit-hooks to v43.46.2 ([#248](https://github.com/kellerlabs/homeracker/issues/248)) ([598fd1a](https://github.com/kellerlabs/homeracker/commit/598fd1aed871ca72ab8459fde982f9b4b481efb7))

## [1.7.6](https://github.com/kellerlabs/homeracker/compare/homeracker-v1.7.5...homeracker-v1.7.6) (2026-02-22)

### 📦 Dependencies

* update belfryscad/bosl2 digest to 095725b ([#238](https://github.com/kellerlabs/homeracker/issues/238)) ([a10ad06](https://github.com/kellerlabs/homeracker/commit/a10ad062aa1466d74402ba7457b6c64ef2a653c0))
* update belfryscad/bosl2 digest to d028c09 ([#243](https://github.com/kellerlabs/homeracker/issues/243)) ([da91ae3](https://github.com/kellerlabs/homeracker/commit/da91ae3d19d7b8cf574cea05dea7c3ab11d5ad47))
* update camunda/infra-global-github-actions digest to 6501ba0 ([#239](https://github.com/kellerlabs/homeracker/issues/239)) ([cd6ff7b](https://github.com/kellerlabs/homeracker/commit/cd6ff7b2c0fd13b5696a6b804366243f5900b95b))
* update openscad nightly to v2026.02.19 ([#240](https://github.com/kellerlabs/homeracker/issues/240)) ([b76725c](https://github.com/kellerlabs/homeracker/commit/b76725cc52963825bb224d3bd37564247fdee0a9))
* update pre-commit hooks ([#241](https://github.com/kellerlabs/homeracker/issues/241)) ([1b1f52f](https://github.com/kellerlabs/homeracker/commit/1b1f52fbd9d2c1a492f1121ae3da07c03c6b7d6c))

## [1.7.5](https://github.com/kellerlabs/homeracker/compare/homeracker-v1.7.4...homeracker-v1.7.5) (2026-02-15)

### 📦 Dependencies

* update belfryscad/bosl2 digest to 77004eb ([#231](https://github.com/kellerlabs/homeracker/issues/231)) ([8710278](https://github.com/kellerlabs/homeracker/commit/8710278f08e9620f93e38dc08d59d4454181b50a))
* update belfryscad/bosl2 digest to b4f7ce8 ([#235](https://github.com/kellerlabs/homeracker/issues/235)) ([334ebcf](https://github.com/kellerlabs/homeracker/commit/334ebcfbfdab56d30f978dac687eb59851716f0b))
* update camunda/infra-global-github-actions digest to 0d5665c ([#229](https://github.com/kellerlabs/homeracker/issues/229)) ([bda7862](https://github.com/kellerlabs/homeracker/commit/bda78629736b219122fdc7cadca84ffc733c19fd))
* update camunda/infra-global-github-actions digest to a969eec ([#234](https://github.com/kellerlabs/homeracker/issues/234)) ([19436e6](https://github.com/kellerlabs/homeracker/commit/19436e678d93e3ba3471f15c6a3bb4f54daec1d7))
* update openscad nightly to v2026.02.09 ([#227](https://github.com/kellerlabs/homeracker/issues/227)) ([6d292d3](https://github.com/kellerlabs/homeracker/commit/6d292d358b9dd8aa61e210a0c7782afb73ac8d85))
* update openscad nightly to v2026.02.13 ([#230](https://github.com/kellerlabs/homeracker/issues/230)) ([6a23b48](https://github.com/kellerlabs/homeracker/commit/6a23b48f7047add55401295135ebac7e88324810))
* update openscad nightly to v2026.02.15 ([#236](https://github.com/kellerlabs/homeracker/issues/236)) ([fd4f1db](https://github.com/kellerlabs/homeracker/commit/fd4f1db6a5961ce4939474e894588cf806bb5bad))
* update pre-commit hook renovatebot/pre-commit-hooks to v43.15.0 ([#233](https://github.com/kellerlabs/homeracker/issues/233)) ([1080ab9](https://github.com/kellerlabs/homeracker/commit/1080ab913d92774c285fb8d3ebb0ea5de17f5148))
* update pre-commit hook renovatebot/pre-commit-hooks to v43.15.1 ([#237](https://github.com/kellerlabs/homeracker/issues/237)) ([339c486](https://github.com/kellerlabs/homeracker/commit/339c486f4694487f05ae40902c4618e2c63f2690))
* update pre-commit hooks ([#232](https://github.com/kellerlabs/homeracker/issues/232)) ([8245686](https://github.com/kellerlabs/homeracker/commit/8245686a311df29da9adacdb6d8c546318f389d9))

## [1.7.4](https://github.com/kellerlabs/homeracker/compare/homeracker-v1.7.3...homeracker-v1.7.4) (2026-02-09)

### 🐛 Bug Fixes

* **renovate:** homeracker preset ([48dcc53](https://github.com/kellerlabs/homeracker/commit/48dcc53ef094a57807e42855f9375ece929ef4e2))
* **renovate:** homeracker preset version extraction ([bb4b63f](https://github.com/kellerlabs/homeracker/commit/bb4b63feb385d7b4c94846804fa6e61acb91ec6d))

### 📦 Dependencies

* update belfryscad/bosl2 digest to 0e03331 ([#220](https://github.com/kellerlabs/homeracker/issues/220)) ([9a04573](https://github.com/kellerlabs/homeracker/commit/9a04573eb270bcb53ec31c1b102118fe5181b67c))
* update belfryscad/bosl2 digest to 68bae2d ([#225](https://github.com/kellerlabs/homeracker/issues/225)) ([9b4c73f](https://github.com/kellerlabs/homeracker/commit/9b4c73f7ea33a3c22169a3c12bda5f68cdf483e6))
* update camunda/infra-global-github-actions digest to 317ad65 ([#221](https://github.com/kellerlabs/homeracker/issues/221)) ([ea830d0](https://github.com/kellerlabs/homeracker/commit/ea830d064bef76b2ef9963606f416debe03c7f6e))
* update dependency openscad-windows to v2026.02.07 ([#222](https://github.com/kellerlabs/homeracker/issues/222)) ([94928af](https://github.com/kellerlabs/homeracker/commit/94928af85cb9445bd6702427f8f48b75518020f6))
* update pre-commit hook renovatebot/pre-commit-hooks to v43.4.2 ([#224](https://github.com/kellerlabs/homeracker/issues/224)) ([530b816](https://github.com/kellerlabs/homeracker/commit/530b81698c49051c43f9fbd1caafa397580f07fa))
* update pre-commit hook renovatebot/pre-commit-hooks to v43.4.3 ([#226](https://github.com/kellerlabs/homeracker/issues/226)) ([bb3bd14](https://github.com/kellerlabs/homeracker/commit/bb3bd14752a7e2cf496e44b36b0db9063d9d8c56))

### 📚 Documentation

* **scadm:** fix homeracker version ref ([6c68b2e](https://github.com/kellerlabs/homeracker/commit/6c68b2e145030411f728ec6c29f39ae21efa40e1))

## [1.7.3](https://github.com/kellerlabs/homeracker/compare/homeracker-v1.7.2...homeracker-v1.7.3) (2026-02-02)

### 📦 Dependencies

* update belfryscad/bosl2 digest to ffa493b ([#212](https://github.com/kellerlabs/homeracker/issues/212)) ([3bedd5e](https://github.com/kellerlabs/homeracker/commit/3bedd5e635cb209c7704c950eb851e153834d374))
* update camunda/infra-global-github-actions digest to df04776 ([#213](https://github.com/kellerlabs/homeracker/issues/213)) ([13723ba](https://github.com/kellerlabs/homeracker/commit/13723ba093747897e55626fb07658e4d96f3a7f4))
* update dependency openscad-windows to v2026.01.29 ([#214](https://github.com/kellerlabs/homeracker/issues/214)) ([7e49ff6](https://github.com/kellerlabs/homeracker/commit/7e49ff6f389a475173113a0e31480dea2af42810))
* update dependency openscad-windows to v2026.02.01 ([#218](https://github.com/kellerlabs/homeracker/issues/218)) ([8a04981](https://github.com/kellerlabs/homeracker/commit/8a0498182cdd044d4c0e74e36677f1ba928faceb))
* update pre-commit hook renovatebot/pre-commit-hooks to v43 ([#215](https://github.com/kellerlabs/homeracker/issues/215)) ([937c1f8](https://github.com/kellerlabs/homeracker/commit/937c1f877257558350023461f63aac4cd18f6b48))
* update pre-commit hook renovatebot/pre-commit-hooks to v43.0.8 ([#217](https://github.com/kellerlabs/homeracker/issues/217)) ([a8a75c1](https://github.com/kellerlabs/homeracker/commit/a8a75c15e9560ab148bf2cc3946b8bdbb9977719))
* update pre-commit hook renovatebot/pre-commit-hooks to v43.0.9 ([#219](https://github.com/kellerlabs/homeracker/issues/219)) ([f8d1ed3](https://github.com/kellerlabs/homeracker/commit/f8d1ed3ede568a06ddc0c4cdef7554bbe8635667))

## [1.7.2](https://github.com/kellerlabs/homeracker/compare/homeracker-v1.7.1...homeracker-v1.7.2) (2026-01-25)

### 📦 Dependencies

* update belfryscad/bosl2 digest to a9f31f0 ([#208](https://github.com/kellerlabs/homeracker/issues/208)) ([5d20a0e](https://github.com/kellerlabs/homeracker/commit/5d20a0ec795063ec73040c2f65c8d6971b908429))
* update camunda/infra-global-github-actions digest to 8a60c6a ([#209](https://github.com/kellerlabs/homeracker/issues/209)) ([76887ec](https://github.com/kellerlabs/homeracker/commit/76887ec5bdae866c5c393db2bbcf7385a1faf9c1))
* update dependency openscad-windows to v2026.01.19 ([#210](https://github.com/kellerlabs/homeracker/issues/210)) ([c57df5a](https://github.com/kellerlabs/homeracker/commit/c57df5adcf7967cf6e21b5fa8d622673bd7fc38e))
* update dependency openscad-windows to v2026.01.25 ([#211](https://github.com/kellerlabs/homeracker/issues/211)) ([e4f6407](https://github.com/kellerlabs/homeracker/commit/e4f640767a17eba1c7e8dd5efc208515cc1b47cf))

## [1.7.1](https://github.com/kellerlabs/homeracker/compare/homeracker-v1.7.0...homeracker-v1.7.1) (2026-01-18)

### 📦 Dependencies

* update belfryscad/bosl2 digest to 7e5dfe5 ([#200](https://github.com/kellerlabs/homeracker/issues/200)) ([af1350a](https://github.com/kellerlabs/homeracker/commit/af1350a3c92eb5295277bcc289a6d576c6c32162))
* update camunda/infra-global-github-actions digest to 5f8949d ([#201](https://github.com/kellerlabs/homeracker/issues/201)) ([dd027f1](https://github.com/kellerlabs/homeracker/commit/dd027f163ee5e57d0eaa9fdc0a89c3b3df54135c))
* update dependency openscad-windows to v2026.01.18 ([#202](https://github.com/kellerlabs/homeracker/issues/202)) ([b7098c9](https://github.com/kellerlabs/homeracker/commit/b7098c985831d87701509cb4d5e29b9e9f194405))
* update pre-commit hooks ([#203](https://github.com/kellerlabs/homeracker/issues/203)) ([bfe0047](https://github.com/kellerlabs/homeracker/commit/bfe0047ae5cb97f137079cc69df0720118971be5))

### ♻️ Code Refactoring

* update repository references from kellervater to kellerlabs ([#198](https://github.com/kellerlabs/homeracker/issues/198)) ([8e5717b](https://github.com/kellerlabs/homeracker/commit/8e5717bf0ee1b8b2e06d247fccb83eced79f06ee))

## [1.7.0](https://github.com/kellervater/homeracker/compare/homeracker-v1.6.0...homeracker-v1.7.0) (2026-01-12)

### ✨ Features

* **gridfinity:** baseplate & binbase modules ([#187](https://github.com/kellervater/homeracker/issues/187)) ([827c041](https://github.com/kellervater/homeracker/commit/827c041989116eb15a5eed1e6ee8c0365037b0f3))

### 📦 Dependencies

* update belfryscad/bosl2 digest to ed3afe3 ([#188](https://github.com/kellervater/homeracker/issues/188)) ([ab4c7c7](https://github.com/kellervater/homeracker/commit/ab4c7c71ebacf24a18737acfdc579bdc5ae1a4db))
* update camunda/infra-global-github-actions digest to a708558 ([#189](https://github.com/kellervater/homeracker/issues/189)) ([b674105](https://github.com/kellervater/homeracker/commit/b6741058e993a9339e55cd43f1b3b15fea641f53))
* update pre-commit hook renovatebot/pre-commit-hooks to v42.76.4 ([#190](https://github.com/kellervater/homeracker/issues/190)) ([8417370](https://github.com/kellervater/homeracker/commit/8417370c3f9a8645f475bd4ae8bbff5bb15ffe26))
* update pre-commit hook renovatebot/pre-commit-hooks to v42.76.5 ([#192](https://github.com/kellervater/homeracker/issues/192)) ([859dfd6](https://github.com/kellervater/homeracker/commit/859dfd62cfa6b475130568274b051cbf55157aa7))
* update pre-commit hook renovatebot/pre-commit-hooks to v42.78.0 ([#193](https://github.com/kellervater/homeracker/issues/193)) ([92db61f](https://github.com/kellervater/homeracker/commit/92db61f778b6ac51ca16ca33321850b6718fa1fe))
* update pre-commit hook renovatebot/pre-commit-hooks to v42.78.1 ([#194](https://github.com/kellervater/homeracker/issues/194)) ([a217589](https://github.com/kellervater/homeracker/commit/a2175890a86c2bf8d3e12063cfb2eb96f1cbf9f7))

## [1.6.0](https://github.com/kellervater/homeracker/compare/homeracker-v1.5.2...homeracker-v1.6.0) (2026-01-04)

### ✨ Features

* **core:** add extended grip type ([#173](https://github.com/kellervater/homeracker/issues/173)) ([7e4b27a](https://github.com/kellervater/homeracker/commit/7e4b27a5ea451d1894c634b91379e17961355494))

### 📦 Dependencies

* update camunda/infra-global-github-actions digest to 084e5ba ([#184](https://github.com/kellervater/homeracker/issues/184)) ([0be0d09](https://github.com/kellervater/homeracker/commit/0be0d090b3cb1859dadf3ea482bbb1ee859e8814))
* update camunda/infra-global-github-actions digest to 309fedf ([#180](https://github.com/kellervater/homeracker/issues/180)) ([e627303](https://github.com/kellervater/homeracker/commit/e62730314923241746caf83dc3cb863c6208d9d3))
* update dependency openscad-windows to v2026.01.03 ([#186](https://github.com/kellervater/homeracker/issues/186)) ([fce4a5a](https://github.com/kellervater/homeracker/commit/fce4a5ae4af4324405e63a119a5204fa941819ac))
* update openscad nightly to v2026 ([#182](https://github.com/kellervater/homeracker/issues/182)) ([45efd5c](https://github.com/kellervater/homeracker/commit/45efd5c58e53859d94c5af7bfe08a8f8bc75003e))
* update pre-commit hook renovatebot/pre-commit-hooks to v42.70.3 ([#183](https://github.com/kellervater/homeracker/issues/183)) ([b391b09](https://github.com/kellervater/homeracker/commit/b391b09e8792cac893337f6f35e169d134289505))
* update pre-commit hook renovatebot/pre-commit-hooks to v42.71.0 ([#185](https://github.com/kellervater/homeracker/issues/185)) ([bf326b5](https://github.com/kellervater/homeracker/commit/bf326b5ad0e5e350d9ea24d9fe13f0ac2709569c))
* update pre-commit hooks ([#181](https://github.com/kellervater/homeracker/issues/181)) ([4748876](https://github.com/kellervater/homeracker/commit/4748876a19e5ff0437b95e4f909528d67167b7d6))

### 📚 Documentation

* add Community section to README ([#175](https://github.com/kellervater/homeracker/issues/175)) ([71dbee8](https://github.com/kellervater/homeracker/commit/71dbee8386a1766a161bf7d299dba8ba229d6cd9))
* pre-commit.dev -&gt; pre-commit.com fixes ([#179](https://github.com/kellervater/homeracker/issues/179)) ([3e61b1a](https://github.com/kellervater/homeracker/commit/3e61b1aa1029c709d934c08362df6e550f75ffc7))
* updated CONTRIBUTING.md minor inaccuracies ([#178](https://github.com/kellervater/homeracker/issues/178)) ([a45cc3c](https://github.com/kellervater/homeracker/commit/a45cc3c98a2ce2346f5c96cf05779217950214c2))

## [1.5.2](https://github.com/kellervater/homeracker/compare/homeracker-v1.5.1...homeracker-v1.5.2) (2025-12-28)

### 📦 Dependencies

* update belfryscad/bosl2 digest to 79d836c ([#169](https://github.com/kellervater/homeracker/issues/169)) ([5e75f46](https://github.com/kellervater/homeracker/commit/5e75f46fc0196b617b909f34e0488b0e243342df))
* update camunda/infra-global-github-actions digest to ac7a12d ([#164](https://github.com/kellervater/homeracker/issues/164)) ([60a1514](https://github.com/kellervater/homeracker/commit/60a15146ce7128833b954479e224da9b5e7ec3d7))
* update openscad nightly ([#165](https://github.com/kellervater/homeracker/issues/165)) ([7f8746c](https://github.com/kellervater/homeracker/commit/7f8746c1c923934d4e4eec0a87b140849aa55919))
* update openscad nightly ([#168](https://github.com/kellervater/homeracker/issues/168)) ([fe441bd](https://github.com/kellervater/homeracker/commit/fe441bd91f4019676d52981e70cb88ca8a09ca56))
* update openscad nightly ([#171](https://github.com/kellervater/homeracker/issues/171)) ([fccf876](https://github.com/kellervater/homeracker/commit/fccf87602d08aef6c9aa0ea41d6ad1353ca9eb93))
* update pre-commit hook renovatebot/pre-commit-hooks to v42.66.11 ([#172](https://github.com/kellervater/homeracker/issues/172)) ([cf56f84](https://github.com/kellervater/homeracker/commit/cf56f84f44ed5b869e46a79fd9df819897ef7f4c))
* update pre-commit hook renovatebot/pre-commit-hooks to v42.66.8 ([#166](https://github.com/kellervater/homeracker/issues/166)) ([56a2669](https://github.com/kellervater/homeracker/commit/56a2669e909af0afd5d43c3c8237c72479b3e366))
* update pre-commit hook renovatebot/pre-commit-hooks to v42.66.9 ([#170](https://github.com/kellervater/homeracker/issues/170)) ([296d234](https://github.com/kellervater/homeracker/commit/296d234d0501d412dae093af7f041ad76728975d))

## [1.5.1](https://github.com/kellervater/homeracker/compare/homeracker-v1.5.0...homeracker-v1.5.1) (2025-12-20)

### 📦 Dependencies

* update belfryscad/bosl2 digest to 9312b5b ([#158](https://github.com/kellervater/homeracker/issues/158)) ([f123eea](https://github.com/kellervater/homeracker/commit/f123eea015c66f17e413a94abb9d87dcbf6291dd))
* update camunda/infra-global-github-actions digest to 4b7639e ([#159](https://github.com/kellervater/homeracker/issues/159)) ([2a759cd](https://github.com/kellervater/homeracker/commit/2a759cd557f3c12817ea2cdcb41e9d890c3ebf93))
* update openscad nightly ([#161](https://github.com/kellervater/homeracker/issues/161)) ([c22aa62](https://github.com/kellervater/homeracker/commit/c22aa62536b6664a6aa112ac5424bc39b5593163))
* update pre-commit hook renovatebot/pre-commit-hooks to v42.64.1 ([#162](https://github.com/kellervater/homeracker/issues/162)) ([b26dfda](https://github.com/kellervater/homeracker/commit/b26dfda6ac6974b0426f7ef77522dd384e287f79))

### 📚 Documentation

* **fix:** conventional commits bump ([62b319b](https://github.com/kellervater/homeracker/commit/62b319bc7870d9c2f8cfe9b0ef14e46ed4c1020f))

## [1.5.0](https://github.com/kellervater/homeracker/compare/homeracker-v1.4.0...homeracker-v1.5.0) (2025-12-15)

### ✨ Features

* **img:** added HomeRacker Logo svgs ([4f264a9](https://github.com/kellervater/homeracker/commit/4f264a9f3896206b0cd6e1778304710921764948))
* **scadm:** add --version flag ([#140](https://github.com/kellervater/homeracker/issues/140)) ([5a7d98c](https://github.com/kellervater/homeracker/commit/5a7d98cfd33c36f9d6e1df95181c42c5c6195b2f))

### 🐛 Bug Fixes

* **core:** improve print orientation for bed slingers. ([#144](https://github.com/kellervater/homeracker/issues/144)) ([e2177c9](https://github.com/kellervater/homeracker/commit/e2177c9099224fcdb8dd55217180ecae1813d06e))
* **renovate:** add custom manager for homeracker-vX.Y.Z tags in scadm.json ([#155](https://github.com/kellervater/homeracker/issues/155)) ([8155b0f](https://github.com/kellervater/homeracker/commit/8155b0fc4052376a1fc71080075968b74883be8c))

### 📦 Dependencies

* update actions/upload-artifact action to v6 ([#150](https://github.com/kellervater/homeracker/issues/150)) ([96584a7](https://github.com/kellervater/homeracker/commit/96584a7d4334131d5976ff8568da9e49635ae40e))
* update belfryscad/bosl2 digest to 7c6b1da ([#151](https://github.com/kellervater/homeracker/issues/151)) ([13ea9ad](https://github.com/kellervater/homeracker/commit/13ea9ad77a6fbc5ec30240231bc05a96f26bec19))
* update belfryscad/bosl2 digest to 961ed6d ([#146](https://github.com/kellervater/homeracker/issues/146)) ([c0687da](https://github.com/kellervater/homeracker/commit/c0687da15d64b59bedc0d07cca2a9727f009c6ed))
* update camunda/infra-global-github-actions digest to 1f5a9ae ([#147](https://github.com/kellervater/homeracker/issues/147)) ([0fcea2e](https://github.com/kellervater/homeracker/commit/0fcea2e0c2d97c69cb2695ad4a26862cdcebd86e))
* update camunda/infra-global-github-actions digest to 39cfd35 ([#153](https://github.com/kellervater/homeracker/issues/153)) ([2c32c2a](https://github.com/kellervater/homeracker/commit/2c32c2adf3f13127df96846ebfd52edbf22f021e))
* update openscad nightly ([#148](https://github.com/kellervater/homeracker/issues/148)) ([29756dd](https://github.com/kellervater/homeracker/commit/29756ddfd902c61add8094f56d17e8b709789eda))
* update pre-commit hook renovatebot/pre-commit-hooks to v42.52.2 ([#149](https://github.com/kellervater/homeracker/issues/149)) ([2e860d9](https://github.com/kellervater/homeracker/commit/2e860d95f4f9ea19556a13d06e45731d77c8f3d9))
* update pre-commit hook renovatebot/pre-commit-hooks to v42.52.6 ([#152](https://github.com/kellervater/homeracker/issues/152)) ([4865ab4](https://github.com/kellervater/homeracker/commit/4865ab4d94a00480748720f689d76bc6f3a9d1cb))
* update pre-commit hook renovatebot/pre-commit-hooks to v42.52.8 ([#156](https://github.com/kellervater/homeracker/issues/156)) ([8fbe3af](https://github.com/kellervater/homeracker/commit/8fbe3af2ec4b697a1016c874ea95805b317ad54a))

### 📚 Documentation

* **img:** svg logo links ([3ddbd86](https://github.com/kellervater/homeracker/commit/3ddbd86a0823531e71b7642893b88962b2d80bdb))

## [1.4.0](https://github.com/kellervater/homeracker/compare/homeracker-v1.3.1...homeracker-v1.4.0) (2025-12-08)

### ✨ Features

* **scadm:** add Python extension support to vscode command ([#133](https://github.com/kellervater/homeracker/issues/133)) ([0bee683](https://github.com/kellervater/homeracker/commit/0bee683232593428290fe116fd7af9ce2c732816))
* **scadm:** add vscode command for extension management ([#131](https://github.com/kellervater/homeracker/issues/131)) ([573c9dd](https://github.com/kellervater/homeracker/commit/573c9ddbbe420c0bd4f1631e240a54e9bac5d5d3))

### 📦 Dependencies

* update pre-commit hooks ([#134](https://github.com/kellervater/homeracker/issues/134)) ([e18d974](https://github.com/kellervater/homeracker/commit/e18d9743e5ca4f4ebfc14039208648d71195361a))

## [1.3.1](https://github.com/kellervater/homeracker/compare/homeracker-v1.3.0...homeracker-v1.3.1) (2025-12-07)

### 📦 Dependencies

* update belfryscad/bosl2 digest to b47d5eb ([#122](https://github.com/kellervater/homeracker/issues/122)) ([6d63741](https://github.com/kellervater/homeracker/commit/6d637414d855b4aff31c760fb5627feb256111d4))
* update dependency python to 3.14 ([#128](https://github.com/kellervater/homeracker/issues/128)) ([a26eace](https://github.com/kellervater/homeracker/commit/a26eace0949c2188bedcacb7bf1beb8793160e12))
* update github actions to v6 (major) ([#129](https://github.com/kellervater/homeracker/issues/129)) ([0462e90](https://github.com/kellervater/homeracker/commit/0462e90ad284e5c138e7acf234ffa9f5f605f470))
* update openscad nightly ([#124](https://github.com/kellervater/homeracker/issues/124)) ([b12fc92](https://github.com/kellervater/homeracker/commit/b12fc92673c85ecd519e5875aed2c68d55a3a2ad))

### 🔄 CI/CD

* **renovate:** group GHA prs ([9824210](https://github.com/kellervater/homeracker/commit/9824210fcd2746ef4c4a186e024ff130591725db))

### ♻️ Code Refactoring

* uppercase all constants with backward compatibility ([#130](https://github.com/kellervater/homeracker/issues/130)) ([9076d73](https://github.com/kellervater/homeracker/commit/9076d7303361758cdb3b575f80d578212dcccdda))

## [1.3.0](https://github.com/kellervater/homeracker/compare/homeracker-v1.2.0...homeracker-v1.3.0) (2025-12-07)

### ✨ Features

* add overlay logo ([3a7f1eb](https://github.com/kellervater/homeracker/commit/3a7f1ebb1b8021bae5df22993788e84048828501))
* add ruby & intentionally downgrade versions ([9fe7a61](https://github.com/kellervater/homeracker/commit/9fe7a614172d33807ef0971de4f9d8fdc9d4f5f2))
* added license ([f022f04](https://github.com/kellervater/homeracker/commit/f022f047a8f26d04f4f4ff772501f41631d5040d))
* asdf installation ([2b9e906](https://github.com/kellervater/homeracker/commit/2b9e906e72e55ded040e7ba683f0f8dca2a4183c))
* bunch of raw data ([7b4590c](https://github.com/kellervater/homeracker/commit/7b4590c2de6d188a7fb4a3c5e9acf51fd706d44f))
* **ci:** add CI workflow to validate OpenSCAD model rendering ([#48](https://github.com/kellervater/homeracker/issues/48)) ([030e5ca](https://github.com/kellervater/homeracker/commit/030e5ca20ddf464dca76964dd9a082dcf9eac60e))
* **copilot:** added 1st instruction draft ([d9eac22](https://github.com/kellervater/homeracker/commit/d9eac222e419163c7d192041336d1bdf5033aa0c))
* core export script ([27213d9](https://github.com/kellervater/homeracker/commit/27213d9d50b7af9723158aff833b2ee3181a218e))
* **core:** added more pull-through feet ([#85](https://github.com/kellervater/homeracker/issues/85)) ([d4461c4](https://github.com/kellervater/homeracker/commit/d4461c4f6841d9316901127a4e21240775c7493b))
* **core:** provide HomeRacker core as OpenSCAD library ([#32](https://github.com/kellervater/homeracker/issues/32)) ([a50e774](https://github.com/kellervater/homeracker/commit/a50e774507f9102238b0d63465a5388bbf876149))
* favicon ([e91dffa](https://github.com/kellervater/homeracker/commit/e91dffa6cc961de2977d045494f1ce6477faed0a))
* flexmount bracket ([98e19ef](https://github.com/kellervater/homeracker/commit/98e19efa60837c36e77f0a96e2a7099e3447ec06))
* gridfinity baseplate ([4c7c8f2](https://github.com/kellervater/homeracker/commit/4c7c8f2dc3b2ea4e46e975c161c5cbda4e3c0698))
* implement automated releases with Camunda GitHub actions ([#49](https://github.com/kellervater/homeracker/issues/49)) ([62691cb](https://github.com/kellervater/homeracker/commit/62691cb3bbf69b4f0de370c3fbd6fbd1b0859674))
* implement custom dependency manager and renovate preset ([#106](https://github.com/kellervater/homeracker/issues/106)) ([96393d1](https://github.com/kellervater/homeracker/commit/96393d1e91c657abbbfc03465e0c089080300346))
* jpg to png to svg ([099b754](https://github.com/kellervater/homeracker/commit/099b754156948867b8e0ea572d85e2b45482394e))
* **rackmount_ears:** asymetry slider ([#13](https://github.com/kellervater/homeracker/issues/13)) ([ebeb258](https://github.com/kellervater/homeracker/commit/ebeb258d60adb0c36ee70117b69d417d8d49e0e4))
* **rackmount_ears:** option to show actual ear distance ([beb5f39](https://github.com/kellervater/homeracker/commit/beb5f39722bc5680f79e917926e8de0b1e80e40d))
* **rackmount-ears:** initial commit ([482484c](https://github.com/kellervater/homeracker/commit/482484cb8316df7ecc114230172e613bbe0bd46e))
* scad installer ([#41](https://github.com/kellervater/homeracker/issues/41)) ([688d7a3](https://github.com/kellervater/homeracker/commit/688d7a3535459f923bc4d0471bade288b184d1d1))
* set theme ([d80e7ee](https://github.com/kellervater/homeracker/commit/d80e7ee17e425d45652ccebd67f3e2bf997169a2))
* **shelf:** python exporter ([a5bad40](https://github.com/kellervater/homeracker/commit/a5bad400827f257ce0c43e125242ff8274f4074b))
* wallmount ([#14](https://github.com/kellervater/homeracker/issues/14)) ([a1c8d11](https://github.com/kellervater/homeracker/commit/a1c8d11b6afb284a4d9c5a9db20a4ae25d2b3b18))

### 🐛 Bug Fixes

* **ci:** release please config ([#55](https://github.com/kellervater/homeracker/issues/55)) ([9c95988](https://github.com/kellervater/homeracker/commit/9c9598895b12ca43cc1b1610b7ca83af67040708))
* emojis ([35f0caa](https://github.com/kellervater/homeracker/commit/35f0caa9d1c8654bf940bb42eefeaca432976d93))
* favicon ([91a43c8](https://github.com/kellervater/homeracker/commit/91a43c8259ecb59a6d87839654a0f5d72916a3ed))
* logo details ([34cd659](https://github.com/kellervater/homeracker/commit/34cd65917727176b8c6228104c2c1941341a05a1))
* logo transparency ([bc80d1e](https://github.com/kellervater/homeracker/commit/bc80d1e65f0a208370250984faaf87915f97c45f))
* makerworld link ([c4bc57d](https://github.com/kellervater/homeracker/commit/c4bc57de6d306e34419b8ad39d661ec4cebbcf68))
* move release-please config files to .github/config ([#53](https://github.com/kellervater/homeracker/issues/53)) ([5a423bc](https://github.com/kellervater/homeracker/commit/5a423bc23380d0bffe726a24429819f817186d52))
* path for openscad-render.sh ([#108](https://github.com/kellervater/homeracker/issues/108)) ([aea790c](https://github.com/kellervater/homeracker/commit/aea790ca856dfee800c1368a178959c7a3900f26))
* **rackmountears:** sane defaults ([a1a6777](https://github.com/kellervater/homeracker/commit/a1a6777aea8052ad672fe6c37afcb5b9a0a13646))
* **renovate:** openSCAD nightly versions ([#60](https://github.com/kellervater/homeracker/issues/60)) ([5e4e70d](https://github.com/kellervater/homeracker/commit/5e4e70d91e7e57b964c8d32627b85fdfee2a5708))
* **renovate:** preserve .ai suffix for Linux OpenSCAD versions ([#63](https://github.com/kellervater/homeracker/issues/63)) ([a391cd3](https://github.com/kellervater/homeracker/commit/a391cd3bb30043bc8b1c39a97b9f6facc43c3989))
* **renovate:** use currentDigest for BOSL2 ([#92](https://github.com/kellervater/homeracker/issues/92)) ([99704a5](https://github.com/kellervater/homeracker/commit/99704a500f9154ea270552db3b0274999a8649c7))
* **renovate:** use full git URL for BOSL2 automerge matching ([#96](https://github.com/kellervater/homeracker/issues/96)) ([f7997e7](https://github.com/kellervater/homeracker/commit/f7997e7e3ebdff9b82ddae7e91f4955a352c5fb7))
* set executable bit on scripts for pre-commit. ([#111](https://github.com/kellervater/homeracker/issues/111)) ([9549aca](https://github.com/kellervater/homeracker/commit/9549aca0daad4b070909e1faebf2a87d51cd10ff))
* transparent favicon ([631ef6e](https://github.com/kellervater/homeracker/commit/631ef6e837eb892209c4c0c188415f29fadf875d))
* **unimount:** typo ([b5508af](https://github.com/kellervater/homeracker/commit/b5508af9d36289f1452a2cb9a734a6c1ec12f7d5))

### 📦 Dependencies

* **renovate:** update dependency asdf-vm/asdf to v0.16.7 ([#2](https://github.com/kellervater/homeracker/issues/2)) ([96ab0b6](https://github.com/kellervater/homeracker/commit/96ab0b62fe365571c4ce620f2d79adece32615e0))
* **renovate:** update dependency pre-commit to v4.2.0 ([#4](https://github.com/kellervater/homeracker/issues/4)) ([e7e6848](https://github.com/kellervater/homeracker/commit/e7e68480393665c7c8ecbe626cc9d25cde7a8d4b))
* update actions/checkout action to v5 ([#54](https://github.com/kellervater/homeracker/issues/54)) ([405cd76](https://github.com/kellervater/homeracker/commit/405cd76e23cdb7dc2db850533bd16f64f6ff13c2))
* update actions/checkout action to v6 ([#76](https://github.com/kellervater/homeracker/issues/76)) ([82c90c4](https://github.com/kellervater/homeracker/commit/82c90c4fd9ad97d152d13531b9503146d840a4c9))
* update actions/create-github-app-token action to v2 ([#52](https://github.com/kellervater/homeracker/issues/52)) ([536396f](https://github.com/kellervater/homeracker/commit/536396f6a5c69f201b9220aa692426a66365d29a))
* update actions/setup-python action to v6 ([#82](https://github.com/kellervater/homeracker/issues/82)) ([a77c738](https://github.com/kellervater/homeracker/commit/a77c7382471e3549f6b762b6d73b9425de5490c0))
* update actions/upload-artifact action to v5 ([#57](https://github.com/kellervater/homeracker/issues/57)) ([c403c66](https://github.com/kellervater/homeracker/commit/c403c66ecd8d381f67c4eac8a29dd8875b5dd30a))
* update belfryscad/bosl2 digest to 266792b ([#95](https://github.com/kellervater/homeracker/issues/95)) ([a57d100](https://github.com/kellervater/homeracker/commit/a57d1004ee25e987641de28c9ae30f738933300f))
* update belfryscad/bosl2 digest to 44e0c4e ([#114](https://github.com/kellervater/homeracker/issues/114)) ([e0c01ba](https://github.com/kellervater/homeracker/commit/e0c01ba6b7228fac4c63e640e96d4b1e68c1c531))
* update belfryscad/bosl2 digest to b47d5eb ([#119](https://github.com/kellervater/homeracker/issues/119)) ([eb4c13a](https://github.com/kellervater/homeracker/commit/eb4c13a09fb68a8201c8a54a52fa638275dbd4ef))
* update camunda/infra-global-github-actions digest to 302d4ca ([#115](https://github.com/kellervater/homeracker/issues/115)) ([0ee258f](https://github.com/kellervater/homeracker/commit/0ee258fbb28ddd1fa27c91a8259a0163f4d38f26))
* update camunda/infra-global-github-actions digest to 83dd377 ([#80](https://github.com/kellervater/homeracker/issues/80)) ([3c03342](https://github.com/kellervater/homeracker/commit/3c033423a1ebbcd80f5afd33f7c1e85c1b95b17d))
* update camunda/infra-global-github-actions digest to 92fe1f4 ([#74](https://github.com/kellervater/homeracker/issues/74)) ([abd04ce](https://github.com/kellervater/homeracker/commit/abd04ce0516324babc7df387abd06333b7fdf00a))
* update camunda/infra-global-github-actions digest to b0fe528 ([#104](https://github.com/kellervater/homeracker/issues/104)) ([03d3cd6](https://github.com/kellervater/homeracker/commit/03d3cd64df99b8d7470c6d64f297f18d0559d1f6))
* update camunda/infra-global-github-actions digest to b80b223 ([#90](https://github.com/kellervater/homeracker/issues/90)) ([177f039](https://github.com/kellervater/homeracker/commit/177f039537742ff1d3b5d1c8e5d515b257e9047a))
* update camunda/infra-global-github-actions digest to c779482 ([#118](https://github.com/kellervater/homeracker/issues/118)) ([eb8c84a](https://github.com/kellervater/homeracker/commit/eb8c84a869fc55421634b262764fe19a1a8b978b))
* update camunda/infra-global-github-actions digest to dc24d25 ([#101](https://github.com/kellervater/homeracker/issues/101)) ([ed96b2f](https://github.com/kellervater/homeracker/commit/ed96b2f46d456e7557f3029f9a705422820b8a9e))
* update dependency openscad-linux to v2025.11.16.ai29079 ([#69](https://github.com/kellervater/homeracker/issues/69)) ([59a2c75](https://github.com/kellervater/homeracker/commit/59a2c7556230fadb3cc0c7a10dd7f0cdb1304e6c))
* update openscad nightly ([#102](https://github.com/kellervater/homeracker/issues/102)) ([c73dfe2](https://github.com/kellervater/homeracker/commit/c73dfe21c25e03355ae0ae1738f06f9d6bc9206b))
* update openscad nightly ([#116](https://github.com/kellervater/homeracker/issues/116)) ([37a4b3b](https://github.com/kellervater/homeracker/commit/37a4b3ba708977c27d1686f12c27919e1fd64e8e))
* update openscad nightly ([#120](https://github.com/kellervater/homeracker/issues/120)) ([b1bdd37](https://github.com/kellervater/homeracker/commit/b1bdd37f54c2826f462c20e9a5dca382ade903d4))
* update openscad nightly ([#65](https://github.com/kellervater/homeracker/issues/65)) ([12d5c8d](https://github.com/kellervater/homeracker/commit/12d5c8d871aa8107e9f0d8430362669fb43bd931))
* update openscad nightly ([#75](https://github.com/kellervater/homeracker/issues/75)) ([fc58188](https://github.com/kellervater/homeracker/commit/fc58188dab1dafc1f6a7adcc74ffafa78a36ac26))
* update openscad nightly ([#81](https://github.com/kellervater/homeracker/issues/81)) ([c5d0ee0](https://github.com/kellervater/homeracker/commit/c5d0ee0846df4bdd85dc25ae3637f23501bad40e))
* update openscad nightly ([#91](https://github.com/kellervater/homeracker/issues/91)) ([216c977](https://github.com/kellervater/homeracker/commit/216c977d0f947c9dc2abb7e5eb2765e635933172))
* update openscad nightly ([#99](https://github.com/kellervater/homeracker/issues/99)) ([93c34c3](https://github.com/kellervater/homeracker/commit/93c34c3bf19cab309420fe0fa58d264b757aa6ea))
* update pre-commit hook renovatebot/pre-commit-hooks to v42.22.0 ([#93](https://github.com/kellervater/homeracker/issues/93)) ([e572e14](https://github.com/kellervater/homeracker/commit/e572e14659334bd96d5fa1322a3d9a3fd65b2616))
* update pre-commit hook renovatebot/pre-commit-hooks to v42.26.11 ([#100](https://github.com/kellervater/homeracker/issues/100)) ([2b2eead](https://github.com/kellervater/homeracker/commit/2b2eead8c3f2aba8c6995485c9a018f63cd063c1))
* update pre-commit hook renovatebot/pre-commit-hooks to v42.39.2 ([#121](https://github.com/kellervater/homeracker/issues/121)) ([c4c1a02](https://github.com/kellervater/homeracker/commit/c4c1a02a4024196b710d239ed8cc28e5305159ff))
* update pre-commit hooks ([#103](https://github.com/kellervater/homeracker/issues/103)) ([f298ab0](https://github.com/kellervater/homeracker/commit/f298ab0a2a294ef37eee68379df9baf3caf8bc41))
* update pre-commit hooks ([#117](https://github.com/kellervater/homeracker/issues/117)) ([ae3af57](https://github.com/kellervater/homeracker/commit/ae3af5758b774456c3b571452ea686e7b5aaf980))
* update pre-commit hooks ([#83](https://github.com/kellervater/homeracker/issues/83)) ([e41bd82](https://github.com/kellervater/homeracker/commit/e41bd8235f28f4ebf7ce923da1652e11385e2d95))

### 📚 Documentation

* added funding.yml ([cea9391](https://github.com/kellervater/homeracker/commit/cea93915dc2faa03db9c4e3a26de7eed636cfb95))
* added YT video link ([38f6437](https://github.com/kellervater/homeracker/commit/38f64377dfb394c4a7912a995620d31e280d69fc))
* contributing & deprecation ([345ed8a](https://github.com/kellervater/homeracker/commit/345ed8a18c4ab1c53a3f6ee80ef2daebe5f66b1b))
* discord webhook ([#51](https://github.com/kellervater/homeracker/issues/51)) ([6e957d6](https://github.com/kellervater/homeracker/commit/6e957d6411a679418dcb95f3bb7512a3df019cbd))
* fixed links ([9ed1685](https://github.com/kellervater/homeracker/commit/9ed1685b80f1e068c8dfe9ae5dfd8c83e374da05))
* fixes ([f50d771](https://github.com/kellervater/homeracker/commit/f50d771b60d3212fbcaec18018c94a8af583a124))
* **fix:** links in README.md to point to correct repository ([#29](https://github.com/kellervater/homeracker/issues/29)) ([b77c955](https://github.com/kellervater/homeracker/commit/b77c95513228265e55954a4e5adcdf41815d631d))
* Initial Version ([#9](https://github.com/kellervater/homeracker/issues/9)) ([3e935d4](https://github.com/kellervater/homeracker/commit/3e935d4f3da89b842c48c47c9a4f99cbf248f606))
* linux and macos support ([#87](https://github.com/kellervater/homeracker/issues/87)) ([e072ef0](https://github.com/kellervater/homeracker/commit/e072ef0c69105fcb049f200a2db8dd0d1491b5e2))
* **rackmount-ears:** readme and scad comments ([1e7e5d1](https://github.com/kellervater/homeracker/commit/1e7e5d16b66b43d8dde7aeddd37f25daeaae6d29))
* readme ([cbd41b6](https://github.com/kellervater/homeracker/commit/cbd41b65d32c2a2dfd83b495e31181f54ebdec42))
* readme ([bfcfa14](https://github.com/kellervater/homeracker/commit/bfcfa140477c382c4e51d88c089aec0a09d92f90))
* removed todo section ([e557128](https://github.com/kellervater/homeracker/commit/e5571281eb18eb0e9607ffa04117ef473eb13a83))
* setup ([cc66559](https://github.com/kellervater/homeracker/commit/cc665596c48c460a3cd29d6f80fd37bc7f90a023))
* try fixing links once more ([1ad8a68](https://github.com/kellervater/homeracker/commit/1ad8a68308f483edba45a45c40f840f8e05ccc2e))
* updated links & anchors ([44ed174](https://github.com/kellervater/homeracker/commit/44ed1746f911fb73c3233d94e4a6a740c1ca00ab))
* updated ToDos ([9dd9add](https://github.com/kellervater/homeracker/commit/9dd9add8612cc9accdf006acd6b55e1d40d2f241))

### 🔄 CI/CD

* Add CODEOWNERS file for automatic review assignment ([#50](https://github.com/kellervater/homeracker/issues/50)) ([c08b9ee](https://github.com/kellervater/homeracker/commit/c08b9ee32df19a84ad8f866ce1634777f16ac9db))
* added renovate config ([32e99ea](https://github.com/kellervater/homeracker/commit/32e99eae744d1886ac1396ab44f192c57175c8a6))
* auto approve release prs ([#58](https://github.com/kellervater/homeracker/issues/58)) ([f04d780](https://github.com/kellervater/homeracker/commit/f04d780ce0bc361bf4462b56774bca8e9d001204))
* automerge ([3de18db](https://github.com/kellervater/homeracker/commit/3de18db9315e523c4e3435b15c0696696fde840c))
* change changelog-type from 'github' to 'default' ([b523b82](https://github.com/kellervater/homeracker/commit/b523b827129c486e4674dbca5b5d97d720babc43))
* disable platform automerge ([18ed555](https://github.com/kellervater/homeracker/commit/18ed555e943e85c386b1ca9592142202950f29e7))
* don't need explicit renovate annotatation on shellcheck ([78b1b8d](https://github.com/kellervater/homeracker/commit/78b1b8d5ddf366fb811a54c71c4c378958cd3e07))
* improve pre-commit hooks ([#97](https://github.com/kellervater/homeracker/issues/97)) ([b1f416b](https://github.com/kellervater/homeracker/commit/b1f416b59f2acf0366ab6dcb418b651bf3ad7475)), closes [#45](https://github.com/kellervater/homeracker/issues/45)
* linting ([33eb8a8](https://github.com/kellervater/homeracker/commit/33eb8a876f237a67f79016eb1257a00ef25ddeed))
* linting ([eb327aa](https://github.com/kellervater/homeracker/commit/eb327aab0e2c4c52ca9589755d2f1492743b1677))
* **pr titles:** fix validation ([d87e499](https://github.com/kellervater/homeracker/commit/d87e49989c7e607cca449ef6de97a872938cc08c))
* **pre-commit:** enforce conventional commits ([#112](https://github.com/kellervater/homeracker/issues/112)) ([c3ec5ef](https://github.com/kellervater/homeracker/commit/c3ec5ef9a860c5514b654aecda61f1e6bcffad5b))
* remove auto-approval wf ([d8e06f4](https://github.com/kellervater/homeracker/commit/d8e06f4a7de88b69a76c0f1a970f4025318781e2))
* renovate automerge config ([0b003c7](https://github.com/kellervater/homeracker/commit/0b003c772dc051c7beca8444ffd6dc41f9730223))
* renovate config ([8cd9ed9](https://github.com/kellervater/homeracker/commit/8cd9ed9b0a85be073da9f78a1b2cc91fda9bd877))
* renovate regex try [#2](https://github.com/kellervater/homeracker/issues/2) ([2a0be43](https://github.com/kellervater/homeracker/commit/2a0be436dccd6f6c9777d39518e6789147946830))
* **renovate:** activate automerge for openscad ([#64](https://github.com/kellervater/homeracker/issues/64)) ([0f1c11e](https://github.com/kellervater/homeracker/commit/0f1c11e03a4231f9589721e0c321da6783b772e4))
* **renovate:** add BOSL2 to automerge section ([3718452](https://github.com/kellervater/homeracker/commit/3718452d343e32629c4547883f74168e439e620d))
* **renovate:** align release and renovate schedules ([24a1bca](https://github.com/kellervater/homeracker/commit/24a1bca18bbbf5f3e5a053717044925ef9bf3e32))
* **renovate:** allow automerge for actions/chekcout ([7641f1e](https://github.com/kellervater/homeracker/commit/7641f1ecf9fea59b15cf6867f4d73ee21942a22d))
* **renovate:** allow automerge of actions/create-github-app-token ([a78dccc](https://github.com/kellervater/homeracker/commit/a78dccc44ff00342fbc584401eded40f98f084c0))
* **renovate:** allow PRs anytime ([5a7cadc](https://github.com/kellervater/homeracker/commit/5a7cadc4c906025fd93e10ea13241c5d20a6ad39))
* **renovate:** automerge various gha ([#84](https://github.com/kellervater/homeracker/issues/84)) ([cdf34e3](https://github.com/kellervater/homeracker/commit/cdf34e375e46b231dfc2372bd324cbcc579e8688))
* **renovate:** deactivate platform automerge ([50f49ef](https://github.com/kellervater/homeracker/commit/50f49ef8e67f59cfeb19981546bdbf0be3886f43))
* **renovate:** enable weekly schedule ([c47bae8](https://github.com/kellervater/homeracker/commit/c47bae881b82f7125a4eb24e7db1bf252b3f4b79))
* **renovate:** fix BOSL2 upgrades ([#89](https://github.com/kellervater/homeracker/issues/89)) ([a337a17](https://github.com/kellervater/homeracker/commit/a337a17558b8d52e2b4b9271583353860d70bddf))
* **renovate:** fix syntax, change prefixes ([07b4912](https://github.com/kellervater/homeracker/commit/07b4912e9843bc6ee05926d136acf362104876fb))
* **renovate:** group pre-commit PRs ([#79](https://github.com/kellervater/homeracker/issues/79)) ([68d036e](https://github.com/kellervater/homeracker/commit/68d036ee2f3a364ec22ff86fffc18208bfb4fd2c))
* **renovate:** prettify commit prefixes ([cae76bb](https://github.com/kellervater/homeracker/commit/cae76bb4370ba0ef9767d0af0b477900ed491bd3))
* try regex ([6ad1f15](https://github.com/kellervater/homeracker/commit/6ad1f15857f9fb8834463562961d16711de3777f))
* use different automerge approach ([#59](https://github.com/kellervater/homeracker/issues/59)) ([606881f](https://github.com/kellervater/homeracker/commit/606881f599c75a215151c38dd03ac64835b36a7d))

### 🔧 Miscellaneous

* Configure Renovate ([#8](https://github.com/kellervater/homeracker/issues/8)) ([021cf7b](https://github.com/kellervater/homeracker/commit/021cf7b78d996247b72816cb7755976d9fe09b4e))
* **deps:** update openscad nightly to v2025 ([#62](https://github.com/kellervater/homeracker/issues/62)) ([50bbaea](https://github.com/kellervater/homeracker/commit/50bbaea689a928b416e4476f7d3cd80e04a7a873))
* **main:** release 1.0.0 ([#56](https://github.com/kellervater/homeracker/issues/56)) ([14d2ee0](https://github.com/kellervater/homeracker/commit/14d2ee094202f09f6e8dd34d71b6a254593fb4ac))
* **main:** release 1.0.1 ([#61](https://github.com/kellervater/homeracker/issues/61)) ([11cd80c](https://github.com/kellervater/homeracker/commit/11cd80c7bf61c90b91b2aa675d490da10177d49a))
* **main:** release 1.1.0 ([#78](https://github.com/kellervater/homeracker/issues/78)) ([ad04112](https://github.com/kellervater/homeracker/commit/ad04112dd8b4fb5a39e83001ad9d82fcbc6fba88))
* **main:** release 1.2.0 ([#86](https://github.com/kellervater/homeracker/issues/86)) ([c4b2415](https://github.com/kellervater/homeracker/commit/c4b24150d2cc2b3e576f78602f6c2c841deb5ac1))
* pre-commit config for python ([bbb742f](https://github.com/kellervater/homeracker/commit/bbb742f2715971b73f7aa2b9dea373dc17dca6da))
* **renovate:** config hygiene ([e5337de](https://github.com/kellervater/homeracker/commit/e5337de0bea5c011619c1c569b839d8666a785ad))

### ♻️ Code Refactoring

* docs and licenses ([04f76ac](https://github.com/kellervater/homeracker/commit/04f76ace155185b5e926573a58fe708d4f5e5566))
* move rackmount ears ([bee5fd9](https://github.com/kellervater/homeracker/commit/bee5fd99e75c14c8299ee5087e0344766936c3e6))
* renovate and docker ([0b9553a](https://github.com/kellervater/homeracker/commit/0b9553a5953a92bf8fd7abb3af8de36b9cabbffb))
* we obviously don't need this fluff ([c6de162](https://github.com/kellervater/homeracker/commit/c6de16260d0278448bc78731b0ca2e7653ba9d7d))

## [1.2.0](https://github.com/kellervater/homeracker/compare/v1.1.0...v1.2.0) (2025-11-30)

### ✨ Features

* **core:** added more pull-through feet ([#85](https://github.com/kellervater/homeracker/issues/85)) ([d4461c4](https://github.com/kellervater/homeracker/commit/d4461c4f6841d9316901127a4e21240775c7493b))

### 🐛 Bug Fixes

* **renovate:** use currentDigest for BOSL2 ([#92](https://github.com/kellervater/homeracker/issues/92)) ([99704a5](https://github.com/kellervater/homeracker/commit/99704a500f9154ea270552db3b0274999a8649c7))
* **renovate:** use full git URL for BOSL2 automerge matching ([#96](https://github.com/kellervater/homeracker/issues/96)) ([f7997e7](https://github.com/kellervater/homeracker/commit/f7997e7e3ebdff9b82ddae7e91f4955a352c5fb7))

### 📦 Dependencies

* update belfryscad/bosl2 digest to 266792b ([#95](https://github.com/kellervater/homeracker/issues/95)) ([a57d100](https://github.com/kellervater/homeracker/commit/a57d1004ee25e987641de28c9ae30f738933300f))
* update camunda/infra-global-github-actions digest to b0fe528 ([#104](https://github.com/kellervater/homeracker/issues/104)) ([03d3cd6](https://github.com/kellervater/homeracker/commit/03d3cd64df99b8d7470c6d64f297f18d0559d1f6))
* update camunda/infra-global-github-actions digest to b80b223 ([#90](https://github.com/kellervater/homeracker/issues/90)) ([177f039](https://github.com/kellervater/homeracker/commit/177f039537742ff1d3b5d1c8e5d515b257e9047a))
* update camunda/infra-global-github-actions digest to dc24d25 ([#101](https://github.com/kellervater/homeracker/issues/101)) ([ed96b2f](https://github.com/kellervater/homeracker/commit/ed96b2f46d456e7557f3029f9a705422820b8a9e))
* update openscad nightly ([#102](https://github.com/kellervater/homeracker/issues/102)) ([c73dfe2](https://github.com/kellervater/homeracker/commit/c73dfe21c25e03355ae0ae1738f06f9d6bc9206b))
* update openscad nightly ([#91](https://github.com/kellervater/homeracker/issues/91)) ([216c977](https://github.com/kellervater/homeracker/commit/216c977d0f947c9dc2abb7e5eb2765e635933172))
* update openscad nightly ([#99](https://github.com/kellervater/homeracker/issues/99)) ([93c34c3](https://github.com/kellervater/homeracker/commit/93c34c3bf19cab309420fe0fa58d264b757aa6ea))
* update pre-commit hook renovatebot/pre-commit-hooks to v42.22.0 ([#93](https://github.com/kellervater/homeracker/issues/93)) ([e572e14](https://github.com/kellervater/homeracker/commit/e572e14659334bd96d5fa1322a3d9a3fd65b2616))
* update pre-commit hook renovatebot/pre-commit-hooks to v42.26.11 ([#100](https://github.com/kellervater/homeracker/issues/100)) ([2b2eead](https://github.com/kellervater/homeracker/commit/2b2eead8c3f2aba8c6995485c9a018f63cd063c1))
* update pre-commit hooks ([#103](https://github.com/kellervater/homeracker/issues/103)) ([f298ab0](https://github.com/kellervater/homeracker/commit/f298ab0a2a294ef37eee68379df9baf3caf8bc41))

### 📚 Documentation

* contributing & deprecation ([345ed8a](https://github.com/kellervater/homeracker/commit/345ed8a18c4ab1c53a3f6ee80ef2daebe5f66b1b))
* linux and macos support ([#87](https://github.com/kellervater/homeracker/issues/87)) ([e072ef0](https://github.com/kellervater/homeracker/commit/e072ef0c69105fcb049f200a2db8dd0d1491b5e2))
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

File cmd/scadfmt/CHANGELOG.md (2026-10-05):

# Changelog

## [0.3.0](https://github.com/kellerlabs/homeracker/compare/scadfmt-v0.2.0...scadfmt-v0.3.0) (2026-10-05)

### ✨ Features

* **scadfmt:** write VS Code settings into a .code-workspace file; fail PRs on surviving mutants ([#531](https://github.com/kellerlabs/homeracker/issues/531)) ([942938e](https://github.com/kellerlabs/homeracker/commit/942938e911508123dd11ee481c4f3281266c2cd3))

## [0.2.0](https://github.com/kellerlabs/homeracker/compare/scadfmt-v0.1.0...scadfmt-v0.2.0) (2026-09-28)

### ✨ Features

* **scadfmt:** adapt scadfmt to new OpenSCAD nightlies with an agent ([#526](https://github.com/kellerlabs/homeracker/issues/526)) ([b1935c0](https://github.com/kellerlabs/homeracker/commit/b1935c050fb564dd223d5e3fd582e056fd5ff8d8))
* **scadfmt:** add coverage and mutation testing with badges ([#521](https://github.com/kellerlabs/homeracker/issues/521)) ([f81e176](https://github.com/kellerlabs/homeracker/commit/f81e176b2ba7ac3f1c064a170dbdb700e5f4c110))
* **scadfmt:** format all .scad files and enforce it in pre-commit ([#524](https://github.com/kellerlabs/homeracker/issues/524)) ([3e80080](https://github.com/kellerlabs/homeracker/commit/3e80080a2936ac4e83547dde47b9f503a3f236bc))

## 0.1.0 (2026-09-27)

### ✨ Features

* **scadfmt:** add token-based OpenSCAD formatter ([#520](https://github.com/kellerlabs/homeracker/issues/520)) ([830ff0d](https://github.com/kellerlabs/homeracker/commit/830ff0dbf5d20c8a0a128e82f3842a20ab96339d))

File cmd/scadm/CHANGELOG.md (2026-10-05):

# Changelog

## [0.12.0](https://github.com/kellerlabs/homeracker/compare/scadm-v0.11.0...scadm-v0.12.0) (2026-10-05)

### ✨ Features

* **scadfmt:** write VS Code settings into a .code-workspace file; fail PRs on surviving mutants ([#531](https://github.com/kellerlabs/homeracker/issues/531)) ([942938e](https://github.com/kellerlabs/homeracker/commit/942938e911508123dd11ee481c4f3281266c2cd3))

## [0.11.0](https://github.com/kellerlabs/homeracker/compare/scadm-v0.10.1...scadm-v0.11.0) (2026-09-27)

### ✨ Features

* **scadm:** gate unit coverage at 90% and run weekly mutation tests ([#507](https://github.com/kellerlabs/homeracker/issues/507)) ([0600151](https://github.com/kellerlabs/homeracker/commit/060015180e8fdbf82a5844b68e21862c0e939546))
* **scadm:** scope mutation tests to changed functions, report weekly to Discord ([#509](https://github.com/kellerlabs/homeracker/issues/509)) ([a252759](https://github.com/kellerlabs/homeracker/commit/a252759ec6aac611df17898c0211c2b4a0c0f00e))

## [0.10.1](https://github.com/kellerlabs/homeracker/compare/scadm-v0.10.0...scadm-v0.10.1) (2026-09-14)

### ♻️ Code Refactoring

* **instructions:** make AGENTS.md canonical and align docs with house-style ([#484](https://github.com/kellerlabs/homeracker/issues/484)) ([ef337d5](https://github.com/kellerlabs/homeracker/commit/ef337d57ba903edb2602e5dc6b36c18c2fe36a8d))

## [0.10.0](https://github.com/kellerlabs/homeracker/compare/scadm-v0.9.0...scadm-v0.10.0) (2026-07-04)

### ✨ Features

* **scadm:** parallelize model rendering ([#428](https://github.com/kellerlabs/homeracker/issues/428)) ([dac9d50](https://github.com/kellerlabs/homeracker/commit/dac9d50fab3d5934904d8cae0714a890edd7d759))

## [0.9.0](https://github.com/kellerlabs/homeracker/compare/scadm-v0.8.0...scadm-v0.9.0) (2026-06-20)

### ✨ Features

* **skills:** add grill-my-plan skill + exclude tests from pylint ([#410](https://github.com/kellerlabs/homeracker/issues/410)) ([13cdb17](https://github.com/kellerlabs/homeracker/commit/13cdb17c8f9c7b64d08cb359409ad6fe828aac68))

### 🐛 Bug Fixes

* **scadm:** ignore semicolons inside strings when flattening definitions ([#408](https://github.com/kellerlabs/homeracker/issues/408)) ([848f044](https://github.com/kellerlabs/homeracker/commit/848f0448b29bf444f25063e5cce67d001699e7b9))

## [0.8.0](https://github.com/kellerlabs/homeracker/compare/scadm-v0.7.0...scadm-v0.8.0) (2026-05-10)

### ✨ Features

* **scadm:** add export-png command and decision-records skill ([#366](https://github.com/kellerlabs/homeracker/issues/366)) ([4fac176](https://github.com/kellerlabs/homeracker/commit/4fac17681d01b9cb58f98809fbb37494db55445e))

## [0.7.0](https://github.com/kellerlabs/homeracker/compare/scadm-v0.6.3...scadm-v0.7.0) (2026-04-18)

### ✨ Features

* **flatten:** resilient parsing, dead-code elimination, section tolerance ([#327](https://github.com/kellerlabs/homeracker/issues/327)) ([3509d66](https://github.com/kellerlabs/homeracker/commit/3509d660beaffba18146d43faa64d78390e17944))
* **scadm:** dynamic OpenSCAD version resolution ([#311](https://github.com/kellerlabs/homeracker/issues/311)) ([026c5d8](https://github.com/kellerlabs/homeracker/commit/026c5d85cfbaa599ff6ffc838017f1eb3c8b9942))

### 🐛 Bug Fixes

* **scadm:** remove searchPaths from vscode settings ([1b09f88](https://github.com/kellerlabs/homeracker/commit/1b09f887af6cf297d4055ecac29e112776cc7ec6))
* **scadm:** remove searchPaths from vscode settings ([#342](https://github.com/kellerlabs/homeracker/issues/342)) ([d960286](https://github.com/kellerlabs/homeracker/commit/d960286b5fcfa6d839bc5580b84c4a926599d706))

### 📦 Dependencies

* update openscad nightly to v2026.04.16 ([#339](https://github.com/kellerlabs/homeracker/issues/339)) ([8109557](https://github.com/kellerlabs/homeracker/commit/8109557c15c2d67418eddb5c3f118ec07476b2f2))

## [0.6.3](https://github.com/kellerlabs/homeracker/compare/scadm-v0.6.2...scadm-v0.6.3) (2026-04-11)

### 📦 Dependencies

* update openscad nightly to v2026.04.08 ([#322](https://github.com/kellerlabs/homeracker/issues/322)) ([ab8340f](https://github.com/kellerlabs/homeracker/commit/ab8340f163deb35015fcdcb4d37729e6f60bdbd8))

## [0.6.2](https://github.com/kellerlabs/homeracker/compare/scadm-v0.6.1...scadm-v0.6.2) (2026-04-06)

### 📦 Dependencies

* update openscad nightly to v2026.04.03 ([#313](https://github.com/kellerlabs/homeracker/issues/313)) ([d3e23fe](https://github.com/kellerlabs/homeracker/commit/d3e23fe663f83f83b1ac922adb1e60f28a608acc))
* update openscad nightly to v2026.04.04 ([#315](https://github.com/kellerlabs/homeracker/issues/315)) ([97d4093](https://github.com/kellerlabs/homeracker/commit/97d40934437f7269ce0f691232bb2230e1a3bd52))

## [0.6.1](https://github.com/kellerlabs/homeracker/compare/scadm-v0.6.0...scadm-v0.6.1) (2026-03-29)

### 📦 Dependencies

* update openscad nightly to v2026.03.28 ([#304](https://github.com/kellerlabs/homeracker/issues/304)) ([ce843da](https://github.com/kellerlabs/homeracker/commit/ce843da3951053badac8de6d6fe63c2154828874))

### 🔧 Miscellaneous

* untrack .flatten-checksums and cache it in CI ([#301](https://github.com/kellerlabs/homeracker/issues/301)) ([c2438c2](https://github.com/kellerlabs/homeracker/commit/c2438c290fd8a5fbfd94b61477226be0ef01e953))

## [0.6.0](https://github.com/kellerlabs/homeracker/compare/scadm-v0.5.3...scadm-v0.6.0) (2026-03-23)

### ✨ Features

* **scadm:** add --source and --flattened flags to render command ([#294](https://github.com/kellerlabs/homeracker/issues/294)) ([98a53ed](https://github.com/kellerlabs/homeracker/commit/98a53ed447be7a698d976dd44b41c9ae998fc436))

### 📦 Dependencies

* update openscad nightly to v2026.03.20 ([#291](https://github.com/kellerlabs/homeracker/issues/291)) ([a42cc01](https://github.com/kellerlabs/homeracker/commit/a42cc01b3b7ccf7b2d8fcb01ae5af95161a6b618))
* update openscad nightly to v2026.03.22 ([#297](https://github.com/kellerlabs/homeracker/issues/297)) ([5901af2](https://github.com/kellerlabs/homeracker/commit/5901af28d0968a7a2b2526f540fb674f6e74ff45))

## [0.5.3](https://github.com/kellerlabs/homeracker/compare/scadm-v0.5.2...scadm-v0.5.3) (2026-03-20)

### 🐛 Bug Fixes

* **scadm:** hash flatten.py at fixed position in compute_checksum ([#289](https://github.com/kellerlabs/homeracker/issues/289)) ([a584dc2](https://github.com/kellerlabs/homeracker/commit/a584dc29201019840ca389d2f0420de8b704d136))

## [0.5.2](https://github.com/kellerlabs/homeracker/compare/scadm-v0.5.1...scadm-v0.5.2) (2026-03-20)

### 🐛 Bug Fixes

* **scadm:** sort deps by relative path in compute_checksum ([#287](https://github.com/kellerlabs/homeracker/issues/287)) ([b0a6be7](https://github.com/kellerlabs/homeracker/commit/b0a6be7c682728cda729950855bec71ebd473296))

## [0.5.1](https://github.com/kellerlabs/homeracker/compare/scadm-v0.5.0...scadm-v0.5.1) (2026-03-20)

### 📚 Documentation

* **scadm:** add flatten file structure conventions ([7d644bc](https://github.com/kellerlabs/homeracker/commit/7d644bc56b84edceb3f758f0746544183ebdbefc))

### 🔧 Miscellaneous

* **sync-instructions:** address PR review feedback ([00f4b4c](https://github.com/kellerlabs/homeracker/commit/00f4b4c1c450cdccdcfe07f07e46165a1efdc0a6))

### ♻️ Code Refactoring

* rename makerworld/ directories to flattened/ ([#284](https://github.com/kellerlabs/homeracker/issues/284)) ([8c937db](https://github.com/kellerlabs/homeracker/commit/8c937db5ace61cc3a0bade19aa258587db86cdff))

## [0.5.0](https://github.com/kellerlabs/homeracker/compare/scadm-v0.4.11...scadm-v0.5.0) (2026-03-20)

### ✨ Features

* **scadm:** add flatten and render subcommands ([#283](https://github.com/kellerlabs/homeracker/issues/283)) ([9816c3c](https://github.com/kellerlabs/homeracker/commit/9816c3ccebf0c0a012376dc4158a6c2dcfd70bd3))

## [0.4.11](https://github.com/kellerlabs/homeracker/compare/scadm-v0.4.10...scadm-v0.4.11) (2026-03-15)

### 📦 Dependencies

* update openscad nightly to v2026.03.14 ([#263](https://github.com/kellerlabs/homeracker/issues/263)) ([7a0aead](https://github.com/kellerlabs/homeracker/commit/7a0aead7d97c07fee22003efd0268cf83d016726))

## [0.4.10](https://github.com/kellerlabs/homeracker/compare/scadm-v0.4.9...scadm-v0.4.10) (2026-03-01)

### 📦 Dependencies

* update openscad nightly to v2026.02.25 ([#247](https://github.com/kellerlabs/homeracker/issues/247)) ([46b50a7](https://github.com/kellerlabs/homeracker/commit/46b50a7c8c979c708965bc8ed6641b279ced12b9))
* update openscad nightly to v2026.03.01 ([#252](https://github.com/kellerlabs/homeracker/issues/252)) ([d6f44de](https://github.com/kellerlabs/homeracker/commit/d6f44dee43bec06a9cea88ba1de920c0330f9898))

## [0.4.9](https://github.com/kellerlabs/homeracker/compare/scadm-v0.4.8...scadm-v0.4.9) (2026-02-22)

### 📦 Dependencies

* update openscad nightly to v2026.02.19 ([#240](https://github.com/kellerlabs/homeracker/issues/240)) ([b76725c](https://github.com/kellerlabs/homeracker/commit/b76725cc52963825bb224d3bd37564247fdee0a9))

## [0.4.8](https://github.com/kellerlabs/homeracker/compare/scadm-v0.4.7...scadm-v0.4.8) (2026-02-15)

### 📦 Dependencies

* update openscad nightly to v2026.02.09 ([#227](https://github.com/kellerlabs/homeracker/issues/227)) ([6d292d3](https://github.com/kellerlabs/homeracker/commit/6d292d358b9dd8aa61e210a0c7782afb73ac8d85))
* update openscad nightly to v2026.02.13 ([#230](https://github.com/kellerlabs/homeracker/issues/230)) ([6a23b48](https://github.com/kellerlabs/homeracker/commit/6a23b48f7047add55401295135ebac7e88324810))
* update openscad nightly to v2026.02.15 ([#236](https://github.com/kellerlabs/homeracker/issues/236)) ([fd4f1db](https://github.com/kellerlabs/homeracker/commit/fd4f1db6a5961ce4939474e894588cf806bb5bad))

## [0.4.7](https://github.com/kellerlabs/homeracker/compare/scadm-v0.4.6...scadm-v0.4.7) (2026-02-09)

### 📦 Dependencies

* update dependency openscad-windows to v2026.02.07 ([#222](https://github.com/kellerlabs/homeracker/issues/222)) ([94928af](https://github.com/kellerlabs/homeracker/commit/94928af85cb9445bd6702427f8f48b75518020f6))

### 📚 Documentation

* **scadm:** fix homeracker version ref ([6c68b2e](https://github.com/kellerlabs/homeracker/commit/6c68b2e145030411f728ec6c29f39ae21efa40e1))

## [0.4.6](https://github.com/kellerlabs/homeracker/compare/scadm-v0.4.5...scadm-v0.4.6) (2026-02-02)

### 📦 Dependencies

* update dependency openscad-windows to v2026.01.29 ([#214](https://github.com/kellerlabs/homeracker/issues/214)) ([7e49ff6](https://github.com/kellerlabs/homeracker/commit/7e49ff6f389a475173113a0e31480dea2af42810))
* update dependency openscad-windows to v2026.02.01 ([#218](https://github.com/kellerlabs/homeracker/issues/218)) ([8a04981](https://github.com/kellerlabs/homeracker/commit/8a0498182cdd044d4c0e74e36677f1ba928faceb))

## [0.4.5](https://github.com/kellerlabs/homeracker/compare/scadm-v0.4.4...scadm-v0.4.5) (2026-01-25)

### 📦 Dependencies

* update dependency openscad-windows to v2026.01.19 ([#210](https://github.com/kellerlabs/homeracker/issues/210)) ([c57df5a](https://github.com/kellerlabs/homeracker/commit/c57df5adcf7967cf6e21b5fa8d622673bd7fc38e))
* update dependency openscad-windows to v2026.01.25 ([#211](https://github.com/kellerlabs/homeracker/issues/211)) ([e4f6407](https://github.com/kellerlabs/homeracker/commit/e4f640767a17eba1c7e8dd5efc208515cc1b47cf))

## [0.4.4](https://github.com/kellerlabs/homeracker/compare/scadm-v0.4.3...scadm-v0.4.4) (2026-01-18)

### 📦 Dependencies

* update dependency openscad-windows to v2026.01.18 ([#202](https://github.com/kellerlabs/homeracker/issues/202)) ([b7098c9](https://github.com/kellerlabs/homeracker/commit/b7098c985831d87701509cb4d5e29b9e9f194405))

### ♻️ Code Refactoring

* update repository references from kellervater to kellerlabs ([#198](https://github.com/kellerlabs/homeracker/issues/198)) ([8e5717b](https://github.com/kellerlabs/homeracker/commit/8e5717bf0ee1b8b2e06d247fccb83eced79f06ee))

## [0.4.3](https://github.com/kellervater/homeracker/compare/scadm-v0.4.2...scadm-v0.4.3) (2026-01-04)

### 📦 Dependencies

* update dependency openscad-windows to v2026.01.03 ([#186](https://github.com/kellervater/homeracker/issues/186)) ([fce4a5a](https://github.com/kellervater/homeracker/commit/fce4a5ae4af4324405e63a119a5204fa941819ac))
* update openscad nightly to v2026 ([#182](https://github.com/kellervater/homeracker/issues/182)) ([45efd5c](https://github.com/kellervater/homeracker/commit/45efd5c58e53859d94c5af7bfe08a8f8bc75003e))

## [0.4.2](https://github.com/kellervater/homeracker/compare/scadm-v0.4.1...scadm-v0.4.2) (2025-12-28)

### 📦 Dependencies

* update openscad nightly ([#165](https://github.com/kellervater/homeracker/issues/165)) ([7f8746c](https://github.com/kellervater/homeracker/commit/7f8746c1c923934d4e4eec0a87b140849aa55919))
* update openscad nightly ([#168](https://github.com/kellervater/homeracker/issues/168)) ([fe441bd](https://github.com/kellervater/homeracker/commit/fe441bd91f4019676d52981e70cb88ca8a09ca56))
* update openscad nightly ([#171](https://github.com/kellervater/homeracker/issues/171)) ([fccf876](https://github.com/kellervater/homeracker/commit/fccf87602d08aef6c9aa0ea41d6ad1353ca9eb93))

## [0.4.1](https://github.com/kellervater/homeracker/compare/scadm-v0.4.0...scadm-v0.4.1) (2025-12-20)

### 📦 Dependencies

* update openscad nightly ([#161](https://github.com/kellervater/homeracker/issues/161)) ([c22aa62](https://github.com/kellervater/homeracker/commit/c22aa62536b6664a6aa112ac5424bc39b5593163))

## [0.4.0](https://github.com/kellervater/homeracker/compare/scadm-v0.3.0...scadm-v0.4.0) (2025-12-15)

### ✨ Features

* **scadm:** add --version flag ([#140](https://github.com/kellervater/homeracker/issues/140)) ([5a7d98c](https://github.com/kellervater/homeracker/commit/5a7d98cfd33c36f9d6e1df95181c42c5c6195b2f))

### 📦 Dependencies

* update openscad nightly ([#148](https://github.com/kellervater/homeracker/issues/148)) ([29756dd](https://github.com/kellervater/homeracker/commit/29756ddfd902c61add8094f56d17e8b709789eda))

## [0.3.0](https://github.com/kellervater/homeracker/compare/scadm-v0.2.1...scadm-v0.3.0) (2025-12-08)

### ✨ Features

* **scadm:** add Python extension support to vscode command ([#133](https://github.com/kellervater/homeracker/issues/133)) ([0bee683](https://github.com/kellervater/homeracker/commit/0bee683232593428290fe116fd7af9ce2c732816))
* **scadm:** add vscode command for extension management ([#131](https://github.com/kellervater/homeracker/issues/131)) ([573c9dd](https://github.com/kellervater/homeracker/commit/573c9ddbbe420c0bd4f1631e240a54e9bac5d5d3))

## [0.2.1](https://github.com/kellervater/homeracker/compare/scadm-v0.2.0...scadm-v0.2.1) (2025-12-07)

### 📦 Dependencies

* update openscad nightly ([#124](https://github.com/kellervater/homeracker/issues/124)) ([b12fc92](https://github.com/kellervater/homeracker/commit/b12fc92673c85ecd519e5875aed2c68d55a3a2ad))

## [0.2.0](https://github.com/kellervater/homeracker/compare/scadm-v0.1.0...scadm-v0.2.0) (2025-12-07)

### ✨ Features

* implement custom dependency manager and renovate preset ([#106](https://github.com/kellervater/homeracker/issues/106)) ([96393d1](https://github.com/kellervater/homeracker/commit/96393d1e91c657abbbfc03465e0c089080300346))

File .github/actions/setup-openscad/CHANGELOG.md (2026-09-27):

# Changelog

## [2.2.2](https://github.com/kellerlabs/homeracker/compare/setup-openscad-v2.2.1...setup-openscad-v2.2.2) (2026-09-27)

### 🐛 Bug Fixes

* **ci:** pass action inputs via env and enforce zizmor template-injection ([#510](https://github.com/kellerlabs/homeracker/issues/510)) ([74e77b1](https://github.com/kellerlabs/homeracker/commit/74e77b1e9474b3bb67c7fc0fdd77b05a5aec6229))

## [2.2.1](https://github.com/kellerlabs/homeracker/compare/setup-openscad-v2.2.0...setup-openscad-v2.2.1) (2026-09-14)

### ♻️ Code Refactoring

* **instructions:** make AGENTS.md canonical and align docs with house-style ([#484](https://github.com/kellerlabs/homeracker/issues/484)) ([ef337d5](https://github.com/kellerlabs/homeracker/commit/ef337d57ba903edb2602e5dc6b36c18c2fe36a8d))

## [2.2.0](https://github.com/kellerlabs/homeracker/compare/setup-openscad-v2.1.2...setup-openscad-v2.2.0) (2026-09-05)

### ✨ Features

* **ci:** pin every action to a commit SHA and enforce it with zizmor ([#475](https://github.com/kellerlabs/homeracker/issues/475)) ([569b564](https://github.com/kellerlabs/homeracker/commit/569b564762600cf9321bf3b33f32d614d3d1b03b))

## [2.1.2](https://github.com/kellerlabs/homeracker/compare/setup-openscad-v2.1.1...setup-openscad-v2.1.2) (2026-07-25)

### 📦 Dependencies

* update actions/setup-python action to v7 ([#436](https://github.com/kellerlabs/homeracker/issues/436)) ([6a818af](https://github.com/kellerlabs/homeracker/commit/6a818afca77ba8678523bf30a4c3cbb71bea729b))

## [2.1.1](https://github.com/kellerlabs/homeracker/compare/setup-openscad-v2.1.0...setup-openscad-v2.1.1) (2026-06-27)

### 📦 Dependencies

* update actions/cache action to v6 ([#418](https://github.com/kellerlabs/homeracker/issues/418)) ([a01974f](https://github.com/kellerlabs/homeracker/commit/a01974f0556d6eec0d9c0da6a829f43dbf40bd2f))

## [2.1.0](https://github.com/kellerlabs/homeracker/compare/setup-openscad-v2.0.0...setup-openscad-v2.1.0) (2026-04-18)

### ✨ Features

* **scadm:** dynamic OpenSCAD version resolution ([#311](https://github.com/kellerlabs/homeracker/issues/311)) ([026c5d8](https://github.com/kellerlabs/homeracker/commit/026c5d85cfbaa599ff6ffc838017f1eb3c8b9942))

## [2.0.0](https://github.com/kellerlabs/homeracker/compare/setup-openscad-v1.1.0...setup-openscad-v2.0.0) (2026-04-11)

### ⚠ BREAKING CHANGES

* **setup-openscad:** add scadm-requirements input, remove default version ([#329](https://github.com/kellerlabs/homeracker/issues/329))

### ✨ Features

* **setup-openscad:** add scadm-requirements input, remove default version ([#329](https://github.com/kellerlabs/homeracker/issues/329)) ([85fa9f8](https://github.com/kellerlabs/homeracker/commit/85fa9f8c289be47bfa0d56ec9590606aa8d8fa83))

## [1.1.0](https://github.com/kellerlabs/homeracker/compare/setup-openscad-v1.0.0...setup-openscad-v1.1.0) (2026-03-20)

### ✨ Features

* **scadm:** add flatten and render subcommands ([#283](https://github.com/kellerlabs/homeracker/issues/283)) ([9816c3c](https://github.com/kellerlabs/homeracker/commit/9816c3ccebf0c0a012376dc4158a6c2dcfd70bd3))

## 1.0.0 (2026-03-15)

### ✨ Features

* **setup-openscad:** make action reusable across repositories ([#273](https://github.com/kellerlabs/homeracker/issues/273)) ([055e784](https://github.com/kellerlabs/homeracker/commit/055e78444f59d351e8a943ab7c8ae04d8c34f259))

### 🔄 CI/CD

* cache CI environments & add PR template ([#269](https://github.com/kellerlabs/homeracker/issues/269)) ([ca78385](https://github.com/kellerlabs/homeracker/commit/ca783858fbc69842d064dbb92e608504b11784fc))

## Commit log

2026-02-01 deps: update dependency openscad-windows to v2026.02.01 (#218)
    This PR contains the following updates:
    | Package | Update | Change |
    |---|---|---|
    | OpenSCAD-Windows | minor | `2026.01.29` → `2026.02.01` |
    ---
    ### Configuration
    📅 **Schedule**: Branch creation - Only on Sunday and Saturday ( * * * *
    0,6 ) (UTC), Automerge - At any time (no schedule defined).
    🚦 **Automerge**: Enabled.
    ♻ **Rebasing**: Whenever PR is behind base branch, or you tick the
    rebase/retry checkbox.
    🔕 **Ignore**: Close this PR and you won't be reminded about this update
    again.
    ---
    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
2026-02-07 deps: update belfryscad/bosl2 digest to 0e03331 (#220)
    | BelfrySCAD/BOSL2 | digest | `ffa493b` → `0e03331` |
    - [ ] <!-- rebase-check -->If you want to rebase/retry this PR, check
    this box
    This PR was generated by [Mend Renovate](https: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
2026-02-07 deps: update camunda/infra-global-github-actions digest to 317ad65 (#221)
    | Package | Type | Update | Change |
    |---|---|---|---|
    | camunda/infra-global-github-actions | action | digest | `df04776` →
    `317ad65` |
    this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
2026-02-07 deps: update dependency openscad-windows to v2026.02.07 (#222)
    | OpenSCAD-Windows | patch | `2026.02.01` → `2026.02.07` |
    This PR was generated by [Mend Ren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
2026-02-08 deps: update belfryscad/bosl2 digest to 68bae2d (#225)
    | BelfrySCAD/BOSL2 | digest | `0e03331` → `68bae2d` |
    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
2026-02-09 chore: release main (#223)
    :robot: I have created a release *beep* *boop*
    <details><summary>homeracker: 1.7.4</summary>
    ##
    [1.7.4](https://github.com/kellerlabs/homeracker/compare/homeracker-v1.7.3...homeracker-v1.7.4)
    (2026-02-09)
    ### 🐛 Bug Fixes
    * **renovate:** homeracker preset
    ([48dcc53](https://github.com/kellerlabs/homeracker/commit/48dcc53ef094a57807e42855f9375ece929ef4e2))
    * **renovate:** homeracker preset version extraction
    ([bb4b63f](https://github.com/kellerlabs/homeracker/commit/bb4b63feb385d7b4c94846804fa6e61acb91ec6d))
    ### 📦 Dependencies
    * update belfryscad/bosl2 digest to 0e03331
    ([#220](https://github.com/kellerlabs/homeracker/issues/220))
    ([9a04573](https: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
2026-02-09 deps: update openscad nightly to v2026.02.09 (#227)
    | OpenSCAD-Linux | minor | `2026.01.02.ai30348` → `2026.02.09` |
    | OpenSCAD-Windows | patch | `2026.02.07` → `2026.02.09` |
    🔕 **Ignore**: Close this PR and you won't be reminded about these
    updates again.
    - [ ] <!-- rebase-check -->If you want to rebase/retry this P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
2026-02-14 deps: update openscad nightly to v2026.02.13 (#230)
    | OpenSCAD-Linux | patch | `2026.02.09` → `2026.02.13` |
    | OpenSCAD-Windows | patch | `2026.02.09` → `2026.02.13` |
    - [ ] <!-- rebase-check -->If you want to rebase/retry this PR, check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
2026-02-14 deps: update belfryscad/bosl2 digest to 77004eb (#231)
    | BelfrySCAD/BOSL2 | digest | `68bae2d` → `77004eb` |
    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
2026-02-14 deps: update pre-commit hooks (#232)
    |
    [renovatebot/pre-commit-hooks](https://redirect.github.com/renovatebot/pre-commit-hooks)
    | repository | minor | `43.4.3` → `43.14.1` |
    | [rhysd/actionlint](https://redirect.github.com/rhysd/actionlint) |
    repository | patch | `v1.7.10` → `v1.7.11` |
    Note: The `pre-commit` manager in Renovate is not supported by the
    `pre-commit` maintainers or community. Please do not report any problems
    there, instead [create a Discussion in the Renovate
    repository](https://redirect.github.com/renovatebot/renovate/discussions/new)
    if you have any questions.
    ### Rele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
2026-02-14 deps: update camunda/infra-global-github-actions digest to 0d5665c (#229)
    | camunda/infra-global-github-actions | action | digest | `317ad65` →
    `0d5665c` |
    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
2026-02-15 deps: update camunda/infra-global-github-actions digest to a969eec (#234)
    | camunda/infra-global-github-actions | action | digest | `0d5665c` →
    `a969eec` |
    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
2026-02-15 deps: update belfryscad/bosl2 digest to b4f7ce8 (#235)
    | BelfrySCAD/BOSL2 | digest | `77004eb` → `b4f7ce8` |
    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
2026-02-15 deps: update openscad nightly to v2026.02.15 (#236)
    | OpenSCAD-Linux | patch | `2026.02.13` → `2026.02.15` |
    | OpenSCAD-Windows | patch | `2026.02.13` → `2026.02.15` |
    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
2026-02-21 deps: update belfryscad/bosl2 digest to 095725b (#238)
    | BelfrySCAD/BOSL2 | digest | `b4f7ce8` → `095725b` |
    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
2026-02-21 deps: update camunda/infra-global-github-actions digest to 6501ba0 (#239)
    | camunda/infra-global-github-actions | action | digest | `a969eec` →
    `6501ba0` |
    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
2026-02-21 deps: update openscad nightly to v2026.02.19 (#240)
    | OpenSCAD-Linux | patch | `2026.02.15` → `2026.02.19` |
    | OpenSCAD-Windows | patch | `2026.02.15` → `2026.02.19` |
    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
2026-02-22 deps: update pre-commit hooks (#241)
    | [PyCQA/pylint](https://redirect.github.com/PyCQA/pylint) | repository
    | patch | `v4.0.4` → `v4.0.5` |
    [compilerla/conventional-pre-commit](https://redirect.github.com/compilerla/conventional-pre-commit)
    | repository | minor | `v4.3.0` → `v4.4.0` |
    | repository | minor | `43.15.1` → `43.31.1` |
    there, instead [create a Discu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
2026-02-22 deps: update belfryscad/bosl2 digest to d028c09 (#243)
    | BelfrySCAD/BOSL2 | digest | `095725b` → `d028c09` |
    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
2026-02-28 deps: update belfryscad/bosl2 digest to 83fbdf2 (#245)
    | BelfrySCAD/BOSL2 | digest | `d028c09` → `83fbdf2` |
    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
2026-02-28 deps: update camunda/infra-global-github-actions digest to ddce993 (#246)
    | camunda/infra-global-github-actions | action | digest | `6501ba0` →
    `ddce993` |
    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
2026-02-28 deps: update openscad nightly to v2026.02.25 (#247)
    | OpenSCAD-Linux | patch | `2026.02.19` → `2026.02.25` |
    | OpenSCAD-Windows | patch | `2026.02.19` → `2026.02.25` |
    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
2026-03-01 deps: update openscad nightly to v2026.03.01 (#252)
    | OpenSCAD-Linux | minor | `2026.02.25` → `2026.03.01` |
    | OpenSCAD-Windows | minor | `2026.02.25` → `2026.03.01` |
    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
2026-03-07 deps: update belfryscad/bosl2 digest to eadc19a (#254)
    | BelfrySCAD/BOSL2 | digest | `83fbdf2` → `eadc19a` |
    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
2026-03-07 deps: update camunda/infra-global-github-actions digest to a6b5d34 (#256)
    | camunda/infra-global-github-actions | action | digest | `ddce993` →
    `a6b5d34` |
    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
2026-03-07 deps: update pre-commit hooks (#255)
    | [psf/black](https://redirect.github.com/psf/black) | repository |
    minor | `26.1.0` → `26.3.0` |
    | repository | minor | `43.46.6` → `43.59.2` |
    <det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
2026-03-08 docs: link homeracker-community repo in README and CONTRIBUTING (#258)
    Direct new feature/extension contributions to
    `kellerlabs/homeracker-community`, clarifying this repo is core-only
    (bugfixes + core model improvements).
    ### Changes
    - **`CONTRIBUTING.md`**: New "Contribution Scope" section after intro —
    core repo accepts bugfixes only, new features/extensions → community
    repo. Updated "Getting Help" links accordingly.
    - **`README.md`**: Callout in Open Specs section pointing contributors
    to community repo. Added community repo as first entry in the Community
    links.
    <!-- START COPILOT CODING AGENT TIPS -->
    💬 We'd love your input! Share your thoughts on Copilot coding agent i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
2026-03-15 deps: update belfryscad/bosl2 digest to bfc4e74 (#260)
    | BelfrySCAD/BOSL2 | digest | `eadc19a` → `bfc4e74` |
    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
2026-03-15 deps: update camunda/infra-global-github-actions digest to f5807d2 (#261)
    | camunda/infra-global-github-actions | action | digest | `a6b5d34` →
    `f5807d2` |
    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
2026-03-15 deps: update openscad nightly to v2026.03.14 (#263)
    | OpenSCAD-Linux | patch | `2026.03.01` → `2026.03.14` |
    | OpenSCAD-Windows | patch | `2026.03.01` → `2026.03.14` |
    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
2026-03-15 deps: update pre-commit hooks (#264)
    patch | `26.3.0` → `26.3.1` |
    | repository | minor | `43.59.3` → `43.76.0` |
    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
2026-03-15 chore: release main (#262)
    <details><summary>homeracker: 1.8.0</summary>
    [1.8.0](https://github.com/kellerlabs/homeracker/compare/homeracker-v1.7.8...homeracker-v1.8.0)
    (2026-03-15)
    ### ✨ Features
    * **ci:** switch BOSL2 to release tags & add SessionStart hook
    ([#265](https://github.com/kellerlabs/homeracker/issues/265))
    ([020cf14](https://github.com/kellerlabs/homeracker/commit/020cf1492aba0c00f9e580a832a9cca949b85f2e))
    * **core:** extended lockpin with neck extensions and grip types
    ([#259](https://github.com/kellerlabs/homeracker/issues/259))
    ([4720f98](https://github.com/kellerlabs/homeracker/commit/4720f982537fdbd2fdf97548173c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
2026-03-15 feat(setup-openscad): make action reusable across repositories (#273)
    - Made `setup-openscad` composite action reusable across repositories
    - Added independent release-please versioning for the action (component:
    `setup-openscad`, targets `v1.0.0`)
    - Fixed session-setup hook failing on Windows (`$OS` env var → venv
    layout detection)
    - Added code review + PR creation steps to copilot mandatory workflow
    - Added `feat!`/`fix!` to PR title validation types
    ## 💡 Why
    The `setup-openscad` action was tightly coupled to this repo (local `pip
    install -e cmd/scadm`). Other repos using `scadm` from PyPI couldn't
    reuse it. Independent versioning lets consumers pin to stable tags
    (`se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
2026-03-15 chore: release main (#272)
    <details><summary>homeracker: 1.9.0</summary>
    [1.9.0](https://github.com/kellerlabs/homeracker/compare/homeracker-v1.8.0...homeracker-v1.9.0)
    * **setup-openscad:** make action reusable across repositories
    ([#273](https://github.com/kellerlabs/homeracker/issues/273))
    ([055e784](https://github.com/kellerlabs/homeracker/commit/055e78444f59d351e8a943ab7c8ae04d8c34f259))
    * update pre-commit hook renovatebot/pre-commit-hooks to v43.76.1
    ([#270](https://github.com/kellerlabs/homeracker/issues/270))
    ([5391857](https://github.com/kellerlabs/homeracker/commit/53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
2026-03-19 feat(lockpin): add foot-side neck extension option (#280)
    New lock pin neck extension type: `LP_NECK_EXT_FOOT` (3) — extends only
    the foot side (opposite of grip).
    The existing options cover no extension, grip-side, and both sides — but
    there was no way to extend only the foot side. This completes the set of
    neck extension combinations.
    ## 🔧 How
    - Added `LP_NECK_EXT_FOOT = 3` constant
    - Replaced `>=` cascade logic with explicit `has_grip_neck` /
    `has_foot_neck` booleans in `grip()`, `neck()`, and `end_parts()`
    modules
    - Updated OpenSCAD customizer dropdown: `[0:None, 1:Grip Side, 2:Both
    Sides, 3:Foot Side]`
    - Test renders all 4 types side-by-side
    Usage: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
    [baseplate.scad, binbase.scad, connector.scad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]
2026-03-19 docs: restructure models and update documentation (#281)
    - Restructured model folders to follow `lib/parts/presets/makerworld`
    convention
    - Created/updated READMEs for all model folders to follow the standard
    template
    - Added preview PNGs for all models
    - Added makerworld exports for pinpusher, rackmount_ears, and wallmount
    - Added `.github/instructions/markdown.instructions.md` for consistent
    docs
    - Proofread and fixed root `README.md` (broken links, typos, outdated
    info)
    ### 📁 Structural changes
    - `rackmount_ears.scad` → `rackmount_ears/parts/`
    - `wallmount.scad` → `wallmount/parts/`
    - `pinpusher.scad` → `pinpusher/parts/`
    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
    [pinpusher.scad, rackmount_ears.scad, wallmount.scad]
2026-03-19 feat(export): add per-model checksum caching for makerworld exports (#282)
    Per-model SHA256 checksum caching for makerworld exports. Three
    optimizations:
    1. ⚡ Pre-commit `files` filter — hook only triggers when `models/*.scad`
    or `cmd/export/` files are staged
    2. 🔒 Per-model checksums in `models/.makerworld-checksums` — skip export
    for unchanged models
    3. 🎯 Targeted validation — only render changed makerworld files via
    `openscad-render.sh` instead of full `test-models.sh`
    The `validate-makerworld-exports` pre-commit hook ran unconditionally on
    every commit (`always_run: true`), exporting all models and rendering
    all test + makerworld `.scad` files t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
2026-03-20 feat(scadm): add flatten and render subcommands (#283)
    Add `scadm flatten` and `scadm render` subcommands. Remove legacy shell
    scripts (`export-core-models.sh`, `openscad-render.sh`). Outsource
    copilot instruction files.
    **New:**
    - `cmd/scadm/scadm/flatten.py` — inline OpenSCAD include trees into
    single files with SHA256 checksum caching
    - `cmd/scadm/scadm/render.py` — validate `.scad` files by compiling
    through bundled OpenSCAD binary
    - `cmd/scadm/tests/test_flatten.py` — 4 unit tests for flatten logic
    - `.github/instructions/{openscad,python,renovate}.instructions.md`
    **Removed:**
    - `cmd/export/export-core-models.sh` (replaced by `scadm flatten`)
    - `cmd/test/openscad-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
    [baseplate.scad, binbase.scad, connector.scad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]
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2026-03-20 fix(scadm): sort deps by relative path in compute_checksum (#287)
    🔧 Fix cross-platform checksum mismatch in `compute_checksum` — deps are
    now sorted by POSIX relative path instead of absolute path.
    `compute_checksum` sorted dependency files by absolute path before
    hashing. On Windows, `flatten.py` (in `.venv\...`) sorts **before**
    workspace files. On Linux CI, `flatten.py` (in `/opt/...`) sorts
    **after** workspace files. Different sort order → different SHA256
    digest → `validate-flatten-exports` always fails in CI when checksums
    were generated on a different platform.
    Sort by relative path to workspace root (POSIX format). Files outside
    the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
2026-03-20 chore: release main (#288)
    <details><summary>homeracker: 1.10.2</summary>
    [1.10.2](https://github.com/kellerlabs/homeracker/compare/homeracker-v1.10.1...homeracker-v1.10.2)
    * **scadm:** sort deps by relative path in compute_checksum
    ([#287](https://github.com/kellerlabs/homeracker/issues/287))
    ([b0a6be7](https://github.com/kellerlabs/homeracker/commit/b0a6be7c682728cda729950855bec71ebd473296))
    </details>
    <details><summary>scadm: 0.5.2</summary>
    [0.5.2](https://github.com/kellerlabs/homeracker/compare/scadm-v0.5.1...scadm-v0.5.2)
    * **scadm:** sort deps by relativ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
2026-03-20 fix(scadm): hash flatten.py at fixed position in compute_checksum (#289)
    Hash `flatten.py` at a fixed position (always first) in
    `compute_checksum`, instead of mixing it into the sorted deps set.
    `flatten.py` sort position depended on install location:
    - **Windows** (`.venv/` inside workspace): relative path
    `.venv/Lib/site-packages/scadm/flatten.py` sorted **before**
    `bin/openscad/libraries/...`
    - **Linux CI** (`/opt/hostedtoolcache/...`): fallback key
    `("flatten.py", hash)` sorted **after** `bin/openscad/libraries/...`
    Different order → different SHA256 → `Validate Flatten Exports` CI
    failure on repos with `bin/openscad/libraries/` deps
    (homeracker-exclusiv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
2026-03-20 chore: release main (#290)
    <details><summary>homeracker: 1.10.3</summary>
    [1.10.3](https://github.com/kellerlabs/homeracker/compare/homeracker-v1.10.2...homeracker-v1.10.3)
    * **scadm:** hash flatten.py at fixed position in compute_checksum
    ([#289](https://github.com/kellerlabs/homeracker/issues/289))
    ([a584dc2](https://github.com/kellerlabs/homeracker/commit/a584dc29201019840ca389d2f0420de8b704d136))
    <details><summary>scadm: 0.5.3</summary>
    [0.5.3](https://github.com/kellerlabs/homeracker/compare/scadm-v0.5.2...scadm-v0.5.3)
    * **scadm:** hash flatten.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
2026-03-21 deps: update openscad nightly to v2026.03.20 (#291)
    | OpenSCAD-Linux | patch | `2026.03.14` → `2026.03.20` |
    | OpenSCAD-Windows | patch | `2026.03.14` → `2026.03.20` |
    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
2026-03-22 fix: pinpusher model syntax with invalid trailing comma (#299)
    Syntax error in latest stable openscad release
    Parser stops ("ERROR: Parser error: syntax error in file pinpusher.scad,
    line 66")
    Removed the trailing comma in pinpusher model.
    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
    [pinpusher.scad]
2026-03-22 deps: update openscad nightly to v2026.03.22 (#297)
    | OpenSCAD-Linux | patch | `2026.03.20` → `2026.03.22` |
    | OpenSCAD-Windows | patch | `2026.03.20` → `2026.03.22` |
    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
2026-04-18 feat(flatten): resilient parsing, dead-code elimination, section tolerance (#327)
    Rewrites `scadm flatten` to be resilient against structural
    irregularities and adds dead-code elimination.
    - 🔧 Tolerates section markers (`/* [Name] */`) in library files
    (silently ignored instead of `ValueError`)
    - 🗑️ Dead-code elimination — only transitively used modules, functions,
    and variables are included
    - 💲 `$`-variable support in dependency scanner (`$fn`, `$custom_var`,
    etc.)
    - 🧹 Comment/string stripping — identifiers in comments or string
    literals don't pull in unused definitions
    - 📝 Library variables land in `/* [Hidden] */` with origin comments (`//
    --- from cons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
    [baseplate.scad, binbase.scad, connector.scad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]
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2026-05-24 refactor(core): extract reusable lockpin_hole() module
    - Add lockpin_hole() to core/lib/lockpin.scad using reliable 2-cuboid chamfer
    - Replace inline lockpin holes in connector, sleeve, and supportgrid
    - Respect disable_chamfer flag in sleeve and supportgrid
    - Add dark model colorscheme guidance to OpenSCAD instructions
    [connector.scad]
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2026-05-31 feat(keystone): add dimensions helper, label plate modes, and shorten inner hooks (#385)
    - Add `get_keystone_dimensions()` function returning `[width, depth,
    height]` vector
    - Add `label_plate_mode` and `label_plate_gap` params to
    `keystone_full()` and `keystone_demo_panel()`
    - Support `"plate"` mode: orients label plates flat above the panel for
    build-plate layout
    - Shorten inner label hooks (`inner=true`) to half height for easier
    label plate insertion
    🔧 `get_keystone_dimensions()` enables downstream assembly modules
    (keystonepanel) to compute layout without duplicating dimension logic.
    🖨️ Plate mode allows rendering label plates on the same build plate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
    [keystone.scad]
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2026-06-07 feat(panel): split panels, back-brace stiffener & panel depth (#393)
    A weekend of rack-panel work that makes large panels printable and
    stiff. 🚀
    - ✂️ **Split panels** — divide a 19" panel along its centerline into two
    printable halves joined by a hinge-knuckle **split connector** and a
    single **split lock pin** (no glue/fasteners). New `lib/split.scad`,
    parts `split_connector.scad` + `split_lockpin.scad`, point-symmetric
    4-knuckle/HU layout, plus `view_mode` previews (assembled with seated
    pin / exploded).
    - 💪 **Back-brace truss stiffener** — optional triangulated
    (Warren/zigzag) lattice grown on the panel back, flush with the knuckle
    plane. New generic, dimensio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
    [lockpin.scad, rackpanel.scad, split.scad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]
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2026-06-13 feat(keystone): add label_position above/below for label slots (#396)
    Adds a new `label_position` parameter (`"above"` default, `"below"`) to
    the keystone library:
    - 🔧 `keystone_full()`, `keystone_demo_panel()`, and `label_recess()` now
    accept `label_position`.
    - ⬇️ `"below"` mirrors the label recess, snap-fit hooks, and label plate
    to the **underside** of the jack — correctly flipping the
    rotation-dependent slot offset and the assembly/plate label placement.
    - ✅ Default behavior (`"above"`) is byte-identical to before.
    - 🎛️ Exposed in the `keystone_sample` part Customizer (`label_position`
    selector).
    - 🧪 Covered by the keystone test file (0°, 90°, and dem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
    [keystone.scad, keystone_sample.scad]
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2026-06-14 feat(panel): expose rackpanel usable-frame helpers + child passthrough (#399)
    Makes `rackpanel` build-on-able so specialized panels (e.g. keystone
    rack panels in homeracker-exclusive) can add/subtract geometry on the
    panel face — including its split halves.
    - 🧩 **Child passthrough** on the Full / Half-Left / Half-Right views via
    one outer `attachable` that emits `children()` **outside** the internal
    `tag_scope`, so `diff("keystone")` cutters survive. `anchor/spin/orient`
    now apply on every child-accepting view (previously Full only).
    - 📐 **Two pure helpers** describing the cutout-safe band (panel face
    minus the rackmount mount-surface columns + slide-in clearance):
    -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
    [keystones_on_full.scad, keystones_on_split.scad, rackpanel.scad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]
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2026-06-20 fix(panel): rename lockpin_hole to panel_lockpin_hole to avoid name collision (#406)
    Rename the **panel-local** `lockpin_hole` module to `panel_lockpin_hole`
    in [`models/panel/lib/panel.scad`](models/panel/lib/panel.scad)
    (definition + 6 internal call sites), and add a regression test that
    puts both this and the reusable `core/lib/lockpin.scad`'s
    `lockpin_hole(depth=…)` in scope at once.
    Two `lockpin_hole` modules quietly coexisted in homeracker:
    | File | Signature | Purpose |
    | `models/panel/lib/panel.scad` | `lockpin_hole(anchor, spin, orient,
    debug_colors, chamfer_enabled)` | Shallow panel-side passthrough for
    mount plates |
    | `models/core/lib/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
    [lockpin_collision.scad]
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2026-07-10 fix: flatten
    [baseplate.scad, binbase.scad]
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2026-09-05 feat: add a 3d configurator and rework github pages (#460)
    📦 What
    Adds a web configurator for HomeRacker and a project site to host it.
    The configurator lets you design racks in the browser with a form, 3D
    preview, and a bill of materials. Configs are shareable via URL and
    survive page reloads. The site replaces the old GitHub Pages setup and
    doubles as a model catalog built from the repo READMEs. CI covers both.
    💡 Why
    There was no way to plan a rack without mentally counting parts and
    guessing dimensions. A browser tool that shows the 3D result and spits
    out a parts list removes that friction. Bundling it with the docs site
    means one fewer thing to deploy and one URL to bookmark.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
    [panel_kit.scad]
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2026-09-20 feat: add bracket model and retire flexmount (#496)
    Adds `models/bracket/`, a clamp that wraps a device from above or below
    and hangs it in a HomeRacker frame via lock pins. Moved out of
    `homeracker-exclusive`, MIT-licensed, with lib, parts, test, renders and
    README.
    Removes `models/flexmount/`. The bracket supersedes it.
    Flexmount was this repo's open-source universal device mount. It was
    deprecated once the closed Unimount took over the job, which left
    HomeRacker without a device mount anyone could build from source. The
    bracket is the part that replaced it, so bringing it back restores in
    support what flexmount used to provide.
    Full rationale, including what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
    [bracket.scad, flexmount.scad]
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2026-09-28 feat(scadfmt): format all .scad files and enforce it in pre-commit (#524)
    - New `scadfmt` pre-commit hook: it formats staged `.scad` files.
    pre-commit fails the commit when a file changed, like `flatten-validate`
    does. It skips generated `flattened/` output and the deliberately
    unformatted canary input.
    - Every `.scad` file in the repo is formatted (62 files), and
    `flattened/` is regenerated with `scadm flatten --all` (9 files).
    - New
    [`ast_check.sh`](https://github.com/kellerlabs/homeracker/blob/main/cmd/scadfmt/tests/ast_check.sh)
    runs in the `integration tests (OpenSCAD)` job: every `.scad` file whose
    change in the PR is formatting only must give the pinned OpenSCAD the
    same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
    [adapter.scad, baseplate.scad, binbase.scad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]
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

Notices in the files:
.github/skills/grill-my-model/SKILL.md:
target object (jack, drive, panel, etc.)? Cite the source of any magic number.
